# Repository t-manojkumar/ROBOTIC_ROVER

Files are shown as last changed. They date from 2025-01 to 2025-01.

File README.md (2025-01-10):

# ROBOTIC_ROVER
The project is designed to develop a Robotic Rover vehicle with  a soft holding gripper. It can be used for pick and place of an object.  It can sense whether the object picked is metallic or non-metallic. It  can also detect the rover is in gaseous surrounding or not. It can also tell the  temperature and humidity level.

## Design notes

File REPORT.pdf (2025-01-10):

1
DIPLOMA IN MECHATRONICS-NEC

## 1.0 INTRODUCTION

The project is designed to develop a Robotic Rover vehicle with

a soft holding gripper. It can be used for pick and place of an object.

It can sense whether the object picked is metallic or non-metallic. It

can also detect the rover is in gaseous surrounding or not (LPG, I-

Butane, Methane, Hydrogen, Alcohol, smoke). It can also tell the

temperature and humidity level. The robotic vehicle is controlled by

an android application for remote operation.

At the transmitting end using an Android application device,

commands are sent to the receiver to control the movement of the

robot to move forward, backward, and left or right. The android

application device transmitted acts as a remote control that has the

advantage of a certain range, while the receiver end is fed to the

micro controller to drive DC motors via motor driver IC for necessary

work. Remote operation is achieved by any smart-phone/Tablet, etc.

The main advantage of this robot is its holding arm, which is designed

to avoid extra pressure on the suspected object for safety reasons. A

Rover is the one which is used to pick up an object and place it in the

desired location. It is an articulated Robotic Rover, which contains a

fixed robot with 3 vertical axes and rotary arms.

Manipulator is the main body of the vehicle which consisting

of several joints and links

DIPLOMA IN MECHATRONICS - NEC | 2

ROBOTIC ROVER

## 2.0 PROECT BRIEF

AIM

To design and build a Robotic Rover.

OBJECTIVES

- To design a speed control system for the Robotic Rover
- Pick and place the objects using manipulator
- To implement wireless android application to control the Robotic

Rover

- To detect gases in surrounding (LPG, I-Butane, Methane, Hydro

gen, Alcohol)

- To display temperature and humidity level
- To sense whether the object is metallic or non-metallic

### 3.0 PROJECT TARGET

To create a wireless based Robotic Rover which can move an

object from one place to another place and also to an unsustainable

condition or environment.

- To Reduce the human effort
- Pick and Place the required component
- Easy to implement
- Low maintenance

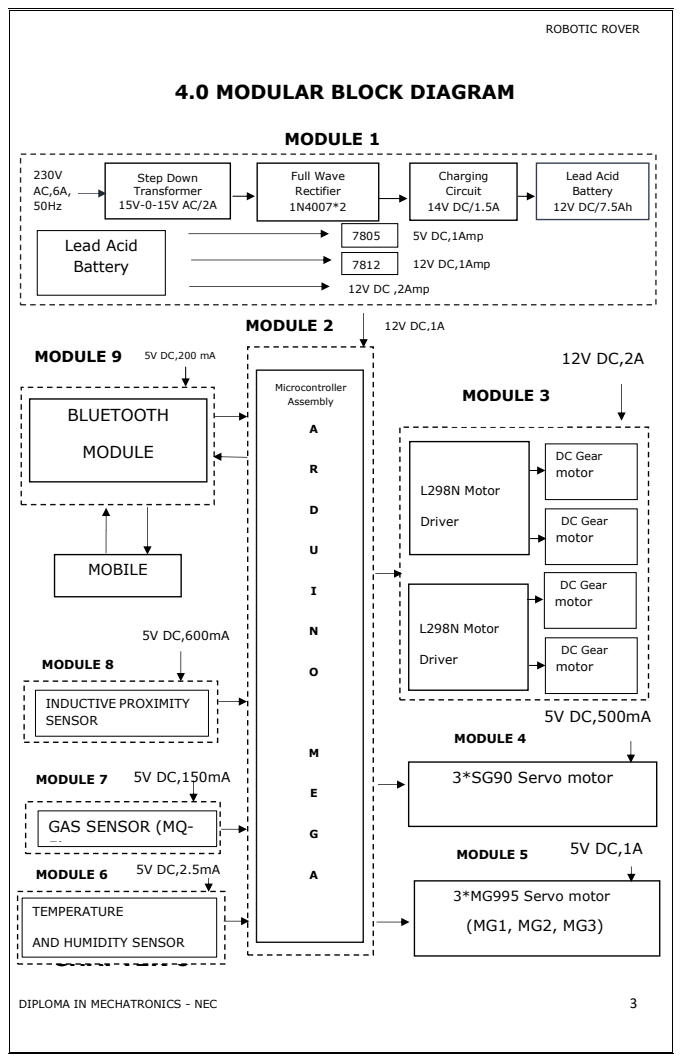
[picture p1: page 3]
DIPLOMA IN MECHATRONICS - NEC; MODULE 1; 12V DC,1Amp; Microcontroller Assembly; BLUETOOTH; MODULE; L298N Motor; Driver; 3*SG90 Servo motor; 3*MG995 Servo motor; MODULE 5; MODULE 4; MOBILE; MODULE 8; INDUCTIVE PROXIMITY SENSOR; MODULE 7; MODULE 6; TEMPERATURE; Step Down Transformer 15V-0-15V AC/2A; Full Wave Rectifier 1N4007*2; Charging Circuit 14V DC/1.5A; Lead Acid Battery 12V DC/7.5Ah; 7805 Lead Acid; Battery; 12V DC ,2Amp; 5V DC,1Amp; MODULE 9; MODULE 2; DC Gear motor; MODULE 3

4.0 MODULAR BLOCK DIAGRAM

GAS SENSOR (MQ-

AND HUMIDITY SENSOR
CHAPTER 6

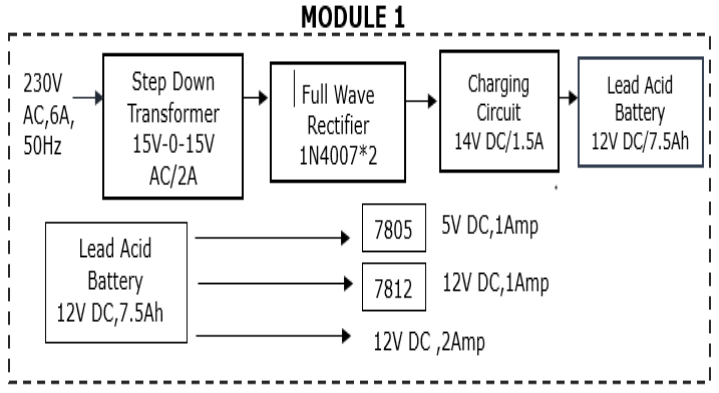
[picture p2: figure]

DIPLOMA IN MECHATRONICS - NEC | 4

## 5.0 POWER SUPPLY & CHARGING CIRCUIT

### 5.1 DESCRIPTION

Step down transformer gives 15V-0-15V/2A AC to the

center tap full wave rectifier formed by diodes D1, D2. Rectifier

will convert 30V AC to 19V DC. Capacitor C1 is introduced to filter

the ripples of converted DC, so it used as filter as well as backup

capacitor. To remove the ripple voltage. The Rectifier is connected

to the capacitors 1000uf,50V and they are connected to regulator

LM317 for regulating the voltage to 13.5v for charging the battery

and a freewheeling is used to stop the back current from the

battery to protect the circuit. In this circuit we are used auto

cutoff system to overcome the problem of overcharging.

### 5.2 BLOCK DIAGRAM

DIPLOMA IN MECHATRONICS - NEC | 5

## BLOCK DIGRAM DESCRIPTION

INPUT

The input 230V/50Hz is given to the transformer.

STEPDOWN TRNSFORMER

A Step-Down Transformer is a device which converts high

primary voltage to a low secondary voltage. In a Step-Down

Transformer, the primary winding of a coil has more turns than the

secondary winding.

CENTER-TAP FULL WAVE RECTIFIER

A Full Wave Rectifier is a circuit, which converts an ac

voltage into a pulsating dc voltage using both half cycles of the

applied ac voltage. It uses two diodes of which one conducts during

one half cycle while the other conducts during the other half cycle of

the applied ac voltage.

FILTER

The pulsating output of the rectifiers has an average DC

value and an AC portion that is called ripple voltage. Filter capacitors

reduce the amount of ripple voltage to a level that is acceptable.

REGULATOR

We are using regulator ICs to maintain a constant output

voltage in a power supply circuit. We are using regulator IC LM317

for getting 13V respectively through variable resistor to this we are

connected to the battery.

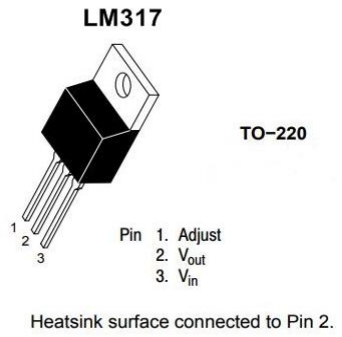
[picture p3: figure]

DIPLOMA IN MECHATRONICS - NEC | 6

For 12V,1Amp supply we are using 7812 for getting 12V

respectively, and for 5V,1Amp supply we are using 7805 for getting

5V respectively.

LM317

The LM317 is an adjustable 3−terminal positive voltage

regulator capable of supplying in excess of 1.5 A over an output

voltage range of 1.2 V to 37 V. This voltage regulator is exceptionally

easy to use and requires only two external resistors to set the output

voltage.

Features

- Output Voltage Range Adjustable From 1.25 V to 37 V
- Output Current Greater Than 1.5 A
- Internal Short-Circuit Current Limiting
- Thermal Overload Protection
- Output Safe-Area Compensation

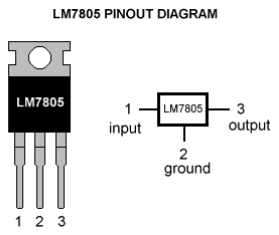
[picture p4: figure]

DIPLOMA IN MECHATRONICS - NEC | 7

LM7805

7805 is a 5V fixed three terminal positive voltage regulator IC.

The IC has features such as safe operating area protection, thermal

shut down, internal current limiting which makes the IC very rugged.

Output currents up to 1A can be drawn from the IC provided that

there is a proper heat sink.

Features

- 5V Positive Voltage Regulator
- Minimum Input Voltage is 7V
- Maximum Input Voltage is 25V
- Operating current (IQ) is 5mA
- Internal Thermal Overload and Short circuit current limiting

protection is available.

- Junction Temperature maximum 125 degree Celsius
- Available in TO-220 and KTE package

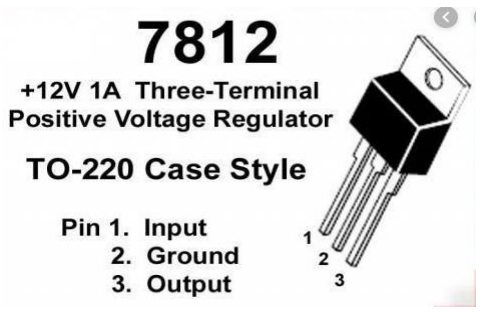
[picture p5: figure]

DIPLOMA IN MECHATRONICS - NEC | 8

LM7812

7812 is a 12V fixed three terminal positive voltage

regulator IC. The IC has features such as safe operating area

protection, thermal shut down, internal current limiting which makes

the IC very rugged. Output currents up to 1A can be drawn from the

IC provided that there is a proper heat sink.

Features

- Fixed voltage linear regulator
- 14-35V input voltage range
- 12V fixed output voltage
- 1A continuous current
- TO-220 package

Output:

The output of power supply is 12VDC/1A.

The output of power supply is 5 VDC/1A.

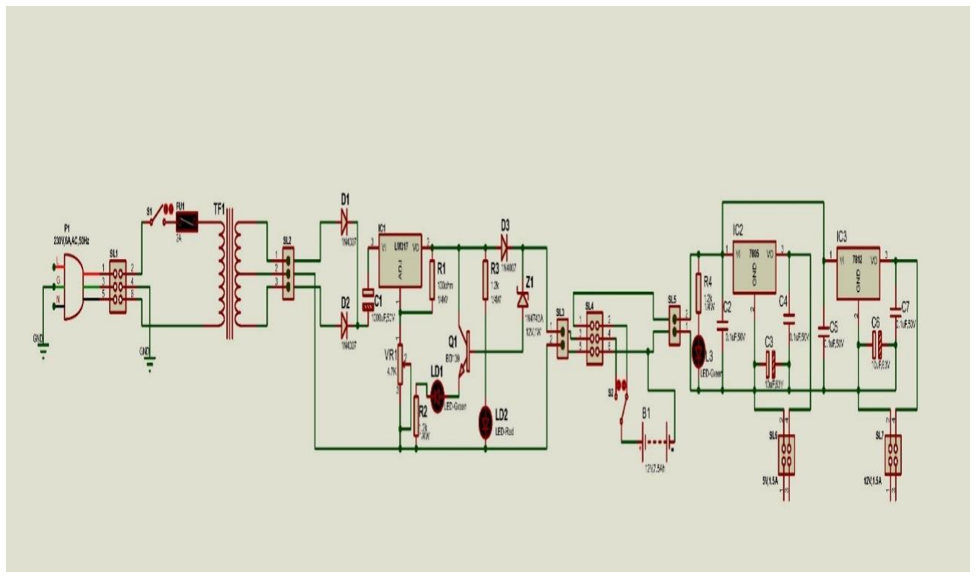
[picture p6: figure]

DIPLOMA IN MECHATRONICS - NEC | 9

## 5.3 SCHEMATIC DIAGRAM

## 5.4 DESIGN

CHARGING CIRCUIT REQUIREMENTS:

Voltage = 15V DC

Current = 1A

TRANSFORMER SPECFICATION:

Voltage =15V-0-15V AC

Current =2A

DIPLOMA IN MECHATRONICS - NEC | 10

For Center Tap Full Wave Rectifier:

VDC = Pulsating DC Voltage (Volts)

Vmax = V peak Voltage (Volts)

VDC = 2xVmax/ϖ

VDC =0.636xVmax

VDC =0.636x30

VDC=19.108V

As per the data sheet the Diode is 1N4007

Iout = Output Current (Amp)

Iout = 1A

In center tap full wave rectifier the frequency gets double

F=2 x F

Value of the capacitor:

C = Iout/F x Vripple

Vripple =20% of VDC

C = 1Amp/100HzX0.95

C = 950 µf

C =~ 1000 µf

DIPLOMA IN MECHATRONICS - NEC | 11

Working Voltage of Capacitor:

V1 = Operating /Working Voltage

V1 =DC Voltage +25% (extra 25% for reduce the ripple voltage)

= 19+4.75

= 23.75

= 24V

Capacitor standard Voltage we are consider 50V

V1=50V

VOLTAGE REGULATOR LM317:

Consider:

Vin = 19V

Vout = Output Voltage(Volts)

R1=100 Ω

R2=70 Ω

Vout = 1.25 (R1/R1+R2) Vin

= 1.25(100Ω/100 Ω +70 Ω) Vin

= 1.25(100Ω/100 Ω +70 Ω) X19V

= 1.25 X 11,1764

= 13.97V

Vout=~14V

DIPLOMA IN MECHATRONICS - NEC | 12

For R2, R3, R4 (Ohm’s Law)

R = V/I

R = 14/20mA

R = 0.7 X 1000

R = 700 Ω

Power Rating for Resistor:

I = 20mA

V = 14V

P = V x I

= 14(20mA)

= 280 x 10^-3

= 0.28 W

P =~0.25W

For Heatsink:

PD = (Vin-Vout) X I out

PD = power dissipation (Watt)

Vin = Input voltage (Volts)

Vout = output voltage (Volts)

Iout = output current (Amp)

DIPLOMA IN MECHATRONICS - NEC | 13

PD = (19-14V) X 1Amp

= 5W

θJA = Total junction to ambient thermal resistance (˚C/W)

TJ =Junction temperature (˚C)

TA = Ambient temperature (˚C)

θJA (total) = TJ-TA/PD

= 125˚C -23 ˚C/5W

= 102/5W

θJA=20.4 ˚C/W

DIPLOMA IN MECHATRONICS - NEC | 14

## 5.5 BILL OF MATERIALS

MODULES

Sl.no | Item description | Symbol | Qty | Price(₹)
| (i) 3 core patch chord 230V AC,6A,50Hz | P1 | 1 | 50
| (ii) Connector 6 pin Poly carbonate,10A | SL1, SL4 | 2 | 12
| (iii) Connector 3 pin Poly carbonate,10A | SL2 | 1 | 3
| (iv) Connector 2 pin Poly carbonate,5A | SL3, SL5, SL6, SL7 | 4 | 8
| (v) Switch (Rocker SPST) 230V AC,6A | S1 | 1 | 20
| (vi)Fuse & Fuse holder (Glass Catridge Fuse 2A, Fuse holder round screw,6A, AC) | FU1 | 1 | 50

Module 1

(Power

Supply &

Charging

Circuit)

DIPLOMA IN MECHATRONICS - NEC | 15
(vii) Transformer Center Tap (15-0-15)V AC,2A | TF1 | 1 | 250
(viii) Diode: 1N4007 Axial Type | D1, D2, D3 | 3 | 9
(ix)Electrolytic Capacitor (50V,1000uf) Radial Type | C1 | 1 | 8
(x) Carbon film Resistor (10k,1/4W CFR, ±5%) | R1, R2, R3, R4 | 4 | 4
(xi) Trimpot (10k,1/2W) | VR1 | 1 | 10
(xii)LM317 | IC1 | 1 | 15
(xiii) Heat sink: E3A-T220-25E | - | 3 | 45
(xiv) NPN Transistor: BD139 | Q1 | 1 | 10
(xv) Zener Diode: 1N4742 Axial Type | Z1 | 1 | 2
(xvi) LED 5mm radial type (3V,20mA) | LD1, LD2, LD3 | 3 | 10

DIPLOMA IN MECHATRONICS - NEC | 16
(xvii) Lead Acid Battery (12V,7.5Ah) | B1 | 1 | 700
(xviii)Ceramic Capacitor (104) Radial Type (50V,0.1uf) | C2, C4, C5, C7 | 4 | 4
(xix) Electrolytic Capacitor (63V,10uf) Radial Type | C3, C6 | 2 | 12
(xx) DC +ve Regulator 7805,1A | IC2 | 1 | 10
(xxi) DC +ve Regulator 7812,1A | IC3 | 1 | 10
(xxii) Toggle switch: SPDT, SDT-106D-0-1(6A,125VAC) | S2 | 1 | 30
TOTAL | | | 1282

DIPLOMA IN MECHATRONICS - NEC | 17

## 6.0 MICROCONTROLLER ASSEMBLY MODULE

## 6.0 ARDUINO MEGA 2560

### 6.1 DESCRIPTION

The Arduino MEGA 2560 is designed for projects that require

more I/O lines, more sketch memory and more RAM. With 54 digital

I/O pins, 16 analog inputs and a larger space for your sketch it is the

recommended board for 3D printers and robotics projects. The

Arduino Mega 2560 is programmed using the software (IDE) our

Integrated Development Environment common to all our boards and

running both online and offline.

### 6.2 FEATURES OF ARDUINO MEGA 2560

- The ATmega2560 is a Microcontroller
- The operating voltage of this microcontroller is 5volts
- The recommended Input Voltage will range from 7volts to 12volts
- The input voltage will range from 6volts to 20volts
- The digital input/output pins are 54 where 15 of these pins will

supply PWM o/p.

- Analog Input Pins are 16
- DC Current for each input/output pin is 40 mA
- DC Current used for 3.3V Pin is 50 mA
- Flash Memory like 256 KB where 8 KB of flash memory is used with

the help of bootloader

- The static random access memory (SRAM) is 8 KB
- | The | electrically | erasable | programmable | read-only | memory

(EEPROM) is 4 KB

- The clock (CLK) speed is 16 MHz
- The USB host chip used in this is MAX3421E

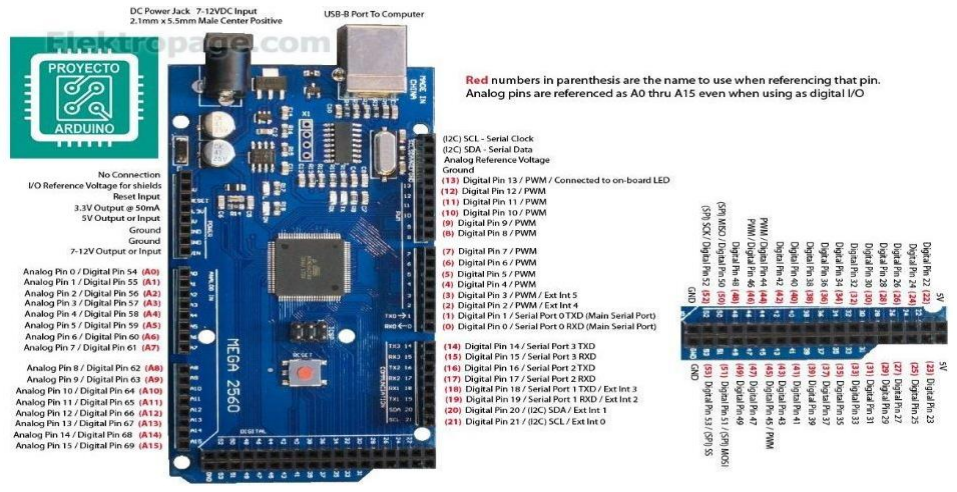
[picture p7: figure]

DIPLOMA IN MECHATRONICS - NEC | 18

### 6.3 PIN CONFIGURATION:

PIN DIAGRAM EXPANATION:

POWER PINS:

VIN: The input voltage to the Arduino board when it's using an

external power source can supply voltage through this pin, or, if

supplying voltage via the power jack, access it through this pin.

5V: The regulated power supply used to power the microcontroller

and other components on the board. This can come either from VIN

via an on-board regulator, or be supplied by USB or another

regulated 5V supply.

3V3: A 3.3 volt supply generated by the on-board regulator.

Maximum current draw is 50 mA.

GND: Ground pins.

MEMORY:

The ATmega2560 has 256 KB of flash memory for storing code of

which 8 KB is used for the bootloader, 8 KB of SRAM and 4 KB of

EEPROM

DIPLOMA IN MECHATRONICS - NEC | 19

INPUT AND OUTPUT

Each of the 54 digital pins on the Mega can be used as an input or

output, using pinMode(), digitalWrite(), and digitalRead() functions.

They operate at 5 volts. Each pin can provide or

receive a maximum of 40 mA and has an internal pull-up resistor

of 20-50 kOhms. In addition, some pins have specialized functions

- Serial: 0 (RX) and 1 (TX); Serial 1: 19 (RX) and 18 (TX);

Serial 2: 17 (RX) and 16 (TX); Serial 3: 15 (RX) and 14 (TX).

Used to receive (RX) and transmit (TX) TTL serial data. Pins 0 and 1

are also connected to the corresponding pins of the ATmega8U2 USB-

to-TTL Serial chip.

- External Interrupts: 2 (interrupt 0), 3 (interrupt 1), 18

(interrupt 5),19 (interrupt 4), 20 (interrupt 3), and 21

(interrupt 2). These pins can be configured to trigger an interrupt

on a low value, a rising or falling edge, or a change in value. See the

attachInterrupt() function for details.

- PWM: 0 to 13. Provide 8-bit PWM output with the analogWrite()

function.

- SPI: 50 (MISO), 51 (MOSI), 52 (SCK), 53 (SS).

These pins support SPI communication using the SPI library. The SPI

pins are also broken out on the ICSP header, which is physically

compatible with the Uno, Duemilanove and Diecimila.

- LED: 13. There is a built-in LED connected to digital pin 13. When

the pin is HIGH value, the LED is on, when the pin is LOW, it's off.

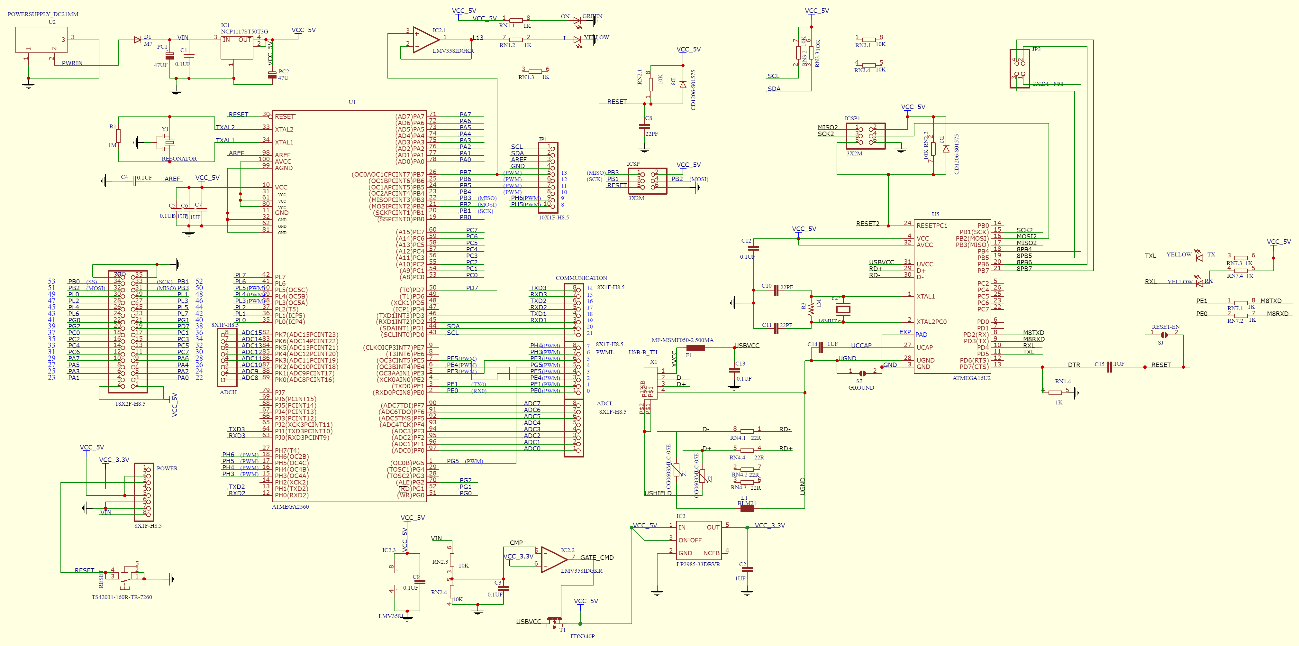
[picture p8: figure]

DIPLOMA IN MECHATRONICS - NEC | 20
- I2C: 20 (SDA) and 21 (SCL). Support I2C (TWI) communication

using the Wirelibrary.

The Mega2560 has 16 analog inputs, each of which provide 10 bits of

resolution. By default they measure from ground to 5 volts, though is

it possible to change the upper end of their range using the AREF pin

and analogReference() function.

There are a couple of other pins on the board:

- AREF. Reference voltage for the analog inputs. Used with

analogReference().

- Reset. Bring this line LOW to reset the microcontroller. Typically

used to add a reset

button to shields which block the one on the board.

### 6.4 SCHEMATIC DIAGRAM:

DIPLOMA IN MECHATRONICS - NEC | 21

### 6.5 BILL OF MATERIAL

SL NO | Item description | symbol | Qty | Price(₹)
1 | ATMEGA2560 | U1 | 1 | 27
2 | POWERSUPPLY_DC21MM | U2 | 1 | 19
| 47UF | PC1 | 1 | 3
4 | 0.1UF | C1, C4, C5, C6, C7, C3, C9, C12, C13, C15 | 10 | 7
5 | RESONATOR | Y1 | 1 | 5
6 | NCP1117ST50T3G | IC1 | 1 | 6
7 | 1M | R1, R3 | 2 | 3
8 | M7 | D1 | 1 | 6
9 | 18X2F-H8.5 | XIO | 1 | 6
10 | 8X1F-H8.5 | POWER, ADCH, COMMUNICATION, PWML, ADCL | 5 | 20
11 | TS42031-160R-TR-7260 | RESET | 1 | 5
12 | 10X1F-H8.5 | JP1 | 1 | 6

DIPLOMA IN MECHATRONICS - NEC | 22
13 | CD1206-S01575 | D3, D2 | 2 | 8
14 | 22PF | C8, C10, C11 | 3 | 3
15 | 3X2M | ICSP, ICSP1 | 2 | 8
16 | 1UF | C2, C14 | 2 | 2
17 | LP2985-33DBVR | IC3 | 1 | 9
18 | FDN340P | T1 | 1 | 50
19 | 2X2M – NM | JP2 | 1 | 33
20 | 16MHZ | Y2 | 1 | 19
21 | USB-B_TH | X1 | 1 | 80
22 | MF-MSMF050-2 500MA | F1 | 1
23 | CG0603MLC-05E | Z1, Z2 | 2 | 49
24 | BLM21 | L1 | 1 | 12
25 | SJ | GROUND, RESET-EN | 2 | 30
26 | ATMEGA16U2 | U5 | 1 | 16
27 | 47U | PC2 | 1 | 17

DIPLOMA IN MECHATRONICS - NEC | 23
28 | GREEN | ON | 1 | 2
29 | YELLOW | L, TX, RX | 3 | 2
30 | 1u (https://easyeda.com/component/994f4acf33ff4e66aaa5dbbeb5e3fa4f) | C16, C18 | 2 | 1
31 | 1u (https://easyeda.com/component/73cf4db60ff344f8a415b734dfaec7a1) | C17, C19 | 2 | 2
32 | 1N4448 (https://easyeda.com/component/1f840c1ab0fc8dd5c06f5170f6febdd2) | D4, D5 | 2 | 8
33 | 1k (https://easyeda.com/component/5ba509f895244278a1309c0031b47188) | R2, R4 | 2 | 2
34 | Оптопара (https://easyeda.com/component/901765d22a3f4b5bbb75a09bf7adf945) | U3, U4 | 2 | 26
35 | BC847AWT1G (https://easyeda.com/component/1e5139edd73d4da4b58b2ce887ac698c) | Q1, Q2 | 2 | 50
36 | LMV358IDGKR | IC2 | 1 | 69
37 | 1K | RN1, RN7 | 2 | 12
38 | 10K | RN2, RN3 | 2 | 12
39 | 22R | RN4 | 1 | 12
TOTAL | | | 700

DIPLOMA IN MECHATRONICS - NEC | 24

## 7.0 JOHNSON MOTOR WITH L298N MOTOR

## DRIVER

### 7.1 DESCRIPTION

L298N MOTOR DRIVER

This dual bidirectional motor driver, is based on the very

popular L298 Dual H-Bridge Motor Driver Integrated Circuit. The circuit

will allow you to easily and independently control two motors of up to

2A each in both directions. It is ideal for robotic applications and well

suited for connection to a microcontroller requiring just a couple of

control lines per motor. It can also be interfaced with simple manual

switches, TTL logic gates, relays, etc. This board equipped with power

LED indicators, on-board +5V regulator and protection diodes.

FEATURES

- Input Voltage: 3.2V~40Vdc. Brief Data:
- Driver: L298N Dual H Bridge DC Motor Driver
- Power Supply: DC 5 V - 35 V
- Peak current: 2 Amp
- Operating current range: 0 ~ 36mA
- Low: -0.3V ≤ Vin ≤ 1.5V.
- High: 2.3V ≤ Vin ≤ Vss.
- Maximum power consumption: 20W (when the temperature

T = 75 ℃).

DIPLOMA IN MECHATRONICS - NEC | 25

JOHNSON MOTOR:

It is a simple DC motor (https://robu.in/product-category/motor/) featuring metal gearbox for driving the

shaft of the motor, so it is a mechanically commutated electric motor

which is powered from DC supply. The Johnson Geared Motors (https://robu.in/product-tag/johnson-motor/) are

known for their compact size and massive torque-speed characteristic.

The Johnson Motor (https://robu.in/product-tag/johnson-motor/) comes with side shaft also known as an off-

centered shaft and six M3 mounting holes. The shaft of the motor

equips metal bushes which makes these DC gear motors Shaft wear

resistant. The shaft of the motor has a hole for better coupling.

FEATURES:

- 10RPM 12V DC motors with Metal Gearbox and Metal Gears
- 18000 RPM base motor
- 6mm Dia shaft with M3 thread hole
- Gearbox diameter 37 mm.
- Motor Diameter 28.5 mm
- Length 63 mm without shaft
- Shaft length 30mm
- 180gm weight
- 120kgcm Holding Torque
- No-load current = 800 mA, Load current = upto 7.5 A(Max)
- Recommended to be used with DC Motor Driver 20A (https://robokits.co.in/shop/index.php?main_page=product_info&cPath=73&products_id=334) or Dual DC

Motor Driver 20A (https://robokits.co.in/shop/index.php?main_page=product_info&cPath=73&products_id=342)

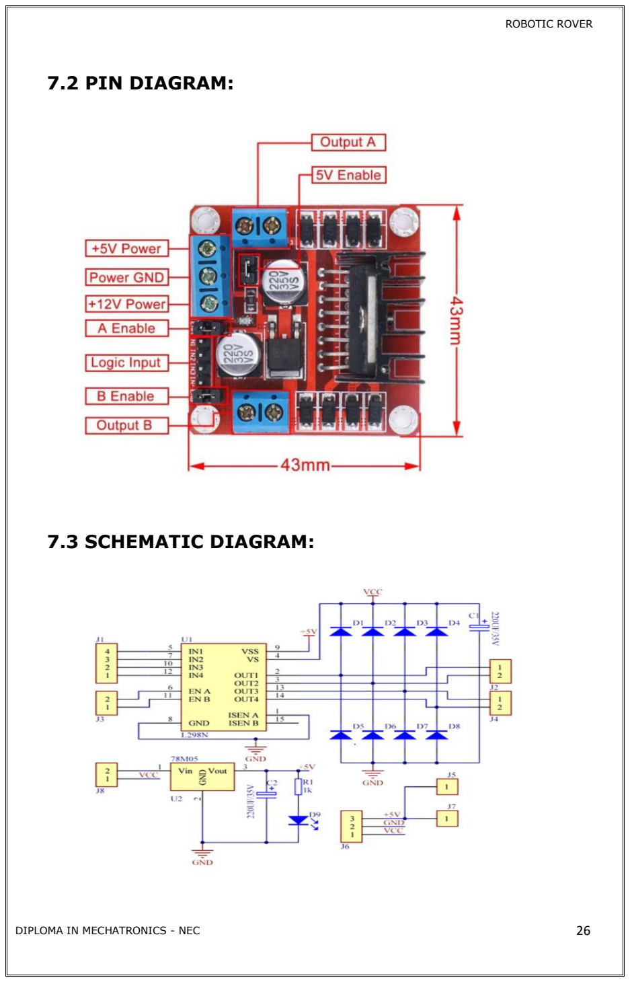
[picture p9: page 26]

DIPLOMA IN MECHATRONICS - NEC | 26

### 7.2 PIN DIAGRAM:

### 7.3 SCHEMATIC DIAGRAM:

DIPLOMA IN MECHATRONICS - NEC | 27

### 7.4 BILL OF MATERIALS:

SL.NO | Item Description | Symbol | Qty | Price (₹)
1 | L298 | U2 | 1 | 20
2 | L297DIL20-1 | U1 | 1 | 5
3 | KF301-5.0 2P | J3, J4, J5, J6, J7, J8 | 5 | 20
4 | LM7805EE | U3 | 1 | 50
5 | 470uf | C1 | 1 | 2
6 | 220uf | C2 | 1 | 2
7 | PIN 3 | J1, J2 | 2 | 10
8 | 10k | R1, R2 | 2 | 2
9 | CAP 0805 | C4, C3 | 2 | 8
10 | 22uf | C5 | 1 | 2
11 | 1N4007 | D1, D2, D3, D4, D5, D6, D7, D8 | 8 | 15
12 | 1 Ohm | R4, R10 | 2 | 3
13 | 22k | R5, R7 | 2 | 3
14 | 332 uf | C7 | 1 | 3
15 | 5kOhm | R6 | 1 | 2
TOTAL | | | | 147

DIPLOMA IN MECHATRONICS - NEC | 28

TOTAL BILL OF MATERIALS:

SL.NO | Item Description | Symbol | Qty | Price (₹)
1 | Motor Driver (L298N) | L1 | 1 | 147
2 | Johnson Motor | M1 | 1 | 150
TOTAL | | | | 297

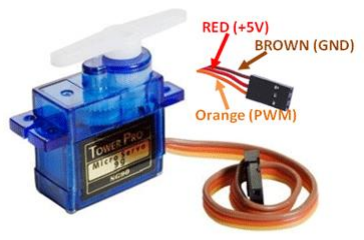
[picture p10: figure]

DIPLOMA IN MECHATRONICS - NEC | 29

## 8.0 SG-90 SERVO MOTOR

### 8.1 DESCRIPTION

The TowerPro SG90 9g Mini Servo is 180° rotation servo. It is a

Digital Servo Motor which receives and processes PWM signal faster

and better. It equips sophisticated internal circuitry that provides good

torque, holding power, and faster updates in response to external

forces.

### 8.2 PIN DIAGRAM:

### 8.3 FEATURES

- Operating Voltage is +5V typically
- Torque: 2.5kg/cm
- Operating speed is 0.1s/60°
- Gear Type: Plastic
- Rotation: 0°-180°
- Weight of motor: 9gm

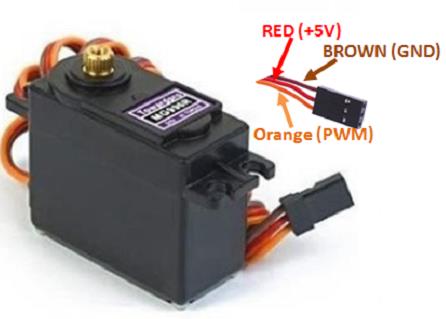
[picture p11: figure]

DIPLOMA IN MECHATRONICS - NEC | 30

### 8.4 BILL OF MATERIALS

SL.NO | Item Description | Symbol | Qty | Price (₹)
1 | Servo Motor (SG-90) | SM1, SM2 | 2 | 150X2
TOTAL | | | | 300

*

## 9.0 MG995 SERVO MOTOR

### 9.1 DESCRIPTION

The high-speed standard servo can rotate approximately 120

degrees (60 in each direction). We can use any servo code, hardware

or library to control these servos, so gear box, especially since it will fit

in small places. It equips sophisticated internal circuitry that provides

good torque, holding power, and faster updates in response to external

forces.

### 9.2 PIN DIAGRAM

DIPLOMA IN MECHATRONICS - NEC | 31

PIN CONFIGURATION:

MG995 has three terminals as mentioned in pin diagram and the function of each pin is given below.

Pin | Name | Function
1 | Signal pin (Orange pin) | The PWM signal which states the axis position is given through this pin.
2 | VCC (Red pin) | Positive power supply for servo motor is given to this pin.
3 | Ground (Brown pin) | This pin is connected to ground of circuit or power supply.

### 9.3 FEATURES:

- Weight: 55g
- Dimension: 40.7 × 19.7 × 42.9 mm
- Operating Speed (4.8V no load): 20sec / 60 deg
- Operating Speed (6.0V no load): 16sec / 60 deg (no load)
- Stall Torque (4.8V): 10kg/cm
- Stall Torque (6.0V): 12kg/cm
- Operation Voltage: 4.8 - 7.2Volts
- Gear Type: All Metal Gears
- Stable and shock proof double ball bearing design
- Dead band width: 5 µs
- Temperature range: 0 ºC – 55 ºC.

DIPLOMA IN MECHATRONICS - NEC | 32

### 9.4 BILL OF MATERIALS

SL.NO | Item Description | Symbol | Qty | Price (₹)
1 | Servo Motor (MG-995) | SM3, SM4, SM5 | 3 | 200X3
TOTAL | | | | 600

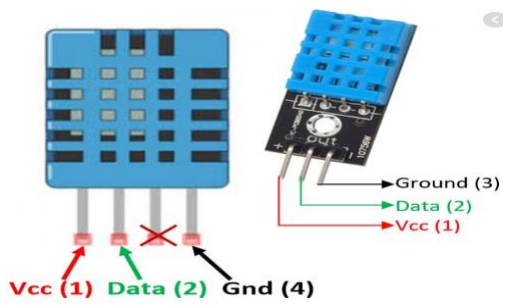
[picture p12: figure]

DIPLOMA IN MECHATRONICS - NEC | 33

## 10.0 DHT11 (TEMPERATURE AND HUMIDITY

## SENSOR)

### 10.1 DESCRIPTION:

It uses a capacitive humidity sensor and a thermistor to

measure the surrounding air, and spits out a digital signal on the data

pin. The only real downside of this sensor is you can only get new

data from it once every 2 Sec. This sensor includes a resistive-type

humidity measurement component and an NTC temperature

measurement component, and connects to a high-performance 8-bit

microcontroller, offering excellent quality, fast response, anti-

interference ability and cost-effectiveness. Each DHT11 element is

strictly calibrated in the laboratory that is extremely accurate on

humidity calibration. The calibration coefficients are stored as

programs in the OTP memory, which are used by the sensor’s internal

signal detecting process. The single-wire serial interface makes

system integration quick and easy. Its small size, low power

consumption and upto 20-meter signal transmission making it the

best choice for various applications, including those most demanding

ones.

### 10.2 PIN DIAGRAM:

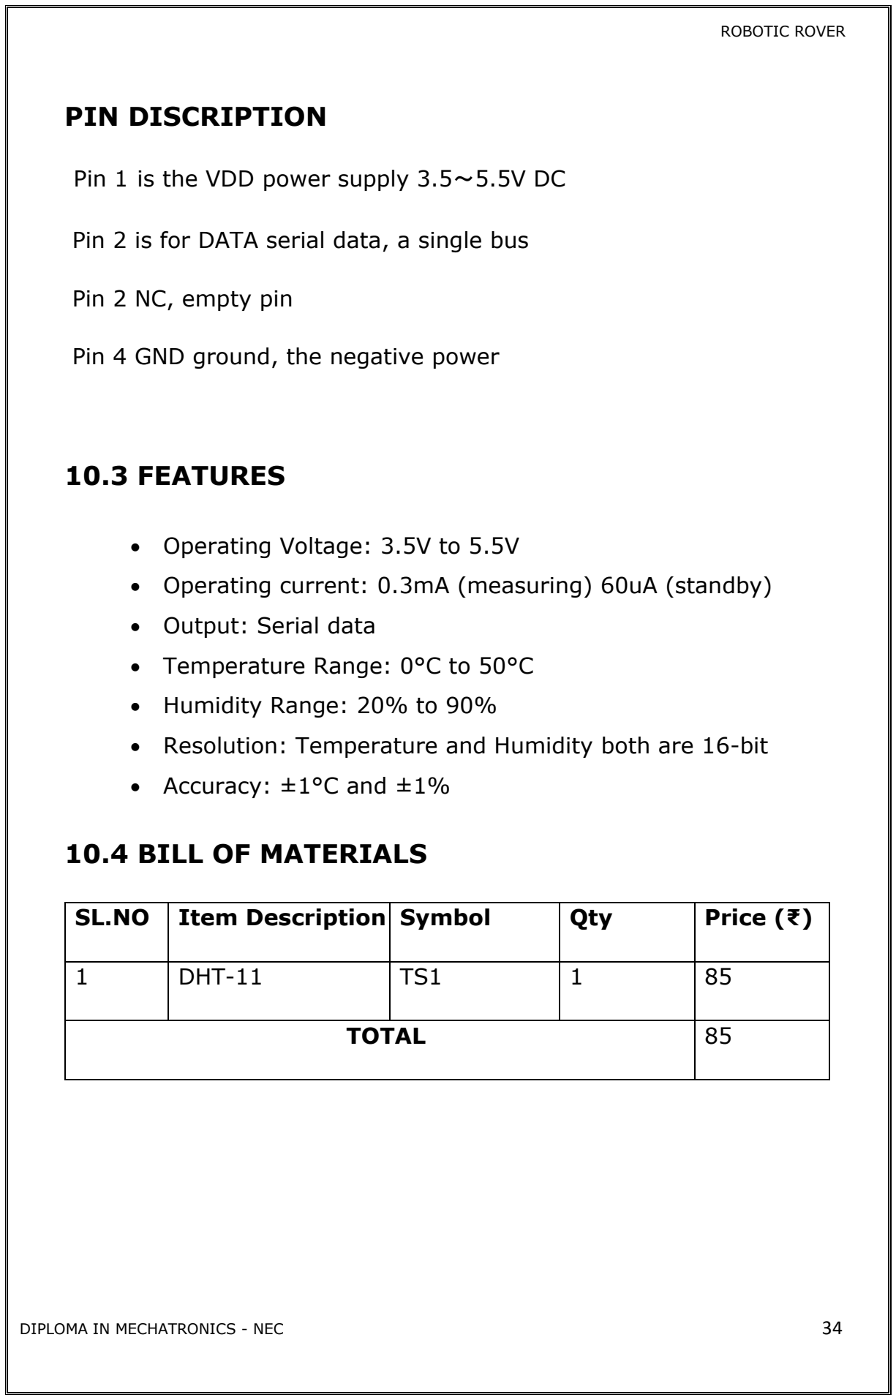
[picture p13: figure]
DIPLOMA IN MECHATRONICS - NEC; PIN DISCRIPTION; Pin 2 NC, empty pin; Pin 4 GND ground, the negative power; 10.3 FEATURES; • Operating Voltage: 3.5V to 5.5V; • Output: Serial data; • Temperature Range: 0°C to 50°C; • Humidity Range: 20% to 90%; • Accuracy: ±1°C and ±1%; 10.4 BILL OF MATERIALS; Item Description; Symbol; Qty; Price (₹); DHT-11; TOTAL

Pin 1 is the VDD power supply 3.5～5.5V DC

Pin 2 is for DATA serial data, a single bus

- Operating current: 0.3mA (measuring) 60uA (standby)
- Resolution: Temperature and Humidity both are 16-bit

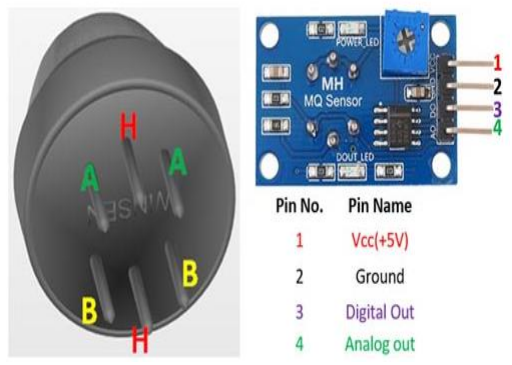
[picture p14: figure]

DIPLOMA IN MECHATRONICS - NEC | 35

## 11.0 MQ-5 (GAS SENSOR)

### 11.1 DESCRIPTION

The MQ5 Gas Sensor module is useful for gas leakage

detecting. It can detect LPG, i-butane, methane, alcohol, Hydrogen,

CO2. The sensitivity can be adjusted using the on-board

potentiometer, and you'd use this sensor by reading the analog pin to

which it is connected.

### 11.2 PIN DIAGRAM

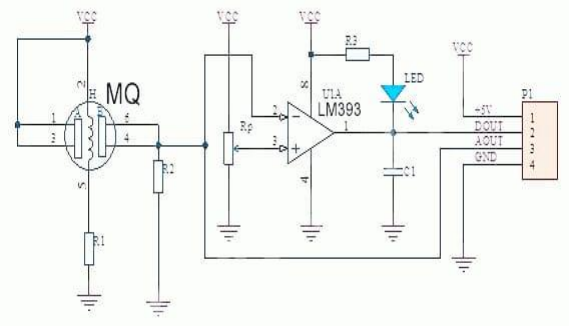
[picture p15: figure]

DIPLOMA IN MECHATRONICS - NEC | 36

### 11.3 SCHEMATIC DIAGRAM:

### 11.4 BILL OF MATERIALS

SL.NO | Item Description | Symbol | Qty | Price (₹)
1 | LM393, Boost Converter | U1 | 1 | 10
2 | 2.7M ohm | R1 | 1 | 2
3 | 910K ohm | R2 | 1 | 2
4 | 10uH | L1 | 1 | 13
5 | 100uf | C1 | 1 | 2
6 | 100uf | C2 | 1 | 2

DIPLOMA IN MECHATRONICS - NEC | 37
7 | 100nf | C3 | 1 | 2
8 | 1N5819, LED | D1 | 1 | 5
9 | HDR2X3 | P1 | 1 | 5
10 | LM393 | U2 | 1 | 40
11 | LED | D2, D3 | 2 | 3
12 | 1uf | C4 | 1 | 3
13 | 1k ohm | R3, R4 | 2 | 3
14 | SIP4 | P2 | 1 | 2
15 | 4.7k ohm | R5 | 1 | 2
16 | 5R1 ohm | R6 | 1 | 2
17 | 100k ohm | R7 | 1 | 2
TOTAL | | | | 100

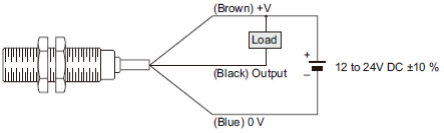
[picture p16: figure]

DIPLOMA IN MECHATRONICS - NEC | 38

## 12.0 INDUCTIVE PROXIMITY SENSOR

### 12.1 DESCRIPTION

An inductive sensor is a device that uses the principle

of electromagnetic induction (https://en.wikipedia.org/wiki/Electromagnetic_induction) to detect or measure objects. An

inductor develops a magnetic field when a current flow through it;

alternatively, a current will flow through a circuit containing an

inductor when the magnetic field through it changes. This effect can

be used to detect metallic objects that interact with a magnetic field.

Non-metallic substances such as liquids or some kinds of dirt do not

interact with the magnetic field.

### 12.2 PIN DIAGRAM

### 12.3 FEATURES

- Red LED checks the state of the proximity sensor
- High repeated positioning accuracy
- High switching frequency
- Wide voltage range
- Outer (Thread) Diameter: M12
- Antivibration, dust, water and oil prevention

DIPLOMA IN MECHATRONICS - NEC | 39

### 12.4 BILL OF MATERIALS

SL.NO | Item Description | Symbol | Qty | Price (₹)
1 | Inductive Proximity Sensor | IP1 | 1 | 200
TOTAL | | | | 200

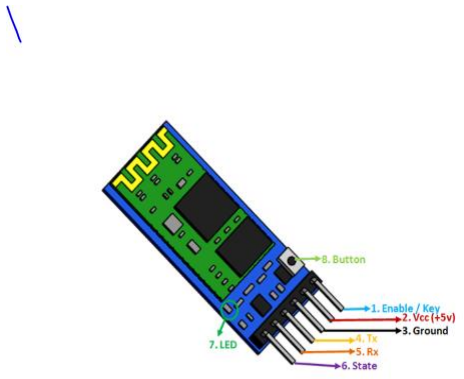
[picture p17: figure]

DIPLOMA IN MECHATRONICS - NEC | 40

## 13.0 BLUETOOTH MODULE(HC-05)

### 13.1 DESCRIPTION

The HC-05 has two operating modes, one is the Data mode

in which it can send and receive data from other Bluetooth devices and

the other is the AT Command mode where the default device settings

can be changed. We can operate the device in either of these two

modes by using the key pin as explained in the pin description.

It is very easy to pair the HC-05 module with microcontrollers

because it operates using the Serial Port Protocol (SPP). Simply

power the module with +5V and connect the Rx pin of the module to

the Tx of MCU and Tx pin of module to Rx of MCU as shown in the

figure below

### 13.2 PIN DIAGRAM

DIPLOMA IN MECHATRONICS - NEC | 41

### 13.3 FEATURES

- Serial Bluetooth module for Arduino (https://components101.com/microcontrollers/arduino-uno) and other microcontrollers
- Operating Voltage: 4V to 6V (Typically +5V)
- Operating Current: 30mA
- Range: <100m
- Works with Serial communication (USART) and TTL compatible
- Follows IEEE 802.15.1 standardized protocol
- Uses Frequency-Hopping Spread spectrum (FHSS)

### 14.4 BILL OF MATERIALS

SL.NO | Item Description | Symbol | Qty | Price (₹)
1 | BLUETOOTH MODULE | BL1 | 1 | 250
TOTAL | | | | 250

## 14.0 MECHANICAL DESIGN

## 14.1 OVERALL ISOMETRIC VIEW

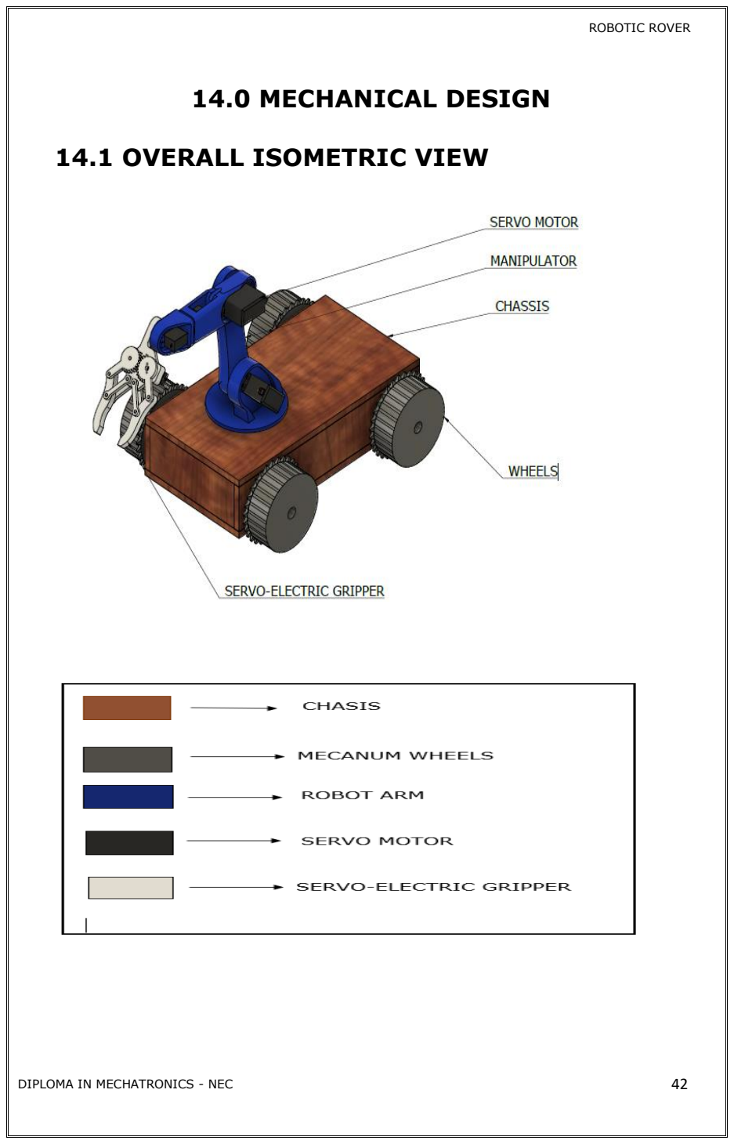
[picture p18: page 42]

DIPLOMA IN MECHATRONICS - NEC | 42

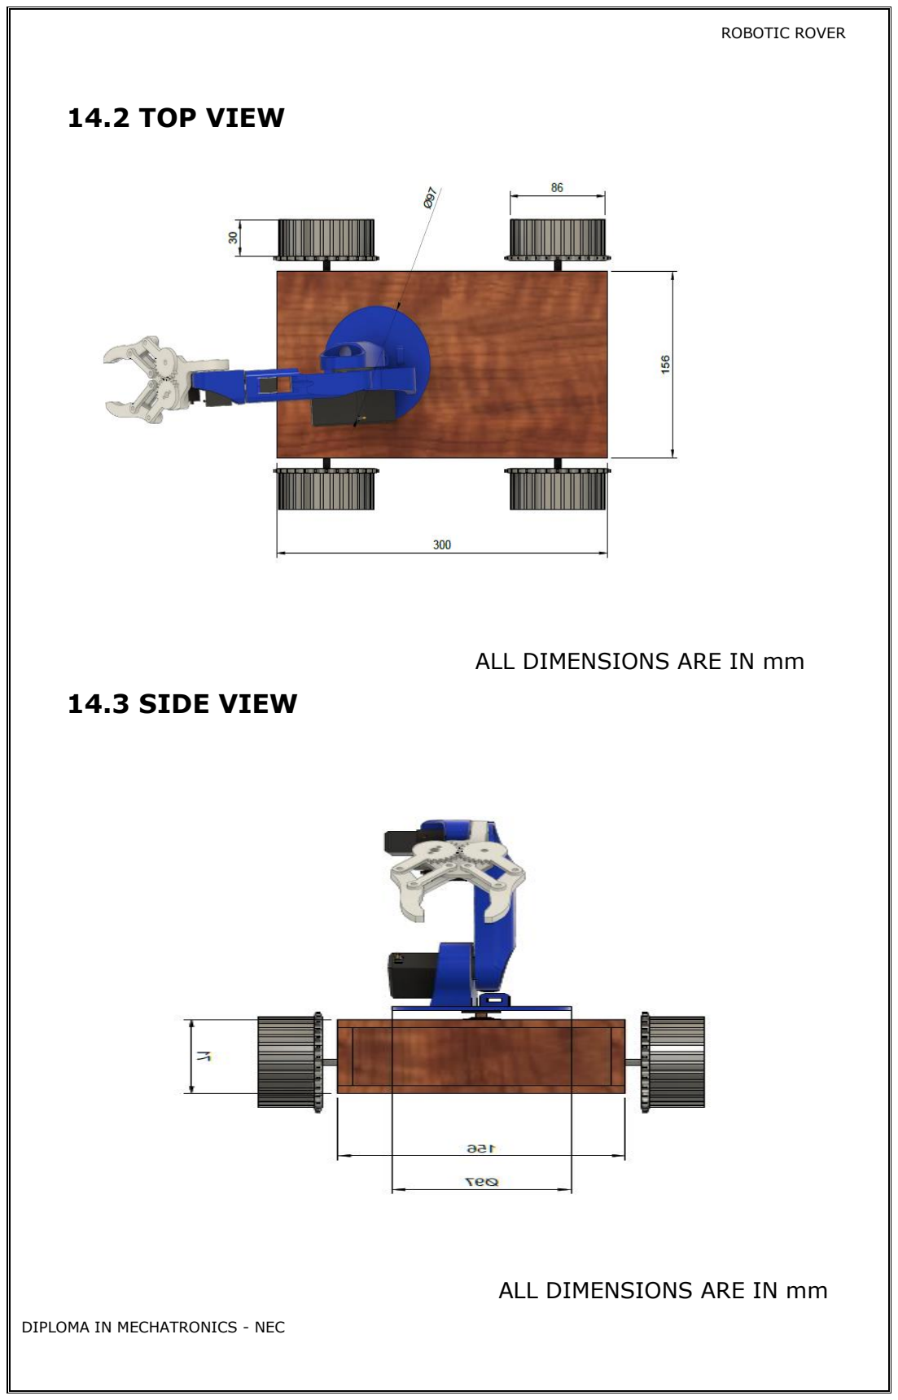
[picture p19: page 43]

DIPLOMA IN MECHATRONICS - NEC | 43

ALL DIMENSIONS ARE IN mm

### 14.2 TOP VIEW

### 14.3 SIDE VIEW

ALL DIMENSIONS ARE IN mm

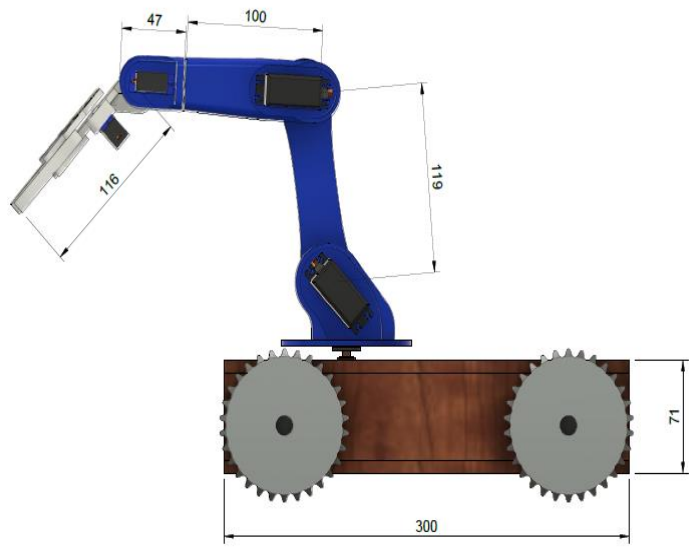
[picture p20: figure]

DIPLOMA IN MECHATRONICS - NEC | 44

### 14.4 FRONT VIEW

ALL DIMENSIONS ARE IN mm

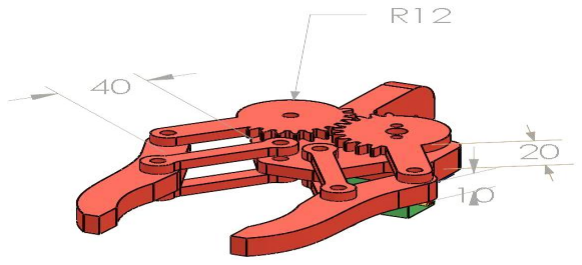
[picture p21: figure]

DIPLOMA IN MECHATRONICS - NEC | 45

### 14.5 SERVO ELECTRIC-GRIPPER

ALL DIMENSIONS ARE IN mm

DIPLOMA IN MECHATRONICS - NEC | 46

## 15.0 BILL OF MATERIAL

### 15.1 MODULES

Sl.no | Modules | Individual Price (₹) | Qty | Total Price (₹)
1 | Module1: Charging Circuit | 1280 | 1 | 1280
2 | Module2: Arduino Mega 2560 | 700 | 1 | 700
3 | Module3: L298N with DC Gear motor | 400 | 4 | 1300
4 | Module4:SG-90 | 100 | 3 | 300
5 | Module6:MG-995 | 250 | 3 | 750
6 | Module7:DHT11 | 85 | 1 | 85
7 | Module8:MQ-5 | 100 | 1 | 100
8 | Module9: Inductive Proximity Sensor | 200 | 1 | 200
9 | Module10: Bluetooth module (HC-05) | 250 | 1 | 250
TOTAL | | | | 4,965

DIPLOMA IN MECHATRONICS - NEC | 47

### 15.2 MECHANICAL COMPONENTS

Sl.no | Mechanical components | Specification | Qty | Price (₹)
1 | Screw Nut Spacers | M3*15mm M3.5*0.6mm M3*10mm, M3*35mm | 200g 150g 500g | 200
2 | L-clamps | 20 mm x 20 mm | 20 pieces | 50
3 | plywood | IS 303 Grade (5mm x 500mm X 400mm) | 1 sheet | 200
4 | wheels | 100 mm (R50) | 4 | 500
Total | | | | 950

DIPLOMA IN MECHATRONICS - NEC | 48

### 15.3 ELECTRICAL COMPONENTS

### 15.4 MISCELLANEOUS

Sl.no | Item description | Specifications | Quantity | Price (₹)
1 | Anabond | 202 (Cyanoacrylate Adhesive) | 20ml | 100
2 | Nylon Bush | 25mm | 8 | 40
Sl.no | Item Description | Specification | Quantity | Price (₹)
1 | Insulation tape | 10.5mm*10m | 1 | 30
2 | Sleeves | Ø1mm Ø3mm Ø6mm | 2m 2m 2m | 30 40 40
3 | Connecting Wires | Multi Stranded (24 AWG, 10 AWG) | 10m | 150
Total | | | | 290

DIPLOMA IN MECHATRONICS - NEC | 49
3 | Plastic loop Lock Pin Tag | 3” | 75g | 30
Total | | | | 170

### 15.5 OVERALL BILL OF MATERIAL

Items | price (₹)
Mechanical Components | 950
Electrical Components | 290
Modules | 4,965
Miscellaneous | 170
3D Parts for Robotic Arm | 3,200
Total | 9,575

DIPLOMA IN MECHATRONICS - NEC | 50

## 16.0 SUB ASSEMBLY AND TESTING

### 16.1 POWER SUPPLY UNIT

In this project we requires one battery charger power

supply (12V)

TESTING STEPS

- Checked all components.
- Connected on the PCB board according to the design.
- Gave input (230V AC).
- Verified the output by observing the reading on the multi-meter.
- Soldered the components on a general purpose circuit board.
- Checked for shorts on the circuits by using a multimeter.
- Gave supply and checked whether corrected voltage is coming

on the correct pins.

### 16.2 CONTROL MODULE

we are using ATMEGA 2560 microcontroller as intelligent brain of our system.

DIPLOMA IN MECHATRONICS - NEC | 51

The unit consist of

- Oscillator circuit
- Reset circuit
- 5V Power supply
- WDT
- POWER ON RESET
- RESET SWITCH
- PWM
- I/O PORTS

TESTING STEPS

- Checked all the components.
- Connected on the PCB according to the design.
- Gave input (0/1) to pins according to the condition for reset

circuit.

- Connected the oscillator circuit as per design.
- Verified the output by pressing the reset switch in the reset

circuit.

- Soldered the components on a general purpose circuit board.
- Checked for shorts on the circuits by using a multimeter.
- Gave supply and checked whether corrected voltage is coming

on the correct pins.

### 16.3 MOTOR DRIVER MODULE

- Motor driving unit consist of ic L298N.
- It receives input from microcontroller.
- It drives the gear motor according to the receiving command and

programs.

DIPLOMA IN MECHATRONICS - NEC | 52

TESTING STEPS

- Checked all the components.
- Connected on the PCB according to the design.
- Gave input (0/1) to the pins according to the condition.
- Verified the output by abserving the rotation direction of motor.
- Check for shorts on the circuit by using the multimeter.
- Gave supply and checked whether corrected voltage is coming

on the correct pin.

- Verify the connection is correct or not.
- Checked the mechanical structure for assembly.
- Gave input and verified the output

### 16.4 INPUT MODULE

- It consists of Bluetooth client.
- Remote controlled system using Bluetooth master with Arduino application (.apk).

TESTING STEPS

- Give input (0/1) according to the conditions.
- Gave supply and checked whether correct voltage is coming on

the correct pins.

DIPLOMA IN MECHATRONICS - NEC | 53

### 16.5 OUTPUT MODULE

- It consists of DC motors.
- DC motors are used for the motion of the robotic rover.
- It consists of servo motor used to move the robot arm.

TESTING STEPS

- Give input (0/1) according to the conditions.
- Verified the output by observing the motion of motors.
- Gave supply and checked whether correct voltage is coming on

the correct pins.

DIPLOMA IN MECHATRONICS - NEC | 54

## 17.0 OVERALL ASSEMBLY, TESTING AND

## OBSERVATION

### 17.1 MECHANICAL

- According to our design made all mechanical parts for our

project. The required parts for our project are

- Moving part of vehicle
- Body of vehicle
- Robotic arm
- Assembled all mechanical parts

### 17.2 ELECTRICAL AND ELECTRONICS

According to our design of each sub circuits made all modules for

our project. The required modules for our project are.

- Charging circuit
- Microcontroller Unit
- Motor Driver Circuit
- From the output of the +5V power supply, made each

connection to Microcontroller unit.

- From the output of the +12V power supply, made each

connection to Driver circuit.

DIPLOMA IN MECHATRONICS - NEC | 55
- The output of the switch circuit and RF Module is connected to

the input of the Microcontroller unit.

- From the output of the Microcontroller unit a connection is

made to the input of Driver circuit.

- The shaft of the motor then coupled with rack and pinion.
- Checked the continuity of all connections.
- Corresponding switches is pressed and checked the output status.
- Measured the voltage at each input and output terminal

DIPLOMA IN MECHATRONICS - NEC | 56

## 18.0 INTER CONNECTION DIAGRAM

## 19.0 OVERALL CIRCUIT DIAGRAM

## 20.0 MODULAR DIAGRAM

## 21.0 ADVANTAGES & DISADVANTAGES

ADVANTAGES

- Reducing Man Power
- Fast Production
- Time Management

DISADVANTAGES

- Less Payload Capacity
- Full Manual Controlled
- Limited Operating Range

APPLICATIONS

- Pick & Place
- Industrial Usage
- Component Handling

DIPLOMA IN MECHATRONICS - NEC | 57

## 22.0 PROGRAM

### 22.1 PROGRAM

#include <SoftwareSerial.h>

#include <AccelStepper.h>

#include <Servo.h>

Servo servo01;

Servo servo02;

Servo servo03;

Servo servo04;

Servo servo05;

Servo servo06;

SoftwareSerial Bluetooth(A8,36); // Arduino(RX, TX) - HC-05 Bluetooth (TX, RX)

// Define the stepper motors and the pins the will use

AccelStepper LeftBackWheel(1, 42, 43); // (Type:driver, STEP, DIR) - Stepper1

AccelStepper LeftFrontWheel(1, 40, 41); // Stepper2

AccelStepper RightBackWheel(1, 44, 45); // Stepper3

AccelStepper RightFrontWheel(1, 46, 47); // Stepper4

DIPLOMA IN MECHATRONICS - NEC | 58

#define led 14

int wheelSpeed = 1500;

int lbw[50], lfw[50], rbw[50], rfw[50]; // arrays for storing positions/steps

int servo1Pos, servo2Pos, servo3Pos, servo4Pos, servo5Pos, servo6Pos; // current position

int servo1PPos, servo2PPos, servo3PPos, servo4PPos, servo5PPos, servo6PPos; // previous position

int servo01SP[50], servo02SP[50], servo03SP[50], servo04SP[50], servo05SP[50], servo06SP[50]; // for storing positions/steps

int speedDelay = 20;

int index = 0;

int dataIn;

int m = 0;

void setup() {

// Set initial seed values for the steppers

LeftFrontWheel.setMaxSpeed(3000);

LeftBackWheel.setMaxSpeed(3000);

DIPLOMA IN MECHATRONICS - NEC | 59

RightFrontWheel.setMaxSpeed(3000);

RightBackWheel.setMaxSpeed(3000);

pinMode(led, OUTPUT);

servo01.attach(5);

servo02.attach(6);

servo03.attach(7);

servo04.attach(8);

servo05.attach(9);

servo06.attach(10);

Bluetooth.begin(4800); // Default baud rate of the Bluetooth module

Bluetooth.setTimeout(5);

delay(20);

Serial.begin(9600);

// Move robot arm to initial position

servo1PPos = 90;

servo01.write(servo1PPos);

servo2PPos = 100;

servo02.write(servo2PPos);

servo3PPos = 120;

servo03.write(servo3PPos);

servo4PPos = 95;

DIPLOMA IN MECHATRONICS - NEC | 60

servo04.write(servo4PPos);

servo5PPos = 60;

servo05.write(servo5PPos);

servo6PPos = 110;

servo06.write(servo6PPos);

}

void loop() {

// Check for incoming data

if (Bluetooth.available() > 0) {

dataIn = Bluetooth.read(); // Read the data

Serial.println(m ="");

if (dataIn == 0) {

m = 0;

}

if (dataIn == 1) {

m = 1;

}

if (dataIn == 2) {

m = 2;

}

if (dataIn == 3) {

DIPLOMA IN MECHATRONICS - NEC | 61

m = 3;

}

if (dataIn == 4) {

m = 4;

}

if (dataIn == 5) {

m = 5;

}

if (dataIn == 6) {

m = 6;

}

if (dataIn == 7) {

m = 7;

}

if (dataIn == 8) {

m = 8;

}

if (dataIn == 9) {

m = 9;

}

if (dataIn == 10) {

m = 10;

DIPLOMA IN MECHATRONICS - NEC | 62

}

if (dataIn == 11) {

m = 11;

}

if (dataIn == 12) {

m = 12;

}

if (dataIn == 14) {

m = 14;

}

if (dataIn == 16) {

m = 16;

}

if (dataIn == 17) {

m = 17;

}

if (dataIn == 18) {

m = 18;

}

if (dataIn == 19) {

m = 19;

}

DIPLOMA IN MECHATRONICS - NEC | 63

if (dataIn == 20) {

m = 20;

}

if (dataIn == 21) {

m = 21;

}

if (dataIn == 22) {

m = 22;

}

if (dataIn == 23) {

m = 23;

}

if (dataIn == 24) {

m = 24;

}

if (dataIn == 25) {

m = 25;

}

if (dataIn == 26) {

m = 26;

}

if (dataIn == 27) {

DIPLOMA IN MECHATRONICS - NEC | 64

m = 27;

}

// Move the Mecanum wheels platform

if (m == 4) {

moveSidewaysLeft();

}

if (m == 5) {

moveSidewaysRight();

}

if (m == 2) {

moveForward();

}

if (m == 7) {

moveBackward();

}

if (m == 3) {

moveRightForward();

}

if (m == 1) {

moveLeftForward();

}

DIPLOMA IN MECHATRONICS - NEC | 65

if (m == 8) {

moveRightBackward();

}

if (m == 6) {

moveLeftBackward();

}

if (m == 9) {

rotateLeft();

}

if (m == 10) {

rotateRight();

}

if (m == 0) {

stopMoving();

}

// Mecanum wheels speed

if (dataIn > 30 & dataIn < 100) {

wheelSpeed = dataIn * 20;

}

DIPLOMA IN MECHATRONICS - NEC | 66

// Move robot arm

// Move servo 1 in positive direction

while (m == 16) {

if (Bluetooth.available() > 0) {

m = Bluetooth.read();

}

servo01.write(servo1PPos);

servo1PPos++;

delay(speedDelay);

}

// Move servo 1 in negative direction

while (m == 17) {

if (Bluetooth.available() > 0) {

m = Bluetooth.read();

}

servo01.write(servo1PPos);

servo1PPos--;

delay(speedDelay);

}

// Move servo 2

while (m == 19) {

if (Bluetooth.available() > 0) {

DIPLOMA IN MECHATRONICS - NEC | 67

m = Bluetooth.read();

}

servo02.write(servo2PPos);

servo2PPos++;

delay(speedDelay);

}

while (m == 18) {

if (Bluetooth.available() > 0) {

m = Bluetooth.read();

}

servo02.write(servo2PPos);

servo2PPos--;

delay(speedDelay);

}

// Move servo 3

while (m == 20) {

if (Bluetooth.available() > 0) {

m = Bluetooth.read();

}

servo03.write(servo3PPos);

servo3PPos++;

delay(speedDelay);

DIPLOMA IN MECHATRONICS - NEC | 68

}

while (m == 21) {

if (Bluetooth.available() > 0) {

m = Bluetooth.read();

}

servo03.write(servo3PPos);

servo3PPos--;

delay(speedDelay);

}

// Move servo 4

while (m == 23) {

if (Bluetooth.available() > 0) {

m = Bluetooth.read();

}

servo04.write(servo4PPos);

servo4PPos++;

delay(speedDelay);

}

while (m == 22) {

if (Bluetooth.available() > 0) {

m = Bluetooth.read();

}

DIPLOMA IN MECHATRONICS - NEC | 69

servo04.write(servo4PPos);

servo4PPos--;

delay(speedDelay);

}

// Move servo 5

while (m == 25) {

if (Bluetooth.available() > 0) {

m = Bluetooth.read();

}

servo05.write(servo5PPos);

servo5PPos++;

delay(speedDelay);

}

while (m == 24) {

if (Bluetooth.available() > 0) {

m = Bluetooth.read();

}

servo05.write(servo5PPos);

servo5PPos--;

delay(speedDelay);

}

// Move servo 6

DIPLOMA IN MECHATRONICS - NEC | 70

while (m == 26) {

if (Bluetooth.available() > 0) {

m = Bluetooth.read();

}

servo06.write(servo6PPos);

servo6PPos++;

delay(speedDelay);

}

while (m == 27) {

if (Bluetooth.available() > 0) {

m = Bluetooth.read();

}

servo06.write(servo6PPos);

servo6PPos--;

delay(speedDelay);

}

// If arm speed slider is changed

if (dataIn > 101 & dataIn < 250) {

speedDelay = dataIn / 10; // Change servo speed (delay time)

}

DIPLOMA IN MECHATRONICS - NEC | 71

// If button "SAVE" is pressed

if (m == 12) {

//if it's initial save, set the steppers position to 0

if (index == 0) {

LeftBackWheel.setCurrentPosition(0);

LeftFrontWheel.setCurrentPosition(0);

RightBackWheel.setCurrentPosition(0);

RightFrontWheel.setCurrentPosition(0);

}

lbw[index] = LeftBackWheel.currentPosition(); // save position into the array

lfw[index] = LeftFrontWheel.currentPosition();

rbw[index] = RightBackWheel.currentPosition();

rfw[index] = RightFrontWheel.currentPosition();

servo01SP[index] = servo1PPos; // save position into the array

servo02SP[index] = servo2PPos;

servo03SP[index] = servo3PPos;

servo04SP[index] = servo4PPos;

servo05SP[index] = servo5PPos;

servo06SP[index] = servo6PPos;

DIPLOMA IN MECHATRONICS - NEC | 72
index++; | // Increase the array index

m = 0;

}

// If button "RUN" is pressed

if (m == 14) {

runSteps();

// If button "RESET" is pressed

if (dataIn != 14) {

stopMoving();

memset(lbw, 0, sizeof(lbw)); // Clear the array data to 0

memset(lfw, 0, sizeof(lfw));

memset(rbw, 0, sizeof(rbw));

memset(rfw, 0, sizeof(rfw));

memset(servo01SP, 0, sizeof(servo01SP)); // Clear the array data to 0

memset(servo02SP, 0, sizeof(servo02SP));

memset(servo03SP, 0, sizeof(servo03SP));

memset(servo04SP, 0, sizeof(servo04SP));

memset(servo05SP, 0, sizeof(servo05SP));

memset(servo06SP, 0, sizeof(servo06SP));

DIPLOMA IN MECHATRONICS - NEC | 73

index = 0; // Index to 0

}

}

}

LeftFrontWheel.runSpeed();

LeftBackWheel.runSpeed();

RightFrontWheel.runSpeed();

RightBackWheel.runSpeed();

// Monitor the battery voltage

int sensorValue = analogRead(A0);

float voltage = sensorValue * (5.0 / 1023.00) * 3; // Convert the reading values from 5v to suitable 12V i

//Serial.println(voltage);

// If voltage is below 11V turn on the LED

if (voltage < 11) {

digitalWrite(led, HIGH);

}

else {

digitalWrite(led, LOW);

}

}

DIPLOMA IN MECHATRONICS - NEC | 74

void moveForward() {

LeftFrontWheel.setSpeed(wheelSpeed);

LeftBackWheel.setSpeed(wheelSpeed);

RightFrontWheel.setSpeed(wheelSpeed);

RightBackWheel.setSpeed(wheelSpeed);

}

void moveBackward() {

LeftFrontWheel.setSpeed(-wheelSpeed);

LeftBackWheel.setSpeed(-wheelSpeed);

RightFrontWheel.setSpeed(-wheelSpeed);

RightBackWheel.setSpeed(-wheelSpeed);

}

void moveSidewaysRight() {

LeftFrontWheel.setSpeed(wheelSpeed);

LeftBackWheel.setSpeed(-wheelSpeed);

RightFrontWheel.setSpeed(-wheelSpeed);

RightBackWheel.setSpeed(wheelSpeed);

}

void moveSidewaysLeft() {

LeftFrontWheel.setSpeed(-wheelSpeed);

LeftBackWheel.setSpeed(wheelSpeed);

RightFrontWheel.setSpeed(wheelSpeed);

DIPLOMA IN MECHATRONICS - NEC | 75

RightBackWheel.setSpeed(-wheelSpeed);

}

void rotateLeft() {

LeftFrontWheel.setSpeed(-wheelSpeed);

LeftBackWheel.setSpeed(-wheelSpeed);

RightFrontWheel.setSpeed(wheelSpeed);

RightBackWheel.setSpeed(wheelSpeed);

}

void rotateRight() {

LeftFrontWheel.setSpeed(wheelSpeed);

LeftBackWheel.setSpeed(wheelSpeed);

RightFrontWheel.setSpeed(-wheelSpeed);

RightBackWheel.setSpeed(-wheelSpeed);

}

void moveRightForward() {

LeftFrontWheel.setSpeed(wheelSpeed);

LeftBackWheel.setSpeed(0);

RightFrontWheel.setSpeed(0);

RightBackWheel.setSpeed(wheelSpeed);

}

void moveRightBackward() {

LeftFrontWheel.setSpeed(0);

DIPLOMA IN MECHATRONICS - NEC | 76

LeftBackWheel.setSpeed(-wheelSpeed);

RightFrontWheel.setSpeed(-wheelSpeed);

RightBackWheel.setSpeed(0);

}

void moveLeftForward() {

LeftFrontWheel.setSpeed(0);

LeftBackWheel.setSpeed(wheelSpeed);

RightFrontWheel.setSpeed(wheelSpeed);

RightBackWheel.setSpeed(0);

}

void moveLeftBackward() {

LeftFrontWheel.setSpeed(-wheelSpeed);

LeftBackWheel.setSpeed(0);

RightFrontWheel.setSpeed(0);

RightBackWheel.setSpeed(-wheelSpeed);

}

void stopMoving() {

LeftFrontWheel.setSpeed(0);

LeftBackWheel.setSpeed(0);

RightFrontWheel.setSpeed(0);

RightBackWheel.setSpeed(0);

}

DIPLOMA IN MECHATRONICS - NEC | 77

// Automatic mode custom function - run the saved steps

void runSteps() {

while (dataIn != 13) { // Run the steps over and over again until "RESET" button is pressed

for (int i = 0; i <= index - 2; i++) { // Run through all steps(index)

if (Bluetooth.available() > 0) { // Check for incomding data

dataIn = Bluetooth.read();

if ( dataIn == 15) { | // If button "PAUSE" is
pressed
while (dataIn != 14) { | // Wait until "RUN" is
pressed again

if (Bluetooth.available() > 0) {

dataIn = Bluetooth.read();

if ( dataIn == 13) {

break;

}

}

}

}

// If speed slider is changed

if (dataIn > 100 & dataIn < 150) {

DIPLOMA IN MECHATRONICS - NEC | 78

speedDelay = dataIn / 10; // Change servo speed (delay time)

}

// Mecanum wheels speed

if (dataIn > 30 & dataIn < 100) {

wheelSpeed = dataIn * 10;

dataIn = 14;

}

}

LeftFrontWheel.moveTo(lfw[i]);

LeftFrontWheel.setSpeed(wheelSpeed);

LeftBackWheel.moveTo(lbw[i]);

LeftBackWheel.setSpeed(wheelSpeed);

RightFrontWheel.moveTo(rfw[i]);

RightFrontWheel.setSpeed(wheelSpeed);

RightBackWheel.moveTo(rbw[i]);

RightBackWheel.setSpeed(wheelSpeed);

while (LeftBackWheel.currentPosition() != lbw[i] & LeftFrontWheel.currentPosition() != lfw[i] & RightFrontWheel.currentPosition() != rfw[i] & RightBackWheel.currentPosition() != rbw[i]) {

LeftFrontWheel.runSpeedToPosition();

DIPLOMA IN MECHATRONICS - NEC | 79

LeftBackWheel.runSpeedToPosition();

RightFrontWheel.runSpeedToPosition();

RightBackWheel.runSpeedToPosition();

}

// Servo 1

if (servo01SP[i] == servo01SP[i + 1]) {

}

if (servo01SP[i] > servo01SP[i + 1]) {

for ( int j = servo01SP[i]; j >= servo01SP[i + 1]; j--) {

servo01.write(j);

delay(speedDelay);

}

}

if (servo01SP[i] < servo01SP[i + 1]) {

for ( int j = servo01SP[i]; j <= servo01SP[i + 1]; j++) {

servo01.write(j);

delay(speedDelay);

}

}

// Servo 2

DIPLOMA IN MECHATRONICS - NEC | 80

if (servo02SP[i] == servo02SP[i + 1]) {

}

if (servo02SP[i] > servo02SP[i + 1]) {

for ( int j = servo02SP[i]; j >= servo02SP[i + 1]; j--) {

servo02.write(j);

delay(speedDelay);

}

}

if (servo02SP[i] < servo02SP[i + 1]) {

for ( int j = servo02SP[i]; j <= servo02SP[i + 1]; j++) {

servo02.write(j);

delay(speedDelay);

}

}

// Servo 3

if (servo03SP[i] == servo03SP[i + 1]) {

}

if (servo03SP[i] > servo03SP[i + 1]) {

for ( int j = servo03SP[i]; j >= servo03SP[i + 1]; j--) {

DIPLOMA IN MECHATRONICS - NEC | 81

servo03.write(j);

delay(speedDelay);

}

}

if (servo03SP[i] < servo03SP[i + 1]) {

for ( int j = servo03SP[i]; j <= servo03SP[i + 1]; j++) {

servo03.write(j);

delay(speedDelay);

}

}

// Servo 4

if (servo04SP[i] == servo04SP[i + 1]) {

}

if (servo04SP[i] > servo04SP[i + 1]) {

for ( int j = servo04SP[i]; j >= servo04SP[i + 1]; j--) {

servo04.write(j);

delay(speedDelay);

}

}

if (servo04SP[i] < servo04SP[i + 1]) {

DIPLOMA IN MECHATRONICS - NEC | 82

for ( int j = servo04SP[i]; j <= servo04SP[i + 1]; j++) {

servo04.write(j);

delay(speedDelay);

}

}

// Servo 5

if (servo05SP[i] == servo05SP[i + 1]) {

}

if (servo05SP[i] > servo05SP[i + 1]) {

for ( int j = servo05SP[i]; j >= servo05SP[i + 1]; j--) {

servo05.write(j);

delay(speedDelay);

}

}

if (servo05SP[i] < servo05SP[i + 1]) {

for ( int j = servo05SP[i]; j <= servo05SP[i + 1]; j++) {

servo05.write(j);

DIPLOMA IN MECHATRONICS - NEC | 83

delay(speedDelay);

}

}

// Servo 6

if (servo06SP[i] == servo06SP[i + 1]) {

}

if (servo06SP[i] > servo06SP[i + 1]) {

for ( int j = servo06SP[i]; j >= servo06SP[i + 1]; j--) {

servo06.write(j);

delay(speedDelay);

}

}

if (servo06SP[i] < servo06SP[i + 1]) {

for ( int j = servo06SP[i]; j <= servo06SP[i + 1]; j++) {

servo06.write(j);

delay(speedDelay);

}

}

}

}

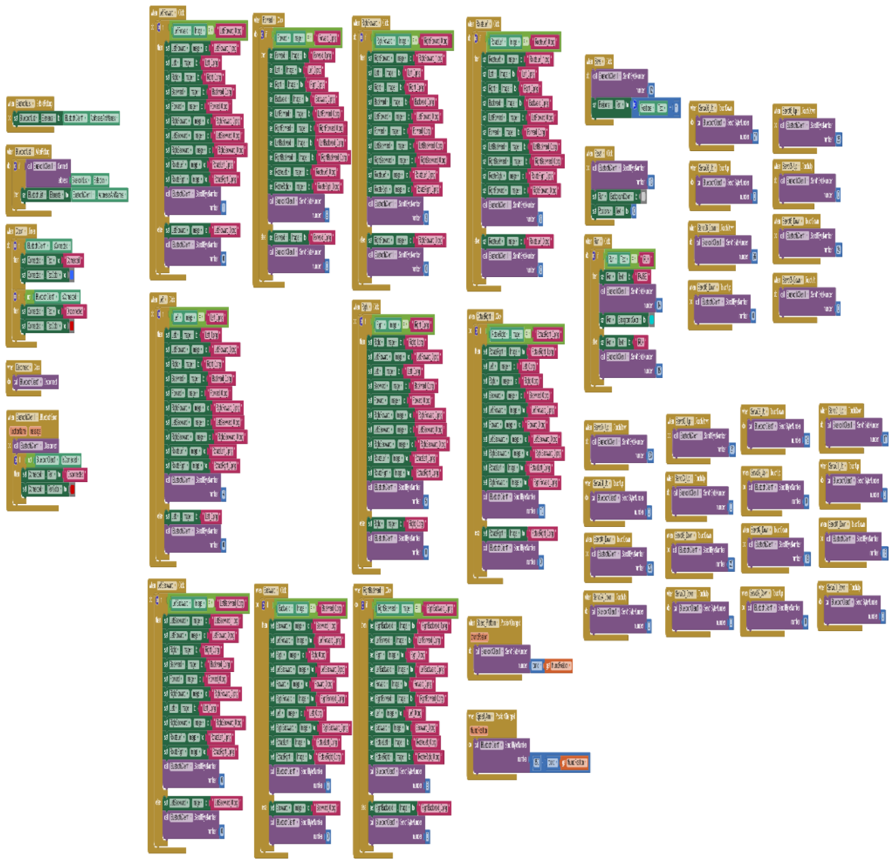
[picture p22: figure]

DIPLOMA IN MECHATRONICS - NEC | 84

}

## 22.2 MIT APP INVENTOR

## BLOCK DESIGN:

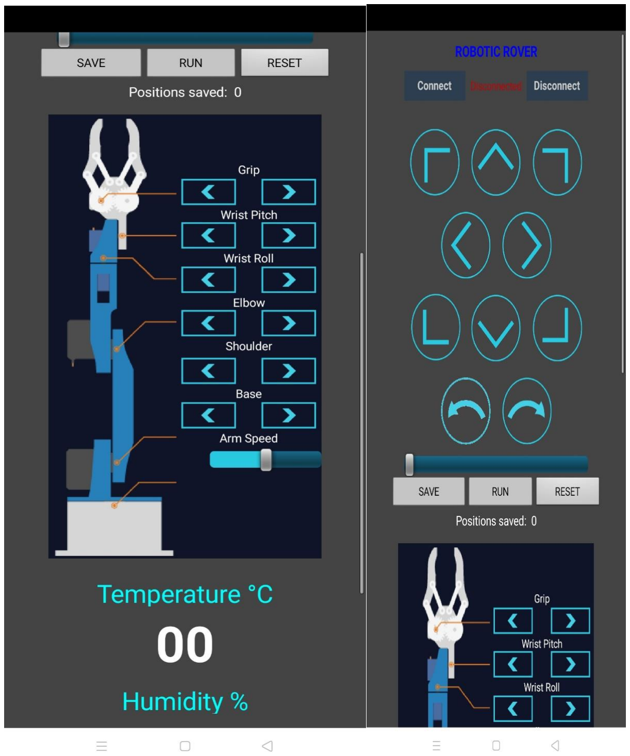
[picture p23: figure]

DIPLOMA IN MECHATRONICS - NEC | 85

## USER INTERFACE:

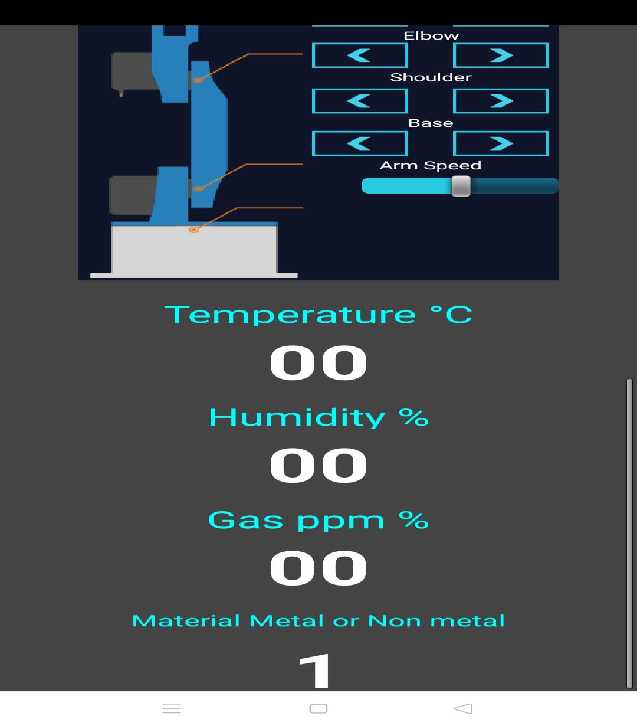
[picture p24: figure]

DIPLOMA IN MECHATRONICS - NEC | 86

DIPLOMA IN MECHATRONICS - NEC | 87

## 23.0 CONCLUSION

This gives us extreme pleasure to conclude this project report

prepared on the basis of our 6th semester academic project undergone

in NEC-NTTF training center. We are well fed with all necessary

information and knowledge about the technology of present days.

Thus, the robotic rover can help for gripping up harmful objects

and place them safely and these robots are used in manufacturing

industries to move objects.

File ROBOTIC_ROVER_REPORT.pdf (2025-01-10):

DIPLOMA IN MECHATRONICS - NEC | 1

ROBOTIC ROVER

## CHAPTER 1

## INTRODUCTION

The project is designed to develop a Robotic Rover vehicle with a soft holding

gripper. It can be used for pick and place of an object. It can sense whether the object

picked is metallic or non-metallic. It can also detect the rover is in gaseous surrounding

or not (LPG, I-Butane, Methane, Hydrogen, Alcohol, smoke). It can also tell the

temperature and humidity level. The robotic vehicle is controlled by an android

application for remote operation.

At the transmitting end using an Android application device, commands are sent

to the receiver to control the movement of the robot to move forward, backward, and

left or right. The android application device transmitted acts as a remote control that

has the advantage of a certain range, while the receiver end is fed to the micro controller

to drive DC motors via motor driver IC for necessary work. Remote operation is achieved

by any smart-phone/Tablet, etc. The main advantage of this robot is its holding arm,

which is designed to avoid extra pressure on the suspected object for safety reasons. A

Rover is the one which is used to pick up an object and place it in the desired location.

It is an articulated Robotic Rover, which contains a fixed robot with 3 vertical axes and

rotary arms.

Manipulator is the main body of the vehicle which consisting of several joints

and links.

DIPLOMA IN MECHATRONICS - NEC | 2

## CHAPTER 2

## PROECT BRIEF

AIM

To design and build a Robotic Rover.

OBJECTIVES

- To design a speed control system for the Robotic Rover
- Pick and place the objects using manipulator
- To implement wireless android application to control the Robotic

Rover

- To detect gases in surrounding (LPG, I-Butane, Methane, Hydro

gen, Alcohol)

- To display temperature and humidity level
- To sense whether the object is metallic or non-metallic

PROJECT TARGET

To create a wireless based Robotic Rover which can move an

object from one place to another place and also to an unsustainable

condition or environment.

## CHAPTER 3

DIPLOMA IN MECHATRONICS - NEC; MODULE 1; 12V DC,1Amp; Microcontroller; Assembly; NODE MCU; ESP8266-12E; Rectangular Gearbox Motor30RPM; Rectangular Gearbox Motor30RP; BTS7960 MotorDriver; L298N MOTOR DRIVER; 2*SG90 Servo motor; 3*MG995 Servo motor; MODULE 6; MODULE 5; 12VDC,2A WEB; MODULE 9; INDUCTIVE PROXIMITY SENSOR; MODULE 8; MODULE 7; 5VDC,150mA; StepDown Transformer 15V-0-15V AC/2A; Full Wave Rectifier 1N4007*2; Charging Circuit 14V DC/1.5A; Lead Acid Battery 12V DC/7.5Ah; Lead Acid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

EXISTING BLOCK DIAGRAM

GAS SENSOR(MQ-5)

TEMPERATURE AND HUMIDITY
SENSOR

DIPLOMA IN MECHATRONICS - NEC; MODULE 1; Microcontroller; BLUETOOTH; Assembly; MODULE; L298N Motor; Driver; 3*SG90 Servo motor; 3*MG995 Servo motor; MODULE 5; 5VDC,1A; MODULE 4; MOBILE; MODULE 8; INDUCTIVE PROXIMITY SENSOR; MODULE 7; MODULE 6; Step Down Transformer15V -0-15V AC/2A; Full Wave Rectifier N4007*2; Charging Circuit 14V DC/1.5A; Lead Acid Battery 12V DC/7.5Ah; 7805 Lead Acid; Battery12V DC,7.5Ah; 12V DC ,2Amp; 12VDC,1Amp; 5V DC,1Amp; MODULE 9; MODULE 2; DC Gear motor (100 RPM)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

IMPROVISED BLOCK DIAGRAM

GAS SENSOR (MQ-

TEMPERATURE
AND HUMIDITY SENSOR

DIPLOMA IN MECHATRONICS - NEC | 5

## CHAPTER 4

COMPARISION OF EXISTING AND IMPROVISED

BLOCK DIAGRAM

EXISTING | IMPROVISED
1)In this we are using Node-MCU to communicate with the Arduino uno. The main disadvantage is, it required internet to connect to client. | 1)In this we are using Bluetooth Module to communicate with the Arduino MEGA. The main advantage is, it required a mobile application to connect without internet
2)In this we are using BTS7960 motor Driver to drive the motor. The main Disadvantage is, it required more ports to drive a motor. | 2) In this we are using L298N motor driver to drive the DC Gear motor. The main advantage is, it required less ports to drive a DC Gear motor.
3)In this we are using chain drive mechanism to move the rover. The main Disadvantage is, it will take more radius and angle while taking directions. | 3)In this we are using Wheels. The main Advantage is, it has no limitation like chain drive mechanism.

DIPLOMA IN MECHATRONICS - NEC | 6

## CHAPTER 5

## BLOCK DIAGRAM DESCRIPTION

MODULE 1: POWER SUPPLY & CHARGING CIRCUIT

12V DC/1A ,12V DC/4A & 5V DC/1A:

- In Robotic Rover 12V & 5V DC power supply is used to supply

power to equipment’s where 12V power is required for motor

drivers and motors and 5V power is required for sensors,

microcontroller and Servo motor.

- It supplies power to motor driver, Arduino microcontroller

module, Sensors, Node MCU.

MODULE 2: ARDUINO MEGA 2560:

- The Arduino MEGA 2560 is designed for projects that require m

ore I/O lines, more sketch memory and more RAM.

- With 54 digital I/O pins, 16 analog inputs and a larger space for

your sketch it is the recommended board for 3D printers and

robotics projects.

- The Arduino Mega 2560 is programmed using the software (IDE)

our Integrated Development Environment common to all our

boards and running both online and offline.

MODULE 3: JOHNSON MOTOR WITH L298N MOTOR

DRIVER

- It is a simple DC motor featuring metal gearbox for driving the

shaft of the motor.

DIPLOMA IN MECHATRONICS - NEC | 7
- It is a mechanically commutated electric motor which is

powered from DC supply. The Johnson Geared Motors are

known for their compact size and massive torque-speed

characteristic.

- The motor will run smoothly between the voltage range 6V to

18V DC and give you 10 RPM at 12V supply. It provides the

massive torque of 12.5 kg-cm at 10 RPM.

L298N MOTOR DRIVER:

- This dual bidirectional motor driver, is based on the very popular

L298 Dual H-Bridge Motor Driver Integrated Circuit.

- The circuit will allow you to easily and independently control two

motors of up to 2A each in both directions.

MODULE 4: SG-90 SERVO MOTOR:

- The TowerPro SG90 9g Mini Servo is 180° rotation servo.
- It is a Digital Servo Motor which receives and processes PWM

signal faster and better.

- It equips sophisticated internal circuitry that provides good

torque, holding power, and faster updates in response to external

forces.

MODULE 5: MG995 SERVO MOTOR:

- The MG995 is a high torque, digital metal geared servo.
- It comes in a standard size and its metal gears mean when the

motor is in a jam, the gears aren’t likely to strip.

- This servo will rotate up to 90 degrees.

DIPLOMA IN MECHATRONICS - NEC | 8

MODULE 6: DHT11 (TEMPERATURE AND HUMIDITY

SENSOR):

- DHT11 Temperature and Humidity Sensor.
- This DHT11 Temperature and Humidity Sensor features a

calibrated digital signal output with the temperature and

humidity sensor capability.

- It is integrated with a high-performance 8-bit microcontroller. Its

technology ensures the high reliability and excellent long-term

stability.

MODULE 7: MQ-5 (GAS SENSOR):

- The MQ5 Gas Sensor module is useful for gas leakage detecting.
- It can detect LPG, i-butane, methane, alcohol, Hydrogen, CO2.
- The | sensitivity | can | be | adjusted | using | the | on-board

potentiometer, and you'd use this sensor by reading the analog

pin to which it is connected.

MODULE 8: INDUCTIVE PROXIMITY SENSOR:

- An inductive sensor is a device that uses the principle

of electromagnetic induction (https://en.wikipedia.org/wiki/Electromagnetic_induction) to detect or measure objects.

- An inductor develops a magnetic field when a current flow

through it; alternatively, a current will flow through a circuit

containing an inductor when the magnetic field through it

changes.

- This effect can be used to detect metallic objects that interact

with a magnetic field.

- Non-metallic substances such as liquids or some kinds of dirt do

not interact with the magnetic field.

DIPLOMA IN MECHATRONICS - NEC | 9

MODULE 9: BLUETOOTH MODULE (HC-05):

- The HC-05 has two operating modes, one is the Data mode in which it can send and receive data from other Bluetooth devices and the other is the AT Command mode where the default device settings can be changed.
- We can operate the device in either of these two modes by using the key pin as explained in the pin description.
- It is very easy to pair the HC-05 module with microcontrollers because it operates using the Serial Port Protocol (SPP).
- Simply power the module with +5V and connect the Rx pin of the module to the Tx of MCU and Tx pin of module to Rx of MCU

MODULE 01

DIPLOMA IN MECHATRONICS - NEC | 10

## POWER SUPPLY & CHARGING CIRCUIT

## (DC 12V/2A & DC 5V/1A)

## CONTENTS

- DESCRIPTION
- BLOCK DIAGRAM
- SCHEMATIC DIAGRAM
- DESIGN


DIPLOMA IN MECHATRONICS - NEC | 11

## CHAPTER 6

## 6.0 POWER SUPPLY & CHARGING CIRCUIT

### 6.1 DESCRIPTION

Step down transformer gives 15V-0-15V/2A AC to the center

tap full wave rectifier formed by diodes D1, D2. Rectifier will convert

30V AC to 19V DC. Capacitor C1 is introduced to filter the ripples of

converted DC, so it used as filter as well as backup capacitor. To

remove the ripple voltage. The Rectifier is connected to the

capacitors 1000uf,50V and they are connected to regulator LM317

for regulating the voltage to 13.5v for charging the battery and a

freewheeling is used to stop the back current from the battery to

protect the circuit. In this circuit we are used auto cutoff system to

overcome the problem of overcharging.

### 6.2 BLOCK DIAGRAM

DIPLOMA IN MECHATRONICS - NEC | 12

## BLOCK DIGRAM DESCRIPTION

INPUT

The input 230V/50Hz is given to the transformer.

STEPDOWN TRNSFORMER

A Step-Down Transformer is a device which converts high

primary voltage to a low secondary voltage. In a Step-Down

Transformer, the primary winding of a coil has more turns than the

secondary winding.

CENTER-TAP FULL WAVE RECTIFIER

A Full Wave Rectifier is a circuit, which converts an ac

voltage into a pulsating dc voltage using both half cycles of the applied

ac voltage. It uses two diodes of which one conducts during one half

cycle while the other conducts during the other half cycle of the applied

ac voltage.

FILTER

The pulsating output of the rectifiers has an average DC

value and an AC portion that is called ripple voltage. Filter capacitors

reduce the amount of ripple voltage to a level that is acceptable.

REGULATOR

We are using regulator ICs to maintain a constant output

voltage in a power supply circuit. We are using regulator IC LM317 for

getting 13V respectively through variable resistor to this we are

connected to the battery.


DIPLOMA IN MECHATRONICS - NEC | 13

For 12V,1Amp supply we are using 7812 for getting 12V

respectively, and for 5V,1Amp supply we are using 7805 for getting 5V

respectively.

LM317:

The LM317 is an adjustable 3−terminal positive voltage

regulator capable of supplying in excess of 1.5 A over an output voltage

range of 1.2 V to 37 V. This voltage regulator is exceptionally easy to

use and requires only two external resistors to set the output voltage.

Features

- Output Voltage Range Adjustable From 1.25 V to 37 V
- Output Current Greater Than 1.5 A
- Internal Short-Circuit Current Limiting
- Thermal Overload Protection

DIPLOMA IN MECHATRONICS - NEC | 14
- Output Safe-Area Compensation
LM7805:

7805 is a 5V fixed three terminal positive voltage regulator IC.

The IC has features such as safe operating area protection, thermal

shut down, internal current limiting which makes the IC very rugged.

Output currents up to 1A can be drawn from the IC provided that there

is a proper heat sink.

Features

- 5V Positive Voltage Regulator
- Minimum Input Voltage is 7V
- Maximum Input Voltage is 25V
- Operating current (IQ) is 5mA
- Internal Thermal Overload and Short circuit current limiting

protection is available.

- Junction Temperature maximum 125 degree Celsius
- Available in TO-220 and KTE package


DIPLOMA IN MECHATRONICS - NEC | 15

LM7812:

7812 is a 12V fixed three terminal positive voltage regulator IC.

The IC has features such as safe operating area protection, thermal

shut down, internal current limiting which makes the IC very rugged.

Output currents up to 1A can be drawn from the IC provided that there

is a proper heat sink.

Features

- Fixed voltage linear regulator
- 14-35V input voltage range
- 12V fixed output voltage
- 1A continuous current
- TO-220 package

Output:

The output of power supply is 12VDC/1A.

The output of power supply is 5 VDC/1A.

DIPLOMA IN MECHATRONICS - NEC | 16

## 6.3 SCHEMATIC DIAGRAM

## 6.4 DESIGN

CHARGING CIRCUIT REQUIREMENTS:

Voltage = 15V DC

Current = 1A

TRANSFORMER SPECFICATION:

Voltage =15V-0-15V AC

Current =2A

For Center Tap Full Wave Rectifier:

VDC = Pulsating DC Voltage (Volts)

Vmax = V peak Voltage (Volts)

VDC = 2xVmax/ϖ

DIPLOMA IN MECHATRONICS - NEC | 17

VDC =0.636xVmax

VDC =0.636x30

VDC=19.108V

As per the data sheet the Diode is 1N4007

Iout = Output Current (Amp)

Iout = 1A

In center tap full wave rectifier the frequency gets double

F=2 x F

Value of the capacitor:

C = Iout/F x Vripple

Vripple =20% of VDC

C = 1Amp/100HzX0.95

C = 950 µf

C =~ 1000 µf

Working Voltage of Capacitor:

V1 = Operating /Working Voltage

V1 =DC Voltage +25% (extra 25% for reduce the ripple voltage)

= 19+4.75

= 23.75

= 24V

DIPLOMA IN MECHATRONICS - NEC | 18

Capacitor standard Voltage we are consider 50V

V1=50V

VOLTAGE REGULATOR LM317:

Consider:

Vin = 19V

Vout = Output Voltage(Volts)

R1=100 Ω

R2=70 Ω

Vout = 1.25 (R1/R1+R2) Vin

= 1.25(100Ω/100 Ω +70 Ω) Vin

= 1.25(100Ω/100 Ω +70 Ω) X19V

= 1.25 X 11,1764

= 13.97V

Vout=~14V

For R2, R3, R4 (Ohm’s Law)

R = V/I

R = 14/20mA

R = 0.7 X 1000

R = 700 Ω

DIPLOMA IN MECHATRONICS - NEC | 19

Power Rating for Resistor:

I = 20mA

V = 14V

P = V x I

= 14(20mA)

= 280 x 10^-3

= 0.28 W

P =~0.25W

For Heatsink:

PD = (Vin-Vout) X I out

PD = power dissipation (Watt)

Vin = Input voltage (Volts)

Vout = output voltage (Volts)

Iout = output current (Amp)

PD = (19-14V) X 1Amp

= 5W

θJA = Total junction to ambient thermal resistance (˚C/W)

TJ =Junction temperature (˚C)

TA = Ambient temperature (˚C)

θJA (total) = TJ-TA/PD

DIPLOMA IN MECHATRONICS - NEC | 20

= 125˚C -23 ˚C/5W

= 102/5W

θJA=20.4 ˚C/W

## 6.5 BILL OF MATERIALS

MODULES

Sl.no | Item description | Symbol | Qty | Price(₹)
| (i) 3 core patch chord 230V AC,6A,50Hz | P1 | 1 | 50
| (ii) Connector 6 pin Poly carbonate,10A | SL1, SL4 | 2 | 12
| (iii) Connector 3 pin Poly carbonate,10A | SL2 | 1 | 3
| (iv) Connector 2 pin Poly carbonate,5A | SL3, SL5, SL6, SL7 | 4 | 8
| (v) Switch (Rocker SPST) 230V AC,6A | S1 | 1 | 20
| (vi)Fuse & Fuse holder (Glass Catridge Fuse 2A, Fuse holder round screw,6A, AC) | FU1 | 1 | 50

Module 1

(Power

Supply &

Charging

Circuit)

DIPLOMA IN MECHATRONICS - NEC | 21
(vii) Transformer Center Tap (15-0-15)V AC,2A | TF1 | 1 | 250
(viii) Diode: 1N4007 Axial Type | D1, D2, D3 | 3 | 9
(ix)Electrolytic Capacitor (50V,1000uf) Radial Type | C1 | 1 | 8
(x) Carbon film Resistor (10k,1/4W CFR, ±5%) | R1, R2, R3, R4 | 4 | 4
(xi) Trimpot (10k,1/2W) | VR1 | 1 | 10
(xii)LM317 | IC1 | 1 | 15
(xiii) Heat sink: E3A-T220-25E | - | 3 | 45
(xiv) NPN Transistor: BD139 | Q1 | 1 | 10
(xv) Zener Diode: 1N4742 Axial Type | Z1 | 1 | 2
(xvi) LED 5mm radial type (3V,20mA) | LD1, LD2, LD3 | 3 | 10

DIPLOMA IN MECHATRONICS - NEC | 22
(xvii) Lead Acid Battery (12V,7.5Ah) | B1 | 1 | 700
(xviii)Ceramic Capacitor (104) Radial Type (50V,0.1uf) | C2, C4, C5, C7 | 4 | 4
(xix) Electrolytic Capacitor (63V,10uf) Radial Type | C3, C6 | 2 | 12
(xx) DC +ve Regulator 7805,1A | IC2 | 1 | 10
(xxi) DC +ve Regulator 7812,1A | IC3 | 1 | 10
(xxii) Toggle switch: SPDT, SDT-106D-0-1(6A,125VAC) | S2 | 1 | 30
TOTAL | | | 1282

MODULE 02

DIPLOMA IN MECHATRONICS - NEC | 23

## ARDUINO MEGA 2560

CONTENTS

- DESCRIPTION
- FEATURES OF ARDUINO UNO
- SCHEMATIC DIAGRAM
- BILL OF MATERIAL

DIPLOMA IN MECHATRONICS - NEC | 24

## CHAPTER 7

## MICROCONTROLLER ASSEMBLY MODULE

## 7.0 ARDUINO MEGA 2560

### 7.1 DESCRIPTION

The Arduino MEGA 2560 is designed for projects that require

more I/O lines, more sketch memory and more RAM. With 54 digital

I/O pins, 16 analog inputs and a larger space for your sketch it is the

recommended board for 3D printers and robotics projects. The Arduino

Mega 2560 is programmed using the software (IDE) our Integrated

Development Environment common to all our boards and running

both online and offline.

### 7.2 FEATURES OF ARDUINO MEGA 2560

- The ATmega2560 is a Microcontroller
- The operating voltage of this microcontroller is 5volts
- The recommended Input Voltage will range from 7volts to 12volts
- The input voltage will range from 6volts to 20volts
- The digital input/output pins are 54 where 15 of these pins will

supply PWM o/p.

- Analog Input Pins are 16
- DC Current for each input/output pin is 40 mA
- DC Current used for 3.3V Pin is 50 mA
- Flash Memory like 256 KB where 8 KB of flash memory is used with

the help of bootloader

- The static random access memory (SRAM) is 8 KB


DIPLOMA IN MECHATRONICS - NEC | 25
- | The | electrically | erasable | programmable | read-only | memory

(EEPROM) is 4 KB

- The clock (CLK) speed is 16 MHz
- The USB host chip used in this is MAX3421E PIN CONFIGURATION:

DIPLOMA IN MECHATRONICS - NEC | 26

PIN DESCRIPTION:

PIN DIAGRAM EXPANATION:

VIN:

The input voltage to the Arduino board when it's using an

external power source (as opposed to 5 volts from the USB connection

or other regulated power source). You can supply voltage through this

pin, or, if supplying voltage via the power jack, access it through this

pin.

DIPLOMA IN MECHATRONICS - NEC | 27

5V:

The regulated power supply used to power the microcontroller

and other components on the board. This can come either from VIN via

an on-board regulator, or be supplied by USB or another regulated 5V

supply.

3V3:

A 3.3-volt supply generated by the on-board regulator.

Maximum current draw is 50 mA.

GND:

Ground pins.

The ATmega2560 has 256 KB of flash memory for storing code

(of which 8 KB is used for the bootloader), 8 KB of SRAM and 4 KB of

EEPROM (which can be read and written with the EEPROM library).

Each of the 54 digital pins on the Mega can be used as an input

or output, using pin Mode (), digital Write (), and digital Read ()

functions. They operate at 5 volts. Each pin can provide or receive a

maximum of 40 mA and has an internal pull-up resistor (disconnected

by default) of 20-50k Ohms. In addition, some pins have specialized

functions:

DIPLOMA IN MECHATRONICS - NEC | 28

Serial: 0 (RX) and 1 (TX); Serial 1: 19 (RX) and 18

(TX); Serial 2: 17 (RX) and 16 (TX); Serial 3: 15 (RX)

and 14 (TX):

Used to receive (RX) and transmit (TX) TTL serial data. Pins 0

and 1 are also connected to the corresponding pins of the ATmega8U2

USB-to-TTL Serial chip.

External Interrupts:

2 (interrupt 0), 3 (interrupt 1), 18 (interrupt 5), 19 (interrupt 4),

20 (interrupt 3), and 21 (interrupt 2). These pins can be configured to

trigger an interrupt on a low value, a rising or falling edge, or a change

in value. See the attach Interrupt () function for details.

PWM:

0 to 13. Provide 8-bit PWM output with the analog Write ()

function.

SPI:

50 (MISO), 51 (MOSI), 52 (SCK), 53 (SS). These pins support

SPI communication, which, although provided by the underlying

hardware, is not currently included in the Arduino language. The SPI

pins are also broken out on the ICSP header, which is physically

compatible with the Demilanove and Diecimila.

DIPLOMA IN MECHATRONICS - NEC | 29

LED:

13. There is a built-in LED connected to digital pin 13. When the

pin is HIGH value, the LED is on, when the pin is LOW, it's off.

I2C:

20 (SDA) and 21 (SCL). Support I2C (TWI) communication using

the Wire library (documentation on the Wiring website). Note that

these pins are not in the same location as the I2C pins on the

Duemilanove.

AREF:

Reference voltage for the analog inputs. Used with analog

Reference ().

Reset:

Bring this line LOW to reset the microcontroller. Typically used

to add a reset button to shields which block the one on the board.

PIN MAPPIMG TABLE:

Pin Number | Pin Name | Mapped Pin Name
1 | PG5 (OC0B) | Digital pin 4 (PWM)
2 | PE0 (RXD0/PCINT8) | Digital pin 0 (RX0)
3 | PE1 (TXD0) | Digital pin 1 (TX0)
4 | PE2 (XCK0/AIN0)
5 | PE3 (OC3A/AIN1) | Digital pin 5 (PWM)

DIPLOMA IN MECHATRONICS - NEC | 30
6 | PE4 (OC3B/INT4) | Digital pin 2 (PWM)
7 | PE5 (OC3C/INT5) | Digital pin 3 (PWM)
8 | PE6 (T3/INT6)
9 | PE7 (CLKO/ICP3/INT7)
10 | VCC | VCC
11 | GND | GND
12 | PH0 (RXD2) | Digital pin 17 (RX2)
13 | PH1 (TXD2) | Digital pin 16 (TX2)
14 | PH2 (XCK2)
15 | PH3 (OC4A) | Digital pin 6 (PWM)
16 | PH4 (OC4B) | Digital pin 7 (PWM)
17 | PH5 (OC4C) | Digital pin 8 (PWM)
18 | PH6 (OC2B) | Digital pin 9 (PWM)
19 | PB0 (SS/PCINT0) | Digital pin 53 (SS)
20 | PB1 (SCK/PCINT1) | Digital pin 52 (SCK)
21 | PB2 (MOSI/PCINT2) | Digital pin 51 (MOSI)
22 | PB3 (MISO/PCINT3) | Digital pin 50 (MISO)
23 | PB4 (OC2A/PCINT4) | Digital pin 10 (PWM)
24 | PB5 (OC1A/PCINT5) | Digital pin 11 (PWM)
25 | PB6 (OC1B/PCINT6) | Digital pin 12 (PWM)

DIPLOMA IN MECHATRONICS - NEC | 31
26 | PB7 (OC0A/OC1C/PCINT7) | Digital pin 13 (PWM)
27 | PH7 (T4)
28 | PG3 (TOSC2)
29 | PG4 (TOSC1)
30 | RESET | RESET
31 | VCC | VCC
32 | GND | GND
33 | XTAL2 | XTAL2
34 | XTAL1 | XTAL1
35 | PL0 (ICP4) | Digital pin 49
36 | PL1 (ICP5) | Digital pin 48
37 | PL2 (T5) | Digital pin 47
38 | PL3 (OC5A) | Digital pin 46 (PWM)
39 | PL4 (OC5B) | Digital pin 45 (PWM)
40 | PL5 (OC5C) | Digital pin 44 (PWM)
41 | PL6 | Digital pin 43
42 | PL7 | Digital pin 42
43 | PD0 (SCL/INT0) | Digital pin 21 (SCL)
44 | PD1 (SDA/INT1) | Digital pin 20 (SDA)
45 | PD2 (RXDI/INT2) | Digital pin 19 (RX1)
46 | PD3 (TXD1/INT3) | Digital pin 18 (TX1)

DIPLOMA IN MECHATRONICS - NEC | 32
47 | PD4 (ICP1)
48 | PD5 (XCK1)
49 | PD6 (T1)
50 | PD7 (T0) | Digital pin 38
51 | PG0 (WR) | Digital pin 41
52 | PG1 (RD) | Digital pin 40
53 | PC0 (A8) | Digital pin 37
54 | PC1 (A9) | Digital pin 36
55 | PC2 (A10) | Digital pin 35
56 | PC3 (A11) | Digital pin 34
57 | PC4 (A12) | Digital pin 33
58 | PC5 (A13) | Digital pin 32
59 | PC6 (A14) | Digital pin 31
60 | PC7 (A15) | Digital pin 30
61 | VCC | VCC
62 | GND | GND
63 | PJ0 (RXD3/PCINT9) | Digital pin 15 (RX3)
64 | PJ1 (TXD3/PCINT10) | Digital pin 14 (TX3)
65 | PJ2 (XCK3/PCINT11)
66 | PJ3 PCINT12)
67 | PJ4 (PCINT13)

DIPLOMA IN MECHATRONICS - NEC | 33
68 | PJ5 (PCINT14)
69 | PJ6 (PCINT 15)
70 | PG2 ALE) | Digital pin 39
71 | PA7 (AD7) | Digital pin 29
72 | PA6 (AD6) | Digital pin 28
73 | PA5 (AD5) | Digital pin 27
74 | PA4 (AD4) | Digital pin 26
75 | PA3 (AD3) | Digital pin 25
76 | PA2 (AD2) | Digital pin 24
77 | PA1 (AD1) | Digital pin 23
78 | PA0 (AD0) | Digital pin 22
79 | PJ7
80 | VCC | VCC
81 | GND | GND
82 | PK7 (ADC15/PCINT23) | Analog pin 15
83 | PK6 (ADC14/PCINT22) | Analog pin 14
84 | PK5 (ADC13/PCINT21) | Analog pin 13
85 | PK4 (ADC12/PCINT20) | Analog pin 12
86 | PK3 (ADC11/PCINT19) | Analog pin 11
87 | PK2 (ADC10/PCINT18) | Analog pin 10
88 | PK1 (ADC9/PCINT17) | Analog pin 9

DIPLOMA IN MECHATRONICS - NEC | 34
89 | PK0 (ADC8/PCINT16) | Analog pin 8
90 | PF7 (ADC7/TDI) | Analog pin 7
91 | PF6 (ADC6/TDO) | Analog pin 6
92 | PF5 (ADC5/TMS) | Analog pin 5
93 | PF4 (ADC4/TCK) | Analog pin 4
94 | PF3 (ADC3) | Analog pin 3
95 | PF2 (ADC2) | Analog pin 2
96 | PF1 (ADC1) | Analog pin 1
97 | PF0 (ADC0) | Analog pin 0
98 | AREF | Analog Reference
99 | GND | GND
100 | AVCC | VCC


DIPLOMA IN MECHATRONICS - NEC | 35

### 7.3 SCHEMATIC DIAGRAM:

DIPLOMA IN MECHATRONICS - NEC | 36

### 7.4 BILL OF MATERIAL

SL NO | Item description | symbol | Qty | Price(₹)
1 | ATMEGA2560 | U1 | 1 | 27
2 | POWERSUPPLY_DC21MM | U2 | 1 | 19
| 47UF | PC1 | 1 | 3
4 | 0.1UF | C1, C4, C5, C6, C7, C3, C9, C12, C13, C15 | 10 | 7
5 | RESONATOR | Y1 | 1 | 5
6 | NCP1117ST50T3G | IC1 | 1 | 6
7 | 1M | R1, R3 | 2 | 3
8 | M7 | D1 | 1 | 6
9 | 18X2F-H8.5 | XIO | 1 | 6
10 | 8X1F-H8.5 | POWER, ADCH, COMMUNICATION, PWML, ADCL | 5 | 20
11 | TS42031-160R-TR-7260 | RESET | 1 | 5
12 | 10X1F-H8.5 | JP1 | 1 | 6

DIPLOMA IN MECHATRONICS - NEC | 37
13 | CD1206-S01575 | D3, D2 | 2 | 8
14 | 22PF | C8, C10, C11 | 3 | 3
15 | 3X2M | ICSP, ICSP1 | 2 | 8
16 | 1UF | C2, C14 | 2 | 2
17 | LP2985-33DBVR | IC3 | 1 | 9
18 | FDN340P | T1 | 1 | 50
19 | 2X2M – NM | JP2 | 1 | 33
20 | 16MHZ | Y2 | 1 | 19
21 | USB-B_TH | X1 | 1 | 80
22 | MF-MSMF050-2 500MA | F1 | 1
23 | CG0603MLC-05E | Z1, Z2 | 2 | 49
24 | BLM21 | L1 | 1 | 12
25 | SJ | GROUND, RESET-EN | 2 | 30
26 | ATMEGA16U2 | U5 | 1 | 16
27 | 47U | PC2 | 1 | 17

DIPLOMA IN MECHATRONICS - NEC | 38
28 | GREEN | ON | 1 | 2
29 | YELLOW | L, TX, RX | 3 | 2
30 | 1u (https://easyeda.com/component/994f4acf33ff4e66aaa5dbbeb5e3fa4f) | C16, C18 | 2 | 1
31 | 1u (https://easyeda.com/component/73cf4db60ff344f8a415b734dfaec7a1) | C17, C19 | 2 | 2
32 | 1N4448 (https://easyeda.com/component/1f840c1ab0fc8dd5c06f5170f6febdd2) | D4, D5 | 2 | 8
33 | 1k (https://easyeda.com/component/5ba509f895244278a1309c0031b47188) | R2, R4 | 2 | 2
34 | Оптопара (https://easyeda.com/component/901765d22a3f4b5bbb75a09bf7adf945) | U3, U4 | 2 | 26
35 | BC847AWT1G (https://easyeda.com/component/1e5139edd73d4da4b58b2ce887ac698c) | Q1, Q2 | 2 | 50
36 | LMV358IDGKR | IC2 | 1 | 69
37 | 1K | RN1, RN7 | 2 | 12
38 | 10K | RN2, RN3 | 2 | 12
39 | 22R | RN4 | 1 | 12
TOTAL | | | 700


DIPLOMA IN MECHATRONICS - NEC | 39

## JOHNSON MOTOR WITH L298N MOTOR

## DRIVER

CONTENTS

- DESCRIPTION
- PIN DIAGRAM
- SCHEMATIC DIAGRAM
- BILL OF MATERIALS

DIPLOMA IN MECHATRONICS - NEC | 40

## CHAPTER 8

## 8.0 JOHNSON MOTOR WITH L298N MOTOR

## DRIVER

### 8.1 DESCRIPTION

L298N MOTOR DRIVER

This dual bidirectional motor driver, is based on the very popular

L298 Dual H-Bridge Motor Driver Integrated Circuit. The circuit will allow

you to easily and independently control two motors of up to 2A each in

both directions. It is ideal for robotic applications and well suited for

connection to a microcontroller requiring just a couple of control lines

per motor. It can also be interfaced with simple manual switches, TTL

logic gates, relays, etc. This board equipped with power LED indicators,

on-board +5V regulator and protection diodes.

FEATURES

- Input Voltage: 3.2V~40Vdc. Brief Data:
- Driver: L298N Dual H Bridge DC Motor Driver
- Power Supply: DC 5 V - 35 V
- Peak current: 2 Amp
- Operating current range: 0 ~ 36mA
- Low: -0.3V ≤ Vin ≤ 1.5V.
- High: 2.3V ≤ Vin ≤ Vss.
- Maximum power consumption: 20W (when the temperature

T = 75 ℃).

DIPLOMA IN MECHATRONICS - NEC | 41

JOHNSON MOTOR:

It is a simple DC motor featuring metal gearbox for driving the

shaft of the motor, so it is a mechanically commutated electric motor

which is powered from DC supply. The Johnson Geared Motors are

known for their compact size and massive torque-speed characteristic.

The Johnson Motor comes with side shaft also known as an off-

centered shaft and six M3 mounting holes. The shaft of the motor

equips metal bushes which makes these DC gear motors Shaft wear

resistant. The shaft of the motor has a hole for better coupling.

FEATURES:

- 10RPM 12V DC motors with Metal Gearbox and Metal Gears
- 18000 RPM base motor
- 6mm Dia shaft with M3 thread hole
- Gearbox diameter 37 mm.
- Motor Diameter 28.5 mm
- Length 63 mm without shaft
- Shaft length 30mm
- 180gm weight
- 120kgcm Holding Torque
- No-load current = 800 mA, Load current = upto 7.5 A(Max)
- Recommended to be used with DC Motor Driver 20A (https://robokits.co.in/shop/index.php?main_page=product_info&cPath=73&products_id=334) or Dual DC

Motor Driver 20A (https://robokits.co.in/shop/index.php?main_page=product_info&cPath=73&products_id=342)

DIPLOMA IN MECHATRONICS - NEC | 42

### 8.2 PIN DIAGRAM:

### 8.3 SCHEMATIC DIAGRAM:

DIPLOMA IN MECHATRONICS - NEC | 43

### 8.4 BILL OF MATERIALS:

SL.NO | Item Description | Symbol | Qty | Price (₹)
1 | L298 | U2 | 1 | 20
2 | L297DIL20-1 | U1 | 1 | 5
3 | KF301-5.0 2P | J3, J4, J5, J6, J7, J8 | 5 | 20
4 | LM7805EE | U3 | 1 | 50
5 | 470uf | C1 | 1 | 2
6 | 220uf | C2 | 1 | 2
7 | PIN 3 | J1, J2 | 2 | 10
8 | 10k | R1, R2 | 2 | 2
9 | CAP 0805 | C4, C3 | 2 | 8
10 | 22uf | C5 | 1 | 2
11 | 1N4007 | D1, D2, D3, D4, D5, D6, D7, D8 | 8 | 15
12 | 1 Ohm | R4, R10 | 2 | 3
13 | 22k | R5, R7 | 2 | 3
14 | 332 uf | C7 | 1 | 3
15 | 5kOhm | R6 | 1 | 2
TOTAL | | | | 147

DIPLOMA IN MECHATRONICS - NEC | 44

TOTAL BILL OF MATERIALS:

SL.NO | Item Description | Symbol | Qty | Price (₹)
1 | Motor Driver (L298N) | L1 | 1 | 147
2 | Johnson Motor | M1 | 1 | 150
TOTAL | | | | 297

MODULE 04

DIPLOMA IN MECHATRONICS - NEC | 45

SG-90 SERVO MOTOR DRIVER

CONTENTS

- DESCRIPTION
- PIN DIAGRAM
- FEATURES
- BILL OF MATERIALS


DIPLOMA IN MECHATRONICS - NEC | 46

## CHAPTER 9

## 9.0 SG-90 SERVO MOTOR

### 9.1 DESCRIPTION

The TowerPro SG90 9g Mini Servo is 180° rotation servo. It is a

Digital Servo Motor which receives and processes PWM signal faster and

better. It equips sophisticated internal circuitry that provides good

torque, holding power, and faster updates in response to external

forces.

### 9.2 PIN DIAGRAM:

### 9.3 FEATURES

- Operating Voltage is +5V typically
- Torque: 2.5kg/cm
- Operating speed is 0.1s/60°
- Gear Type: Plastic
- Rotation: 0°-180°
- Weight of motor: 9gm

DIPLOMA IN MECHATRONICS - NEC | 47

### 9.4 BILL OF MATERIALS

SL.NO | Item Description | Symbol | Qty | Price (₹)
1 | Servo Motor (SG-90) | SM1, SM2 | 2 | 150X2
TOTAL | | | | 300


DIPLOMA IN MECHATRONICS - NEC | 48

MG995 SERVO MOTOR DRIVER

CONTENTS

- DESCRIPTION
- PIN DIAGRAM
- FEATURES
- BILL OF MATERIALS

DIPLOMA IN MECHATRONICS - NEC | 49

## CHAPTER 10

## 10.0 MG995 SERVO MOTOR

### 10.1 DESCRIPTION

The high-speed standard servo can rotate approximately 120

degrees (60 in each direction). We can use any servo code, hardware or

library to control these servos, so gear box, especially since it will fit in

small places. It equips sophisticated internal circuitry that provides good

torque, holding power, and faster updates in response to external

forces.

### 10.2 PIN DIAGRAM

PIN CONFIGURATION

MG995 has three terminals as mentioned in pin diagram and the function of each pin is given below.

Pin | Name | Function
1 | Signal pin (Orange pin) | The PWM signal which states the axis position is given through this pin.

DIPLOMA IN MECHATRONICS - NEC | 50
2 | VCC (Red pin) | Positive power supply for servo motor is given to this pin.
3 | Ground (Brown pin) | This pin is connected to ground of circuit or power supply.

### 10.3 FEATURES:

- Weight: 55g
- Dimension: 40.7 × 19.7 × 42.9 mm
- Operating Speed (4.8V no load): 20sec / 60 deg
- Operating Speed (6.0V no load): 16sec / 60 deg (no load)
- Stall Torque (4.8V): 10kg/cm
- Stall Torque (6.0V): 12kg/cm
- Operation Voltage: 4.8 - 7.2Volts
- Gear Type: All Metal Gears
- Stable and shock proof double ball bearing design
- Dead band width: 5 µs
- Temperature range: 0 ºC – 55 ºC.

### 10.4 BILL OF MATERIALS

SL.NO | Item Description | Symbol | Qty | Price (₹)
1 | Servo Motor (MG-995) | SM3, SM4, SM5 | 3 | 200X3
TOTAL | | | | 600

DIPLOMA IN MECHATRONICS - NEC | 51

DHT-11 (TEMPERATURE AND HUMIDITY SENSOR)

CONTENTS

- DESCRIPTION
- PIN DIAGRAM
- FEATURES
- BILL OF MATERIALS


DIPLOMA IN MECHATRONICS - NEC | 52

## CHAPTER 11

## 11.0 DHT11 (TEMPERATURE AND HUMIDITY

## SENSOR)

### 11.1 DESCRIPTION:

It uses a capacitive humidity sensor and a thermistor to

measure the surrounding air, and spits out a digital signal on the data

pin. The only real downside of this sensor is you can only get new data

from it once every 2 Sec. This sensor includes a resistive-type humidity

measurement component and an NTC temperature measurement

component, and connects to a high-performance 8-bit microcontroller,

offering excellent quality, fast response, anti-interference ability and

cost-effectiveness. Each DHT11 element is strictly calibrated in the

laboratory that is extremely accurate on humidity calibration. The

calibration coefficients are stored as programs in the OTP memory,

which are used by the sensor’s internal signal detecting process. The

single-wire serial interface makes system integration quick and easy.

Its small size, low power consumption and upto 20-meter signal

transmission making it the best choice for various applications,

including those most demanding ones.

### 11.2 PIN DIAGRAM:

DIPLOMA IN MECHATRONICS - NEC; PIN DISCRIPTION; Pin 2 NC, empty pin; Pin 4 GND ground, the negative power; 11.3 FEATURES; • Operating Voltage: 3.5V to 5.5V; • Output: Serial data; • Temperature Range: 0°C to 50°C; • Humidity Range: 20% to 90%; • Accuracy: ±1°C and ±1%; 11.4 BILL OF MATERIALS; Item Description; Symbol; Qty; Price (₹); DHT-11; TOTAL

Pin 1 is the VDD power supply 3.5～5.5V DC

Pin 2 is for DATA serial data, a single bus

- Operating current: 0.3mA (measuring) 60uA (standby)
- Resolution: Temperature and Humidity both are 16-bit

MODULE 07

DIPLOMA IN MECHATRONICS - NEC | 54

MQ-5 (GAS SENSOR)

CONTENTS

- DESCRIPTION
- PIN DIAGRAM
- SCHEMATIC DIAGRAM
- BILL OF MATERIALS


DIPLOMA IN MECHATRONICS - NEC | 55

## CHAPTER 12

## 12.0 MQ-5 (GAS SENSOR)

### 12.1 DESCRIPTION

The MQ5 Gas Sensor module is useful for gas leakage

detecting. It can detect LPG, i-butane, methane, alcohol, Hydrogen,

CO2. The sensitivity can be adjusted using the on-board potentiometer,

and you'd use this sensor by reading the analog pin to which it is

connected.

### 12.2 PIN DIAGRAM

DIPLOMA IN MECHATRONICS - NEC | 56

### 12.3 SCHEMATIC DIAGRAM:

DIPLOMA IN MECHATRONICS - NEC | 57

### 12.4 BILL OF MATERIALS

SL.NO | Item Description | Symbol | Qty | Price (₹)
1 | LM393, Boost Converter | U1 | 1 | 10
2 | 2.7M ohm | R1 | 1 | 2
3 | 910K ohm | R2 | 1 | 2
4 | 10uH | L1 | 1 | 13
5 | 100uf | C1 | 1 | 2
6 | 100uf | C2 | 1 | 2
7 | 100nf | C3 | 1 | 2
8 | 1N5819, LED | D1 | 1 | 5
9 | HDR2X3 | P1 | 1 | 5
10 | LM393 | U2 | 1 | 40
11 | LED | D2, D3 | 2 | 3
12 | 1uf | C4 | 1 | 3
13 | 1k ohm | R3, R4 | 2 | 3
14 | SIP4 | P2 | 1 | 2
15 | 4.7k ohm | R5 | 1 | 2
16 | 5R1 ohm | R6 | 1 | 2
17 | 100k ohm | R7 | 1 | 2
TOTAL | | | | 100

MODULE 08

DIPLOMA IN MECHATRONICS - NEC | 58

## INDUCTIVE PROXIMITY SENSOR

CONTENTS

- DESCRIPTION
- PIN DIAGRAM
- FEATURES
- BILL OF MATERIALS


DIPLOMA IN MECHATRONICS - NEC | 59

## CHAPTER 13

## 13.0 INDUCTIVE PROXIMITY SENSOR

### 13.1 DESCRIPTION

An inductive sensor is a device that uses the principle

of electromagnetic induction to detect or measure objects. An inductor

develops a magnetic field when a current flow through it; alternatively,

a current will flow through a circuit containing an inductor when the

magnetic field through it changes. This effect can be used to detect

metallic objects that interact with a magnetic field. Non-metallic

substances such as liquids or some kinds of dirt do not interact with

the magnetic field.

### 13.2 PIN DIAGRAM

### 13.3 FEATURES

- Red LED checks the state of the proximity sensor
- High repeated positioning accuracy
- High switching frequency
- Wide voltage range

DIPLOMA IN MECHATRONICS - NEC | 60
- Outer (Thread) Diameter: M12
- Antivibration, dust, water and oil prevention

### 13.4 BILL OF MATERIALS

SL.NO | Item Description | Symbol | Qty | Price (₹)
1 | Inductive Proximity Sensor | IP1 | 1 | 200
TOTAL | | | | 200


DIPLOMA IN MECHATRONICS - NEC | 61

## BLUETOOTH MODULE(HC-05)

CONTENTS

- DESCRIPTION
- PIN DIAGRAM
- FEATURES
- BILL OF MATERIALS

DIPLOMA IN MECHATRONICS - NEC | 62

## CHAPTER 14

## 14.0 BLUETOOTH MODULE(HC-05)

### 14.1 DESCRIPTION

The HC-05 has two operating modes, one is the Data mode in

which it can send and receive data from other Bluetooth devices and

the other is the AT Command mode where the default device settings

can be changed. We can operate the device in either of these two

modes by using the key pin as explained in the pin description.

It is very easy to pair the HC-05 module with microcontrollers

because it operates using the Serial Port Protocol (SPP). Simply power

the module with +5V and connect the Rx pin of the module to the Tx

of MCU and Tx pin of module to Rx of MCU as shown in the figure below

### 14.2 PIN DIAGRAM

DIPLOMA IN MECHATRONICS - NEC | 63

### 14.3 FEATURES

- Serial Bluetooth module for Arduino and other microcontrollers
- Operating Voltage: 4V to 6V (Typically +5V)
- Operating Current: 30mA
- Range: <100m
- Works with Serial communication (USART) and TTL compatible
- Follows IEEE 802.15.1 standardized protocol
- Uses Frequency-Hopping Spread spectrum (FHSS)

### 14.4 BILL OF MATERIALS

SL.NO | Item Description | Symbol | Qty | Price (₹)
1 | BLUETOOTH MODULE | BL1 | 1 | 250
TOTAL | | | | 250

DIPLOMA IN MECHATRONICS - NEC; CHAPTER 15; EXISTING MECHANICAL DESIGN; OVERALL ISOMETRIC VIEW; CHASIS; SPROCKETS; ROLLER CHAIN; MANIPULATOR; SERVO MOTOR; SERVO-ELECTRIC GRIPPER

DIPLOMA IN MECHATRONICS - NEC; IMPROVISED MECHANICAL DESIGN; OVERALL ISOMETRIC VIEW; MECANUM WHEELS; ROBOT ARM; SERVO MOTOR; SERVO-ELECTRIC GRIPPER; CHASIS

DIPLOMA IN MECHATRONICS - NEC | 66

ALL DIMENSIONS ARE IN mm

TOP VIEW

SIDE VIEW

ALL DIMENSIONS ARE IN mm

DIPLOMA IN MECHATRONICS - NEC | 67

FRONT VIEW

ALL DIMENSIONS ARE IN mm

SERVO ELECTRIC-GRIPPER

ALL DIMENSIONS ARE IN mm

DIPLOMA IN MECHATRONICS - NEC | 68

## CHAPTER 16

## 16.0 BILL OF MATERIAL

### 16.1 MODULES

Sl.no | Modules | Individual Price (₹) | Qty | Total Price (₹)
1 | Module1: Charging Circuit | 1280 | 1 | 1280
2 | Module2: Arduino Mega 2560 | 700 | 1 | 700
3 | Module3: L298N with DC Gear motor | 400 | 4 | 1300
4 | Module4:SG-90 | 100 | 3 | 300
5 | Module6:MG-995 | 250 | 3 | 750
6 | Module7:DHT11 | 85 | 1 | 85
7 | Module8:MQ-5 | 100 | 1 | 100
8 | Module9: Inductive Proximity Sensor | 200 | 1 | 200
9 | Module10: Bluetooth module (HC-05) | 250 | 1 | 250
TOTAL | | | | 4,965

DIPLOMA IN MECHATRONICS - NEC | 69

### 16.2 MECHANICAL COMPONENTS

Sl.no | Mechanical components | Specification | Qty | Price (₹)
1 | Screw Nut Spacers | M3*15mm M3.5*0.6mm M3*10mm, M3*35mm | 200g 150g 500g | 200
2 | L-clamps | 20 mm x 20 mm | 20 pieces | 50
3 | plywood | IS 303 Grade (5mm x 500mm X 400mm) | 1 sheet | 200
4 | wheels | 100 mm (R50) | 4 | 500
Total | | | | 950

### 16.3 ELECTRICAL COMPONENTS

Sl.no | Item Description | Specification | Quantity | Price (₹)
1 | Insulation tape | 10.5mm*10m | 1 | 30

DIPLOMA IN MECHATRONICS - NEC | 70

### 16.4 MISCELLANEOUS

Sl.no | Item description | Specifications | Quantity | Price (₹)
1 | Anabond | 202 (Cyanoacrylate Adhesive) | 20ml | 100
2 | Nylon Bush | 25mm | 8 | 40
3 | Plastic loop Lock Pin Tag | 3” | 75g | 30
Total | | | | 170
2 | Sleeves | Ø1mm Ø3mm Ø6mm | 2m 2m 2m | 30 40 40
3 | Connecting Wires | Multi Stranded (24 AWG, 10 AWG) | 10m | 150
Total | | | | 290

DIPLOMA IN MECHATRONICS - NEC | 71

### 16.5 OVERALL BILL OF MATERIAL

SL NO: | Items | price (₹)
1 | Mechanical Components | 950
2 | Electrical Components | 290
3 | Modules | 4,965
4 | Miscellaneous | 170
5 | 3D Parts for Robotic Arm | 3,200
| Total | 9,575

DIPLOMA IN MECHATRONICS - NEC | 72

## CHAPTER 17

## ADVANTAGES & DISADVANTAGES

ADVANTAGES

- Reducing Man Power
- Fast Production
- Time Management

DISADVANTAGES

- Less Payload Capacity
- Full Manual Controlled
- Limited Operating Range

APPLICATIONS

- Pick & Place
- Industrial Usage
- Component Handling

DIPLOMA IN MECHATRONICS - NEC | 73
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

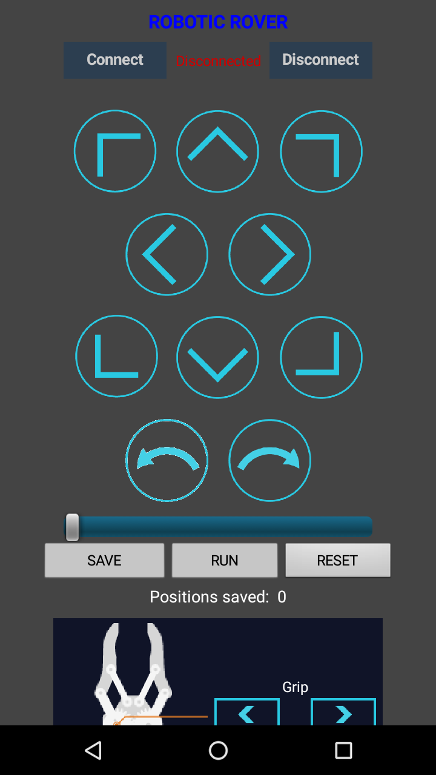
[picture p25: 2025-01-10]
APP_DESIGN_BETA/Screenshot_20200528-095940.png

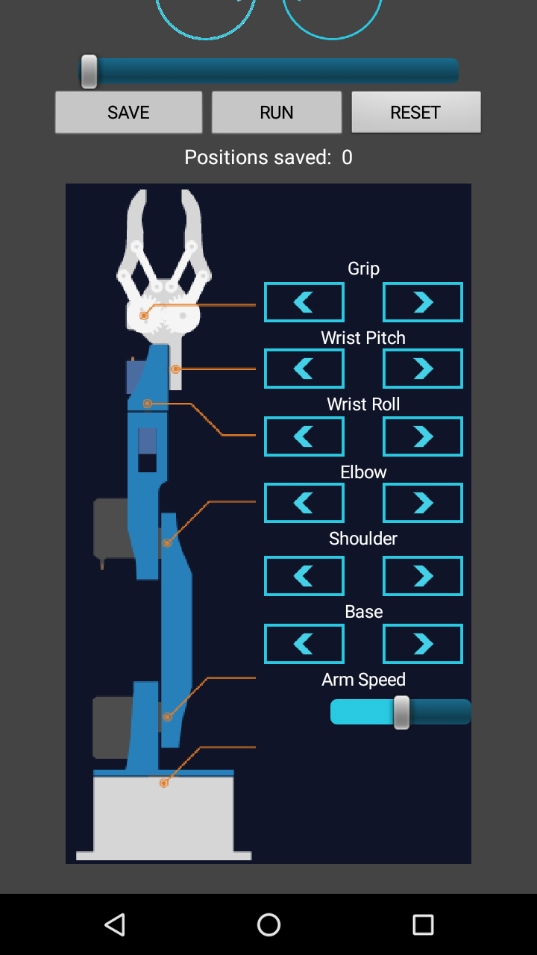
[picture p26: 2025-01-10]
APP_DESIGN_BETA/Screenshot_20200528-095953.png

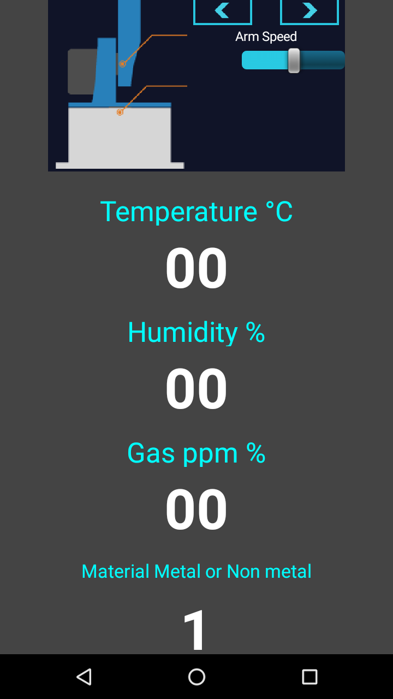
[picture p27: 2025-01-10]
APP_DESIGN_BETA/Screenshot_20200528-095956.png

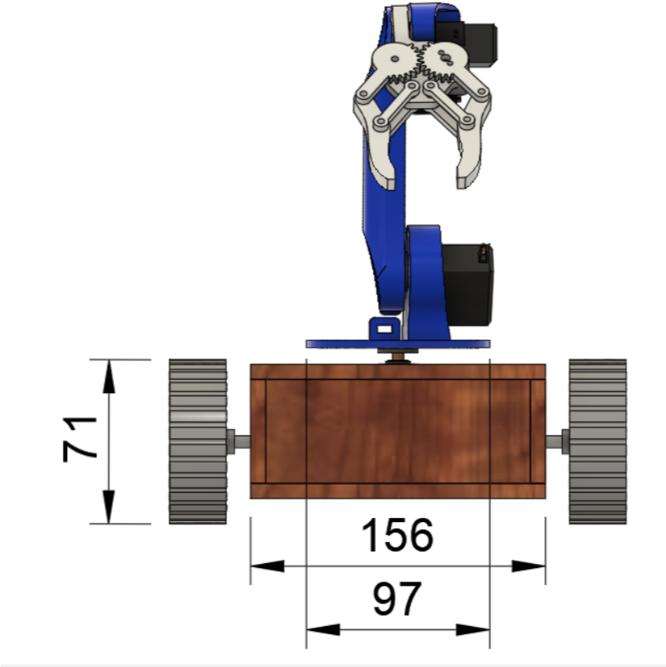
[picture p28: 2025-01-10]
3D/Annotation SIDE2.png

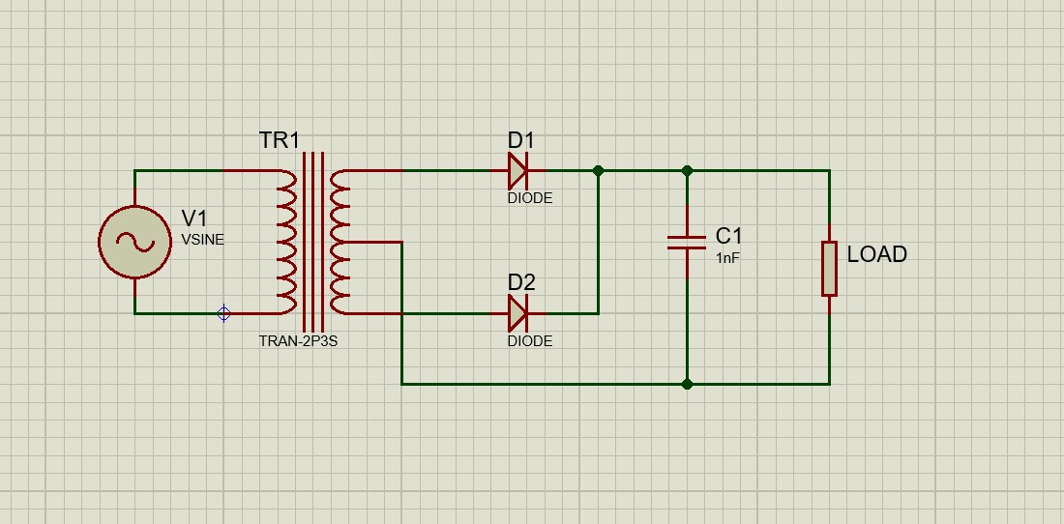
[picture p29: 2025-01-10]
POWER SUPPLY/PS V1.2.PNG.jpg

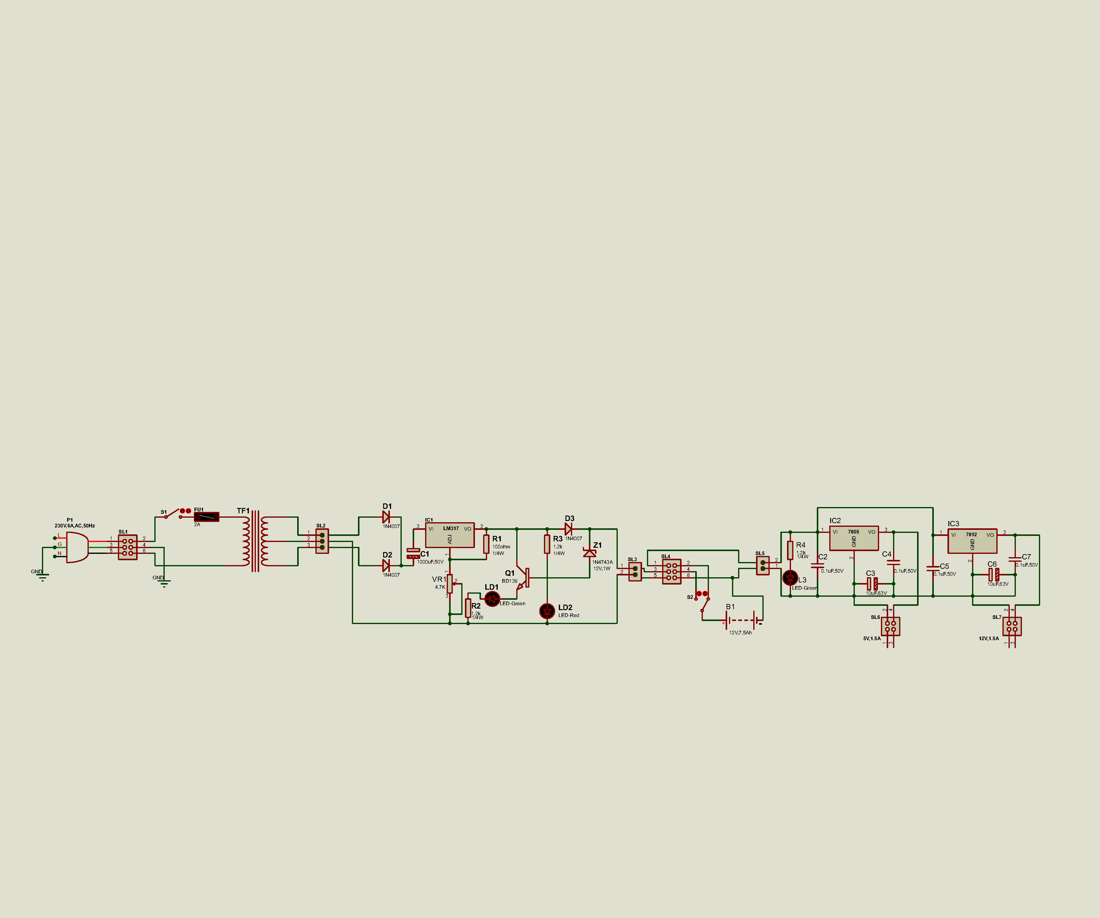
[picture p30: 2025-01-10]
POWER SUPPLY/Power supply.jpg

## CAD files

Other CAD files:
CIRCUIT DIAGRAM/24d7c107-abdc-472a-8ade-f75f3b55037c.f3d
CIRCUIT DIAGRAM/b2ff4013-e0ff-4298-968b-e2247b70c189.f3d

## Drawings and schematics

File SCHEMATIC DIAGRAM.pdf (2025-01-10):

D1

D2

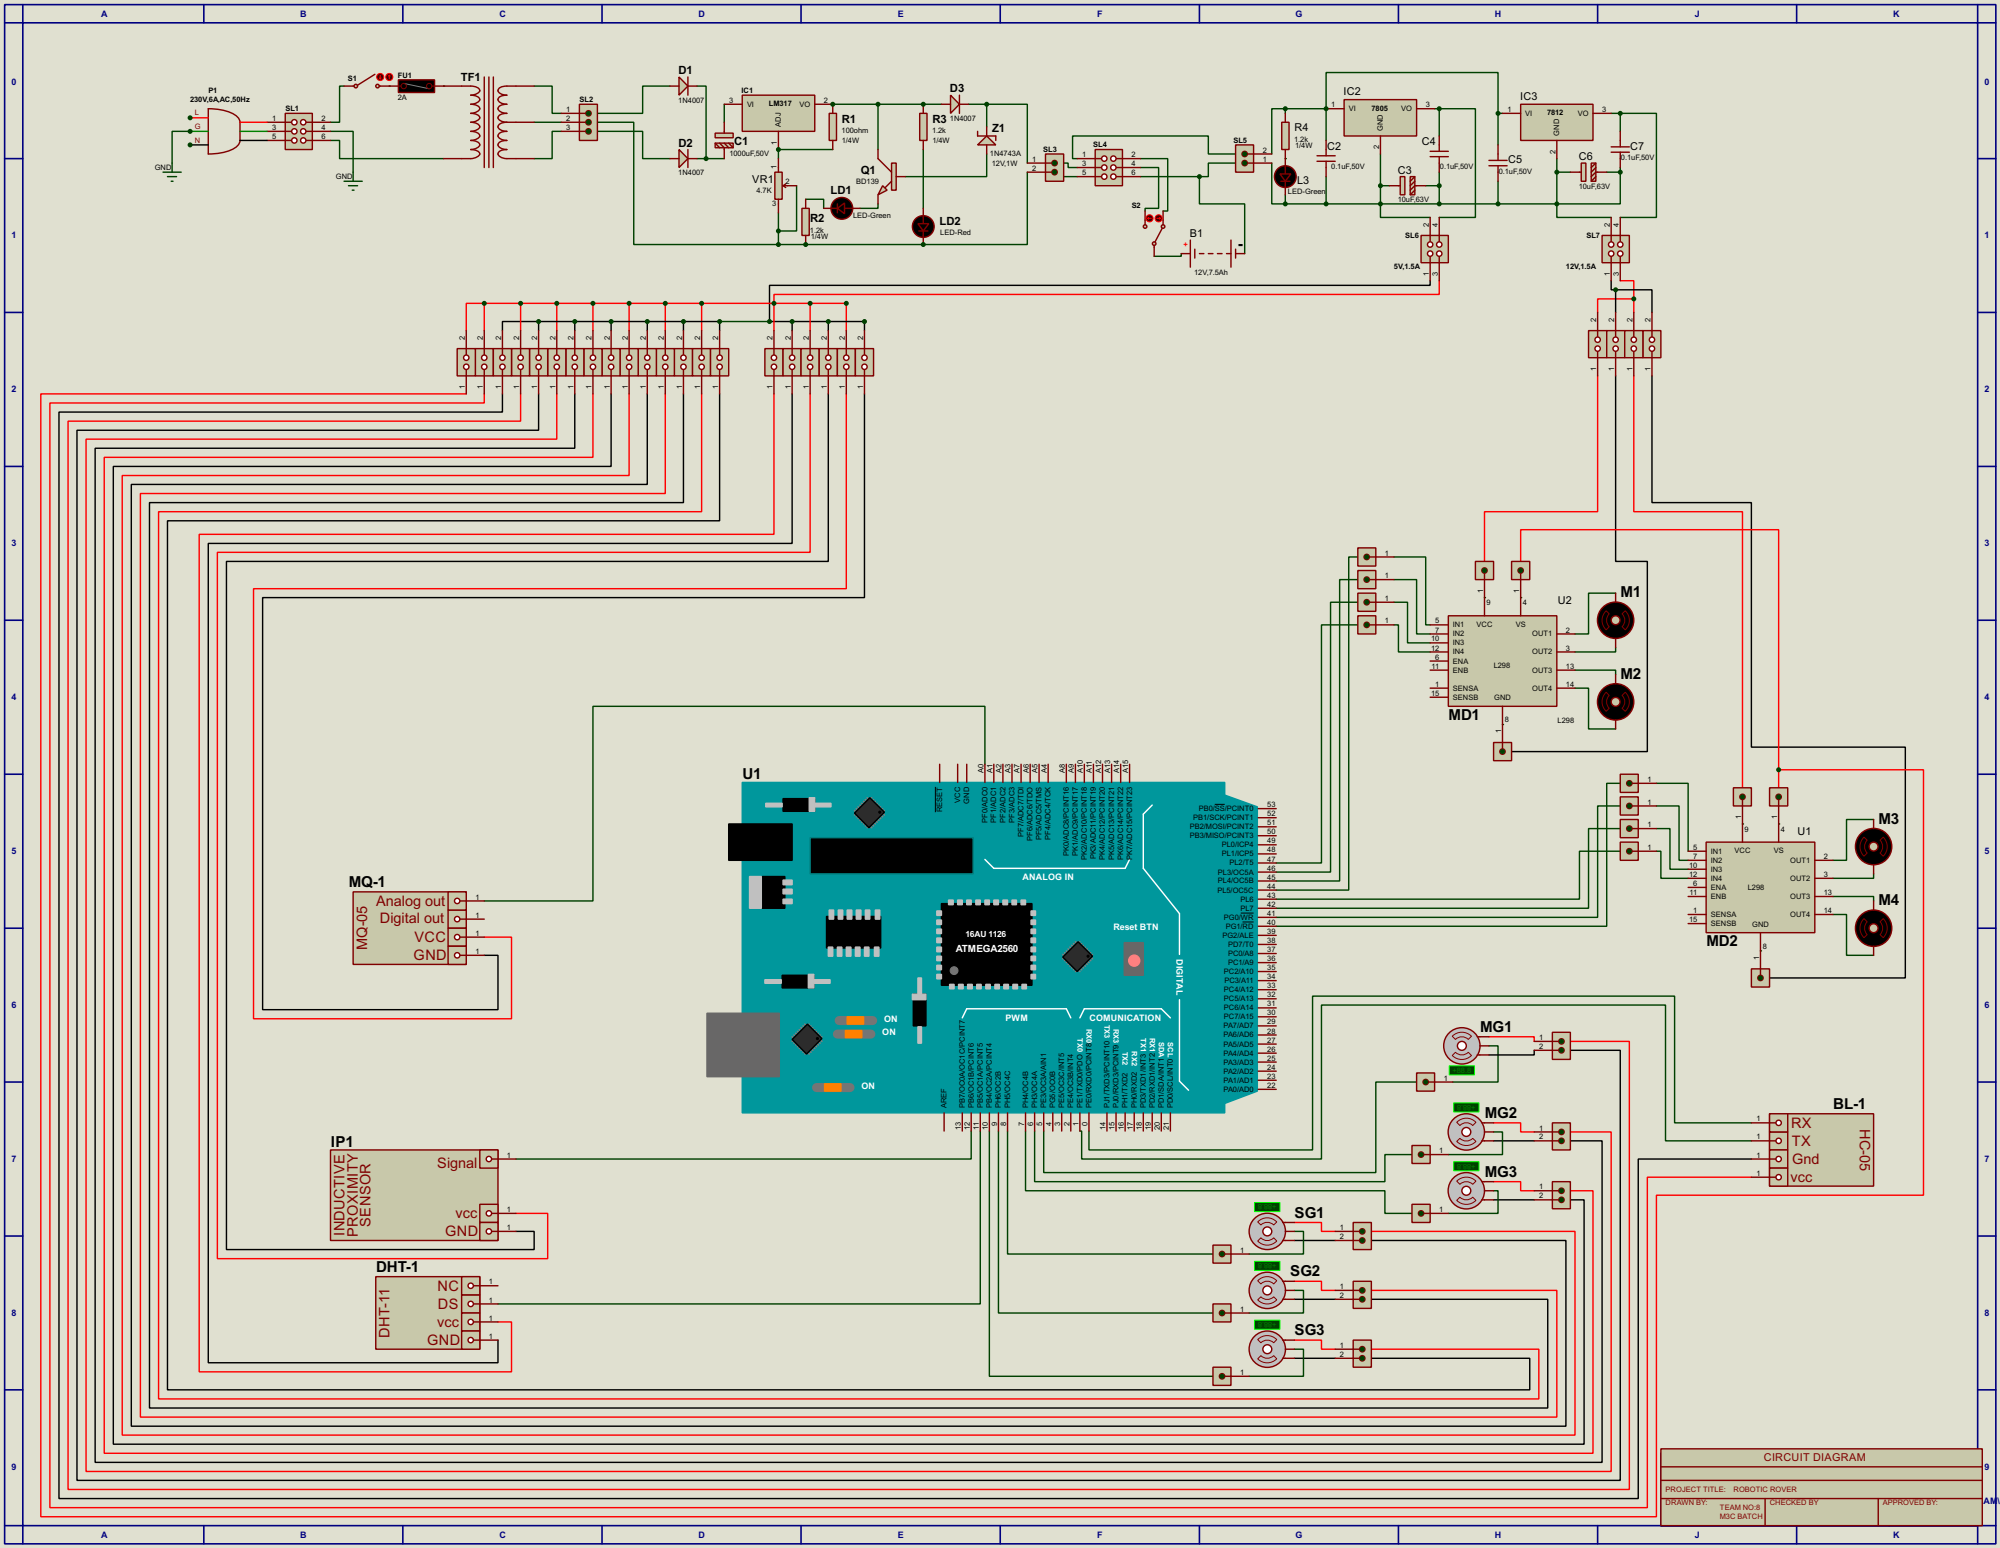
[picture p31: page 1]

FILE NAME:
DESIGN TITLE: CIRCUIT.pdsprj
PROJECT TITLE: ROBOTIC ROVER

12V,1A
5V,1A

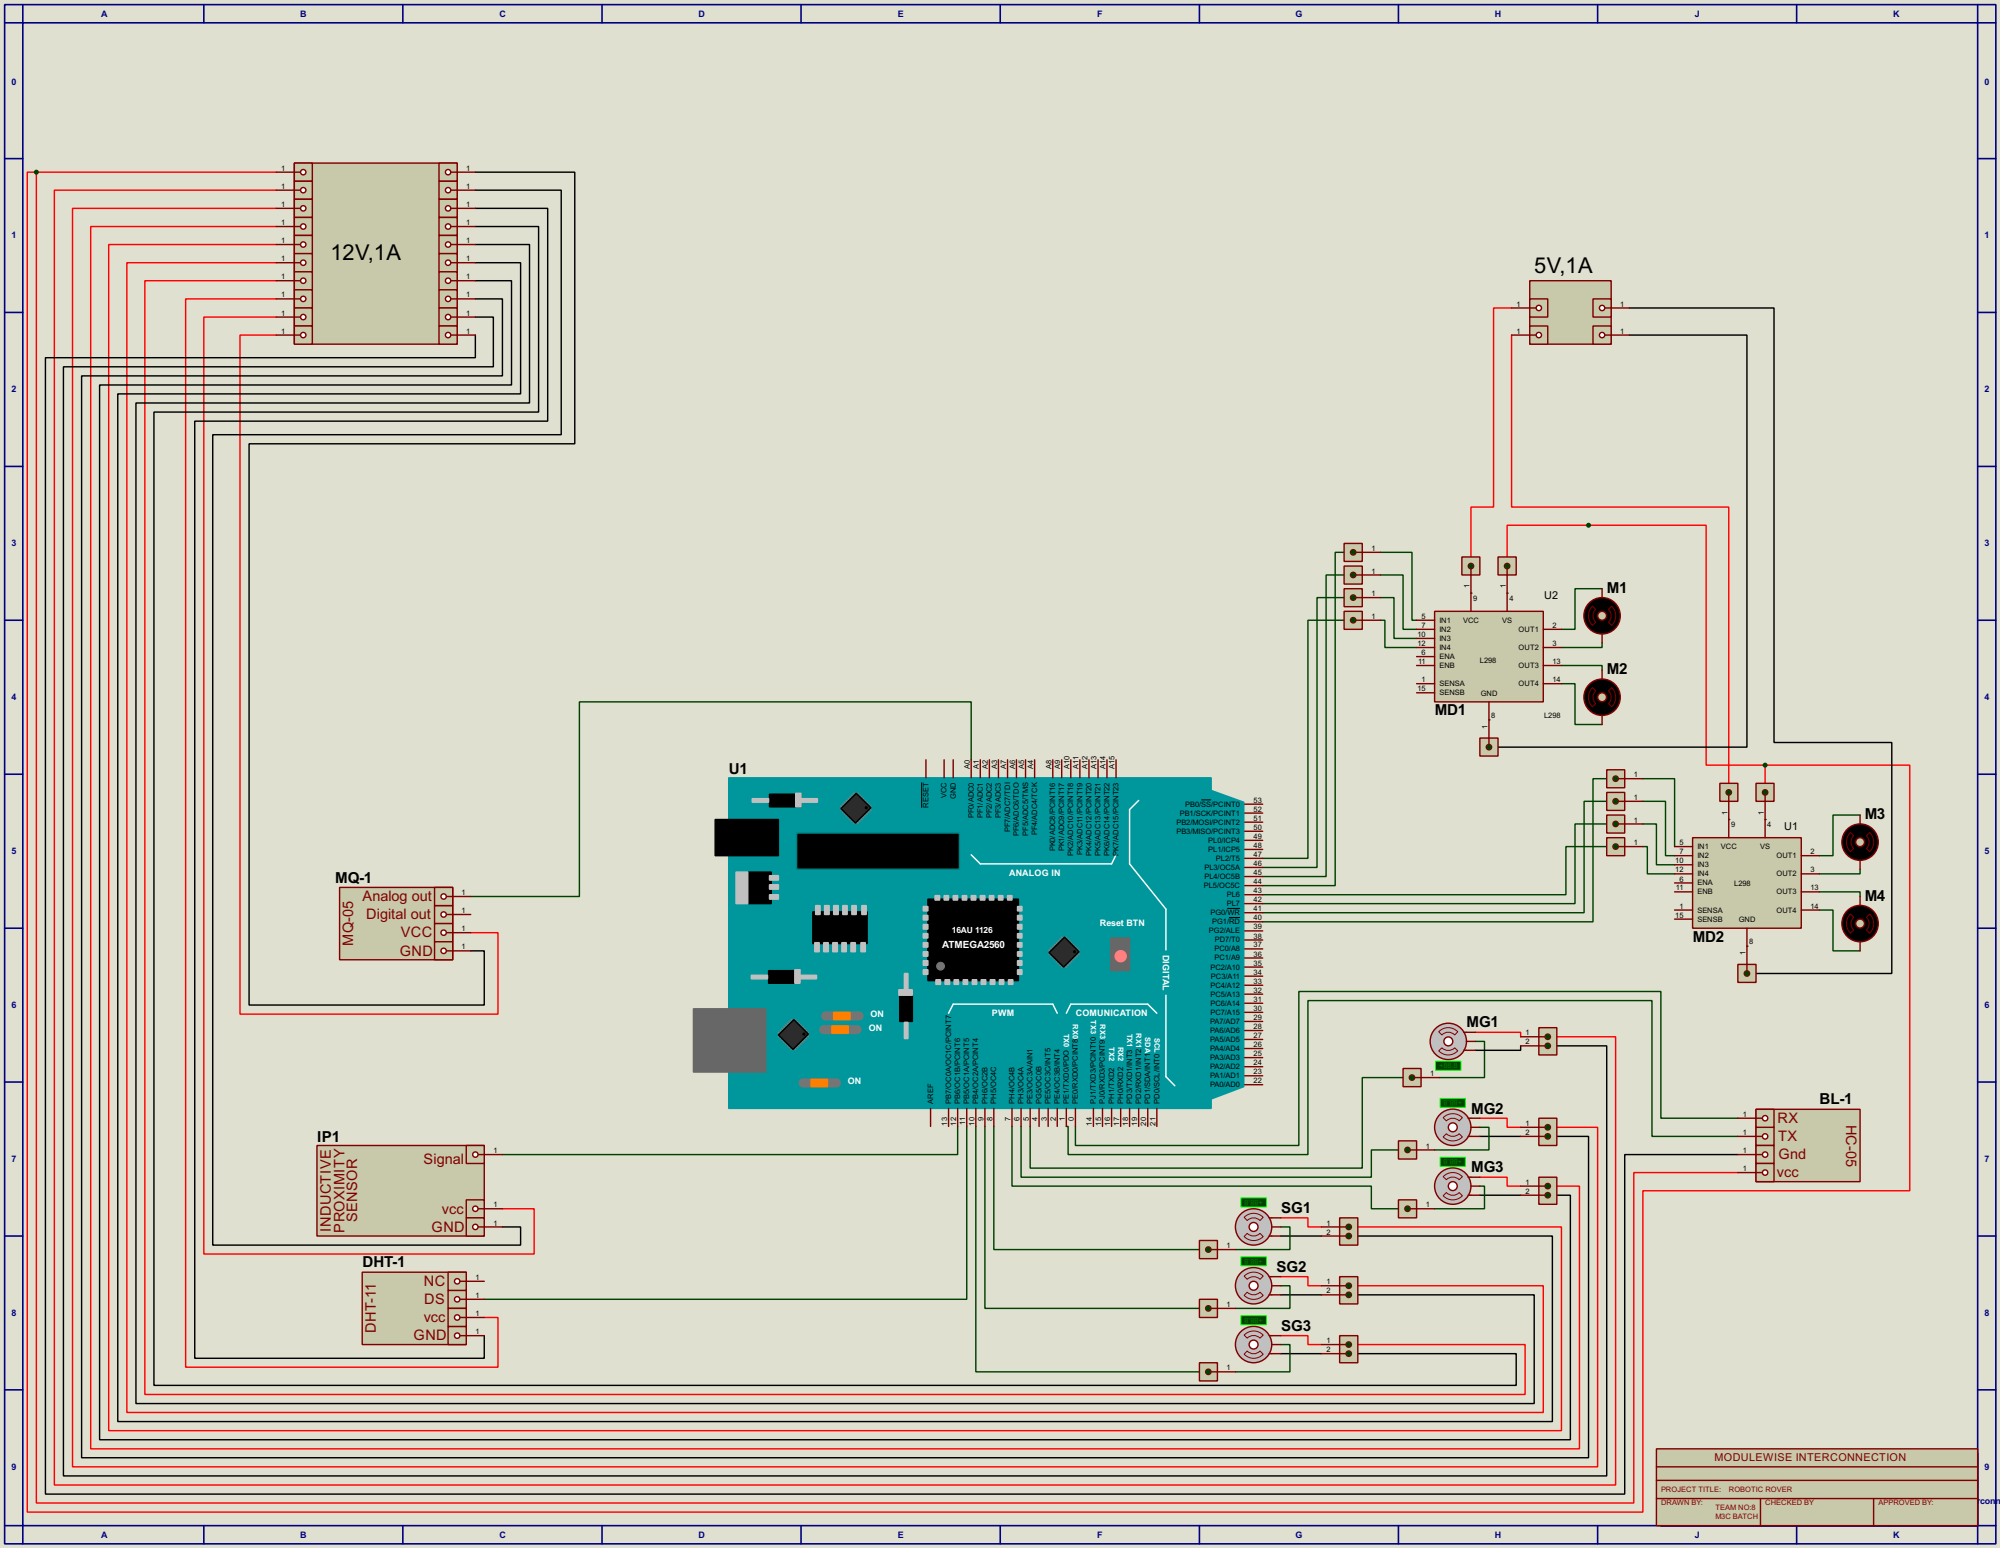
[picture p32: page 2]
PATH:; C:\Users\DELL\Desktop\Manoj\sem v3 final\Modelwise Interconnection\MODELWISE INTERCONNECTION.pdsprj 1; 1 REV:@REV; TIME: 06:44:24 AM; VCC GND; Digital out; Analog out; vcc; Gnd; 1 1 vcc; GND; T-11 DHT-1; Signal; TIV; XIMIT; ENA; OUT1; 2 OUT2; 3 ENB; OUT3; 13 OUT4; SENSA; SENSB; 4 VCC; PWM; COMUNICATION; DIGITAL; ANALOG IN; ATMEGA2560; SDA; SCL; Reset BTN; PD0/SCL/INT0; 21 PD1/SDA/INT1; 20 PD2/RXD1/INT2 19 PD3/TXD1/INT3 18 PH0/RXD2 17 PH1/TXD2; 16 PJ0/RXD3/PCINT9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

RESET VCC GND

www.TheEngineeringProjects.com
Arduino Mega 2560

MODULEWISE INTERCONNECTION
PAGE: MODELWISE INTERCONNECTION.pdsprj

DESIGN TITLE: MODELWISE INTERCONNECTION.pdsprj

D1

D2

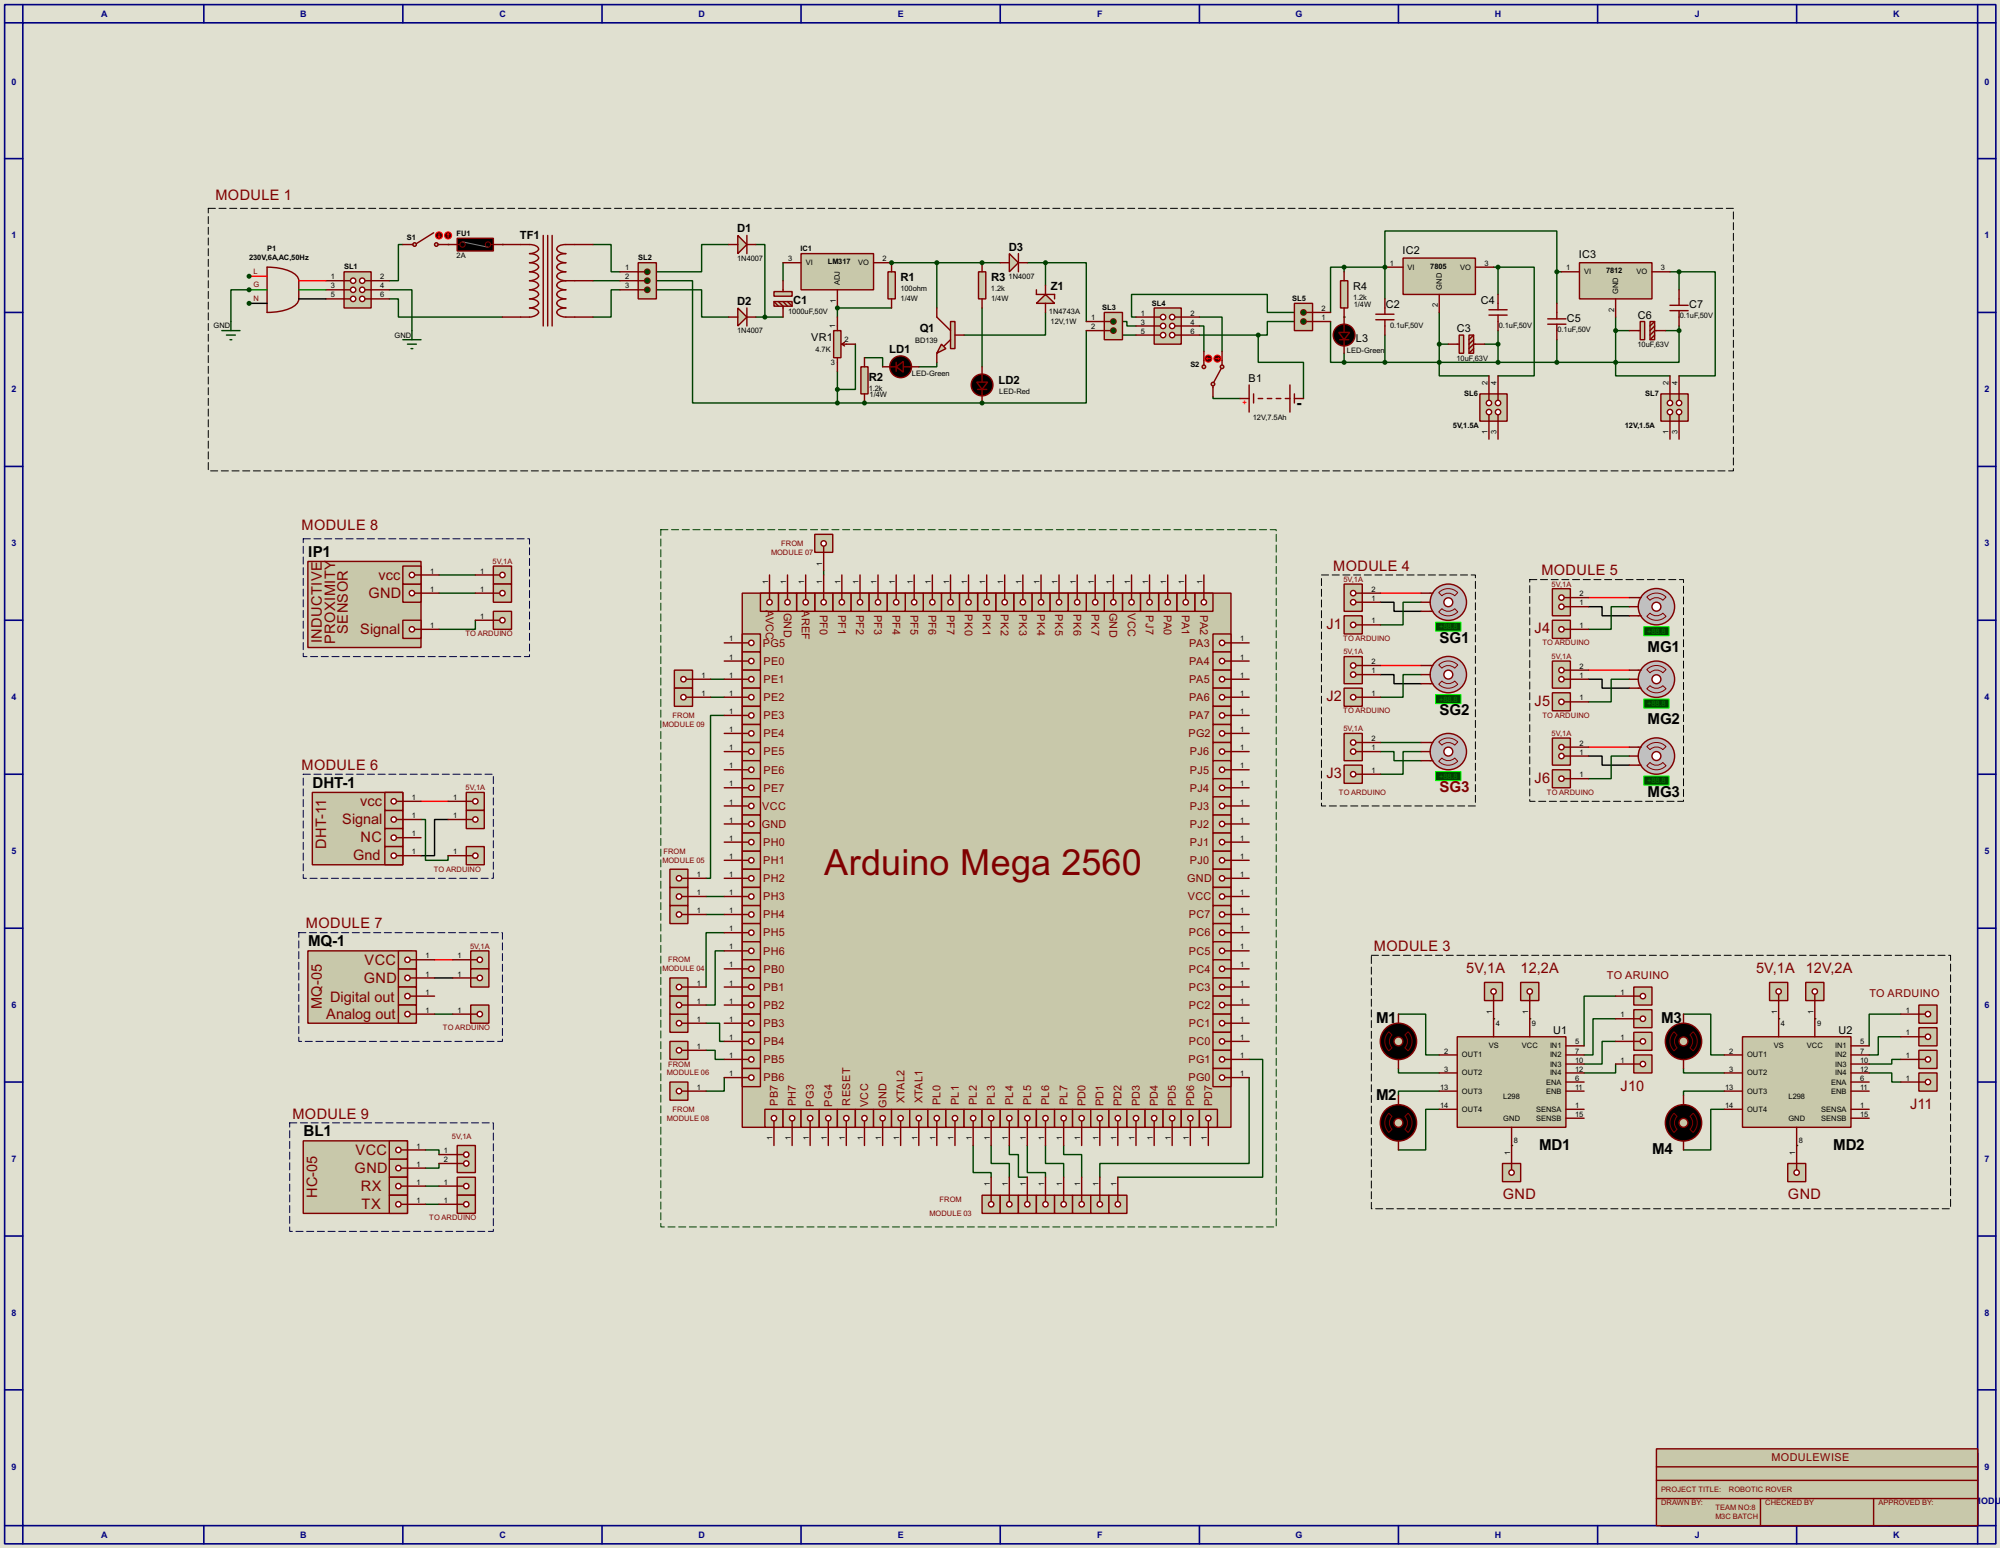
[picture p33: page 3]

DESIGN TITLE: MODULEWISE.pdsprj

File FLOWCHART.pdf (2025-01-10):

## dht DHT

## int temp

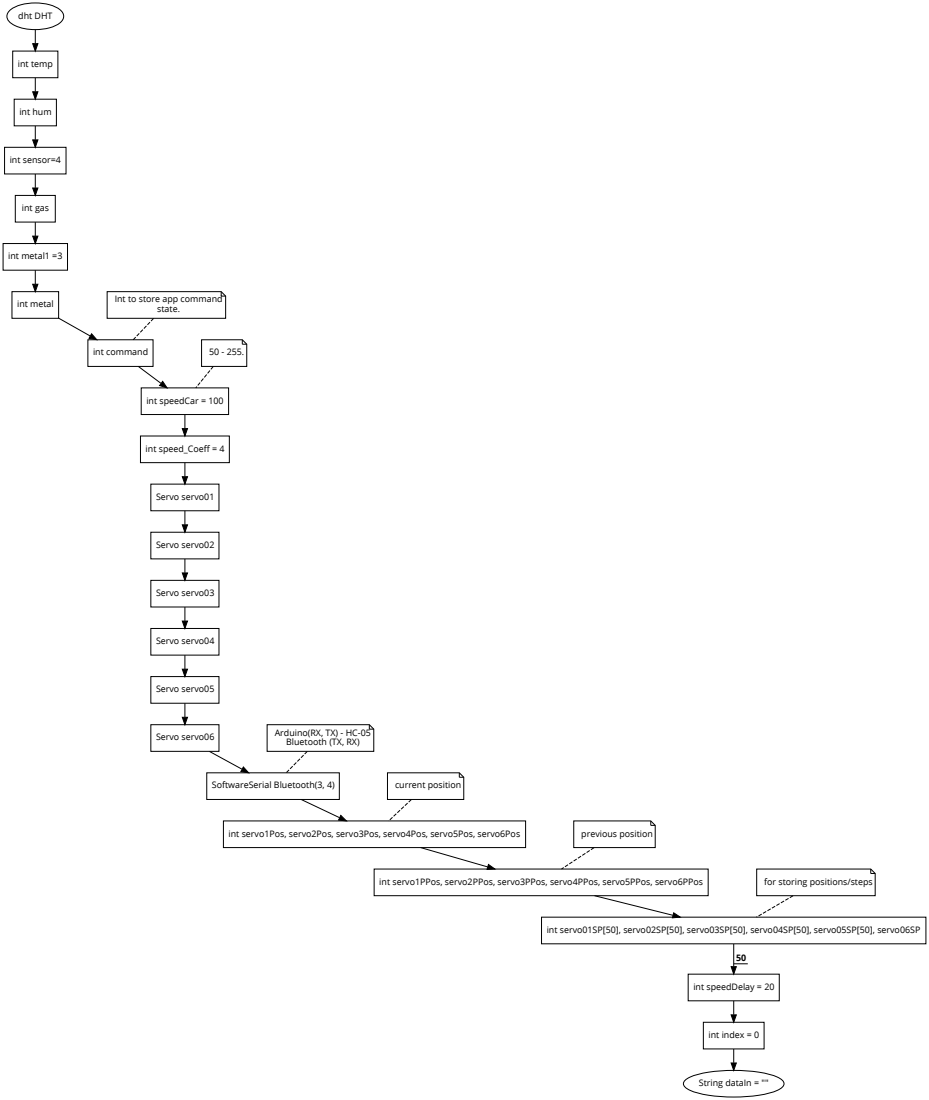
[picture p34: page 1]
int hum; int sensor=4; int gas; int metal1 =3; int metal; int command; int speedCar = 100; int speed_Coeff = 4; Servo servo01; Servo servo02; Servo servo03; Servo servo04; Servo servo05; Servo servo06; SoftwareSerial Bluetooth(3, 4); int servo1Pos, servo2Pos, servo3Pos, servo4Pos, servo5Pos, servo6Pos; int servo1PPos, servo2PPos, servo3PPos, servo4PPos, servo5PPos, servo6PPos; int servo01SP[50], servo02SP[50], servo03SP[50], servo04SP[50], servo05SP[50], servo06SP; int speedDelay = 20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

Int to store app command

Arduino(RX, TX) - HC-05
Bluetooth (TX, RX)

for storing positions/steps

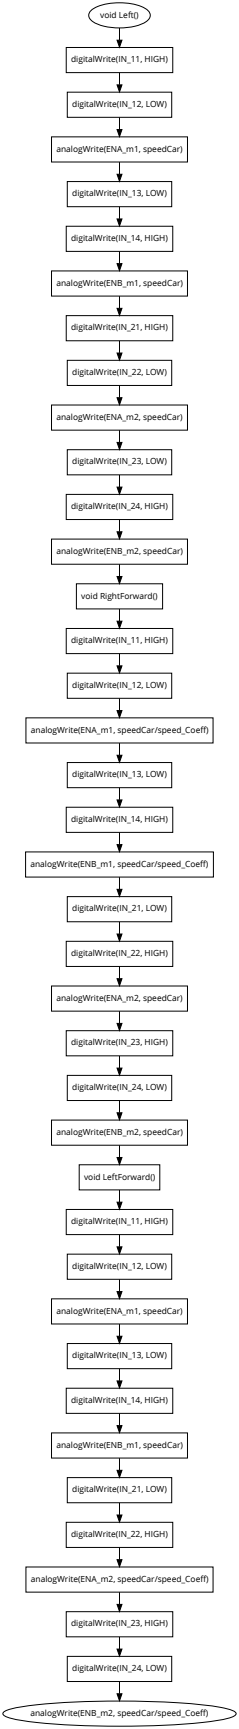
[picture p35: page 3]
void Left(); digitalWrite(IN_11, HIGH); digitalWrite(IN_12, LOW); analogWrite(ENA_m1, speedCar); digitalWrite(IN_13, LOW); digitalWrite(IN_14, HIGH); analogWrite(ENB_m1, speedCar); digitalWrite(IN_21, HIGH); digitalWrite(IN_22, LOW); analogWrite(ENA_m2, speedCar); digitalWrite(IN_23, LOW); digitalWrite(IN_24, HIGH); analogWrite(ENB_m2, speedCar); void RightForward(); analogWrite(ENA_m1, speedCar/speed_Coeff); analogWrite(ENB_m1, speedCar/speed_Coeff); digitalWrite(IN_21, LOW)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

### True

### False

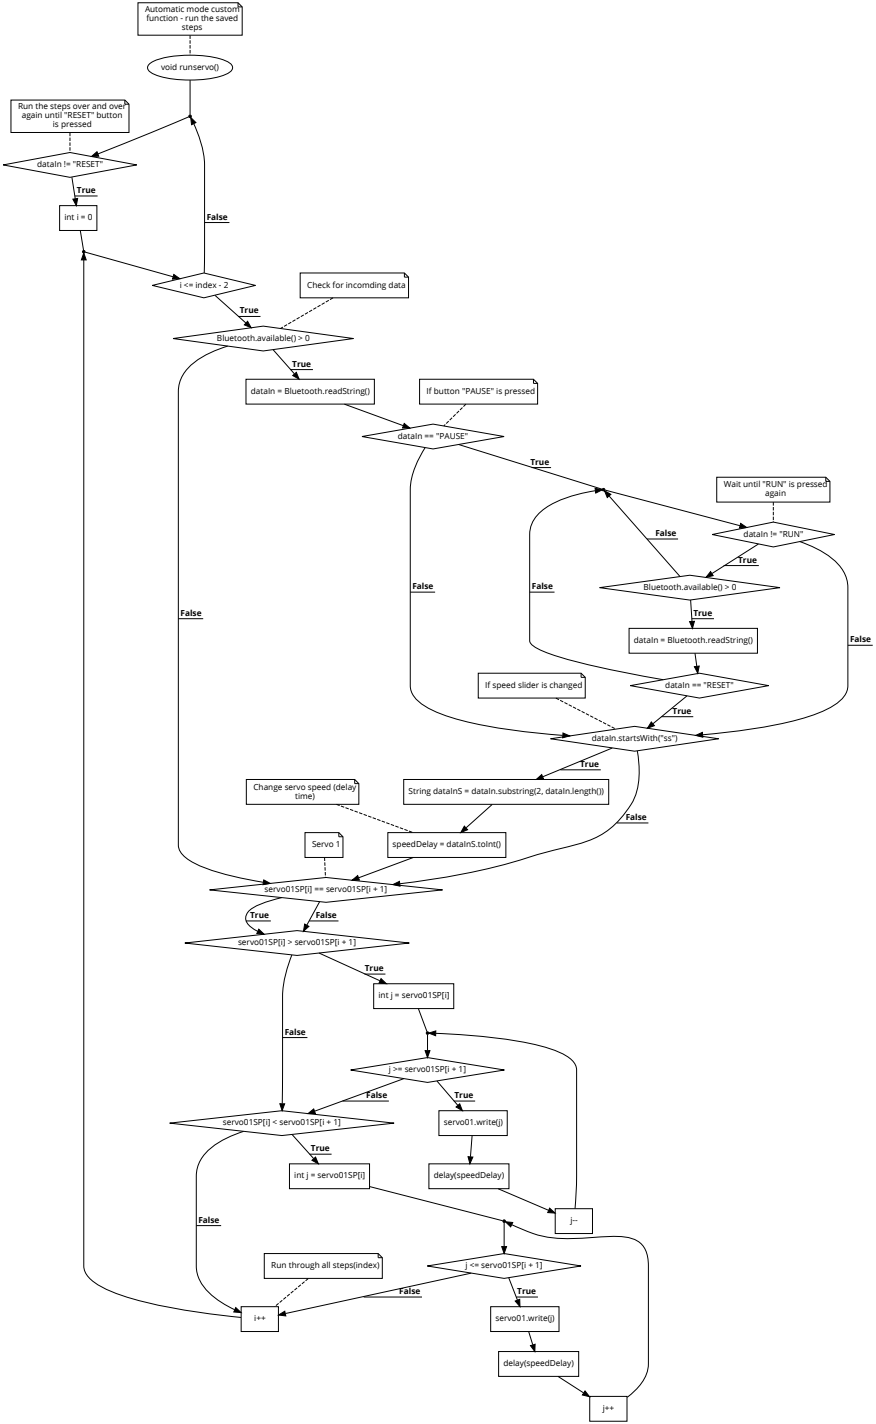
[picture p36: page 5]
void runservo(); dataIn != "RESET"; int i = 0; i <= index - 2; Bluetooth.available() > 0; True; servo01SP[i] == servo01SP[i + 1]; False; dataIn == "PAUSE"; dataIn != "RUN"; dataIn == "RESET"; servo01SP[i] > servo01SP[i + 1]; int j = servo01SP[i]; servo01SP[i] < servo01SP[i + 1]; j >= servo01SP[i + 1]; servo01.write(j); delay(speedDelay); j <= servo01SP[i + 1]; time); again; steps; Servo 1

Automatic mode custom
function - run the saved

Run the steps over and over
again until "RESET" button
is pressed

Check for incomding data

dataIn = Bluetooth.readString()

If button "PAUSE" is pressed

Wait until "RUN" is pressed

If speed slider is changed

dataIn.startsWith("ss")

Change servo speed (delay

String dataInS = dataIn.substring(2, dataIn.length())

speedDelay = dataInS.toInt()

Run through all steps(index)

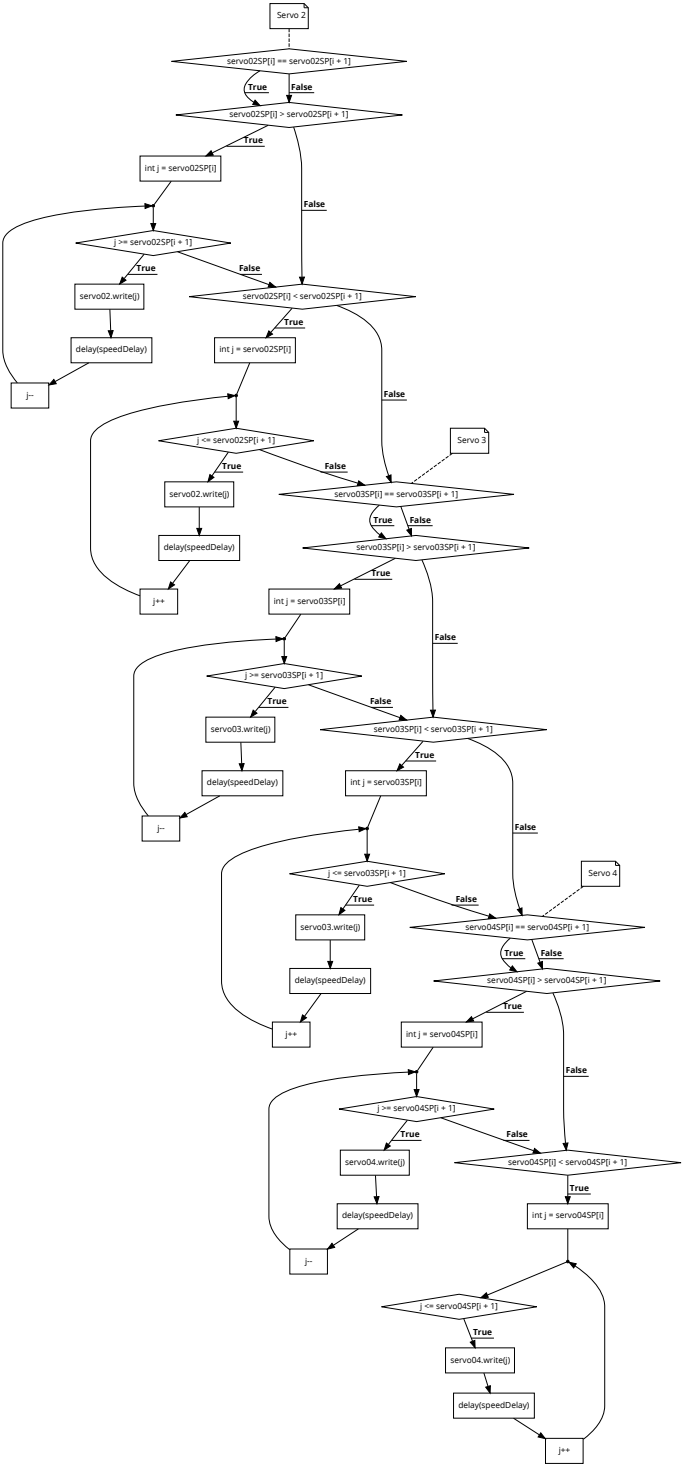
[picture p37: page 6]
servo02SP[i] == servo02SP[i + 1]; servo02SP[i] > servo02SP[i + 1]; True; False; int j = servo02SP[i]; servo02SP[i] < servo02SP[i + 1]; j >= servo02SP[i + 1]; servo02.write(j); delay(speedDelay); servo03SP[i] == servo03SP[i + 1]; j <= servo02SP[i + 1]; servo03SP[i] > servo03SP[i + 1]; int j = servo03SP[i]; servo03SP[i] < servo03SP[i + 1]; j >= servo03SP[i + 1]; servo03.write(j); servo04SP[i] == servo04SP[i + 1]; j <= servo03SP[i + 1]; servo04SP[i] > servo04SP[i + 1]; int j = servo04SP[i]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

# servo05SP[i] == servo05SP[i + 1]

# servo05SP[i] > servo05SP[i + 1]

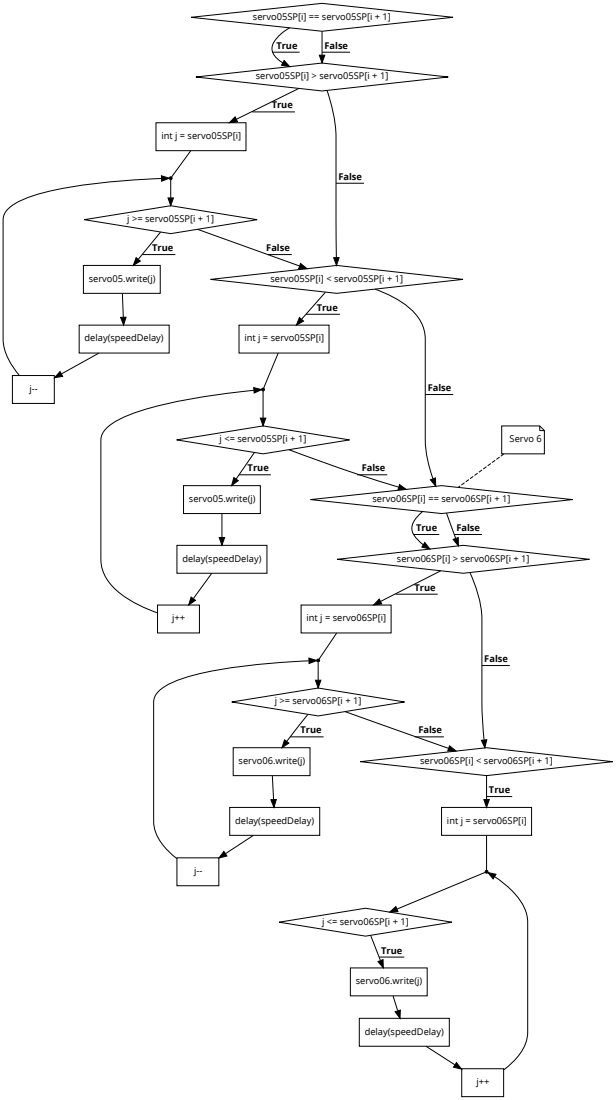
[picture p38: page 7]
True; False; int j = servo05SP[i]; servo05SP[i] < servo05SP[i + 1]; j >= servo05SP[i + 1]; servo05.write(j); delay(speedDelay); servo06SP[i] == servo06SP[i + 1]; j <= servo05SP[i + 1]; servo06SP[i] > servo06SP[i + 1]; int j = servo06SP[i]; servo06SP[i] < servo06SP[i + 1]; j >= servo06SP[i + 1]; servo06.write(j); j <= servo06SP[i + 1]; Servo 6

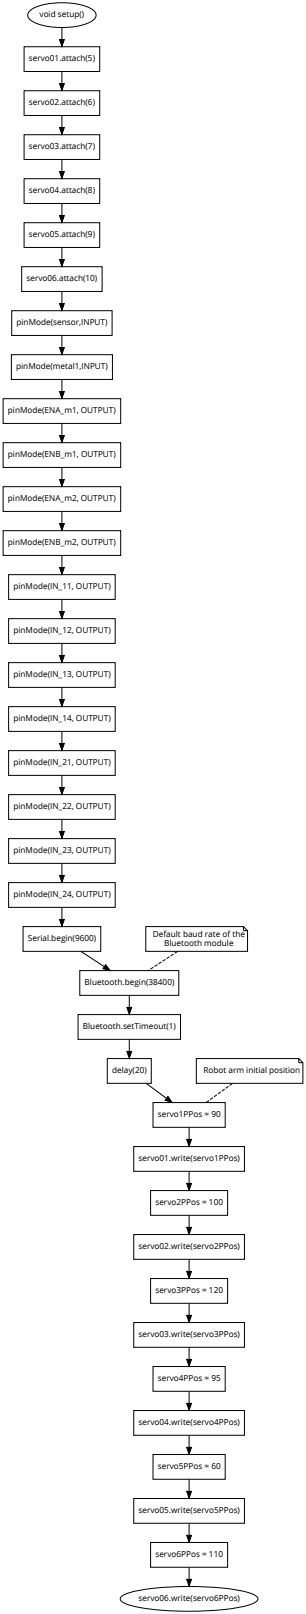
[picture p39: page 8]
void setup(); servo01.attach(5); servo02.attach(6); servo03.attach(7); servo04.attach(8); servo05.attach(9); servo06.attach(10); pinMode(metal1,INPUT); pinMode(ENA_m1, OUTPUT); pinMode(ENB_m1, OUTPUT); pinMode(ENA_m2, OUTPUT); pinMode(ENB_m2, OUTPUT); pinMode(IN_11, OUTPUT); pinMode(IN_12, OUTPUT); pinMode(IN_13, OUTPUT); pinMode(IN_14, OUTPUT); pinMode(IN_21, OUTPUT); pinMode(IN_22, OUTPUT); pinMode(IN_23, OUTPUT); pinMode(IN_24, OUTPUT); Serial.begin(9600); Bluetooth.begin(38400)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

pinMode(sensor,INPUT)

Default baud rate of the
Bluetooth module

Robot arm initial position

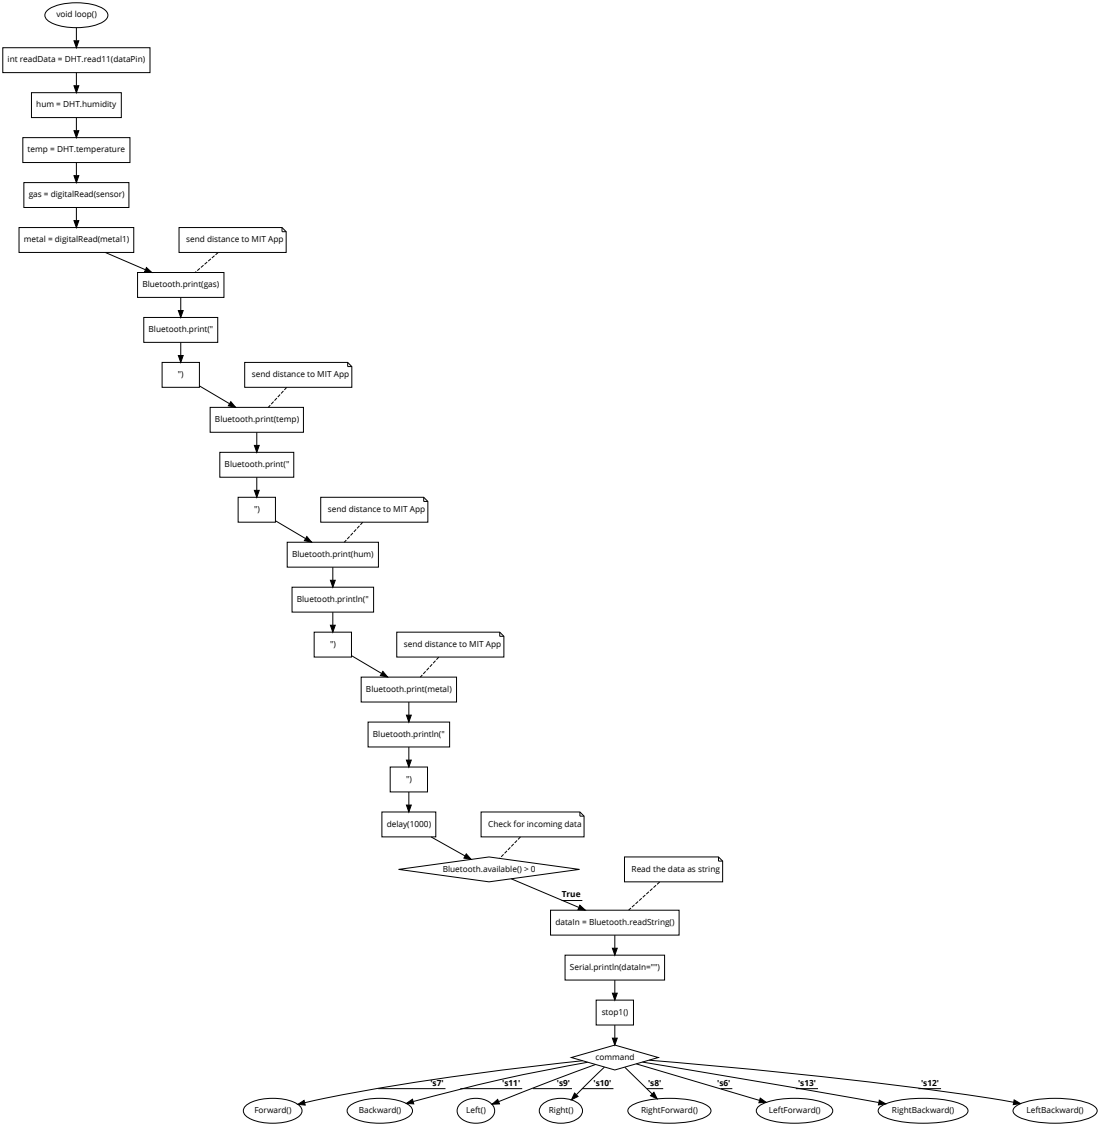
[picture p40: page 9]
void loop(); metal = digitalRead(metal1); Bluetooth.print("; Bluetooth.println("; delay(1000); Bluetooth.available() > 0; True; stop1(); command; Forward(); Backward(); Left(); Right(); RightForward(); LeftForward(); RightBackward(); LeftBackward()

int readData = DHT.read11(dataPin)

hum = DHT.humidity

temp = DHT.temperature

gas = digitalRead(sensor)

send distance to MIT App

Bluetooth.print(gas)

Bluetooth.print(temp)

Bluetooth.print(hum)

Bluetooth.print(metal)

Check for incoming data

Read the data as string

dataIn = Bluetooth.readString()

Serial.println(dataIn="")

# dataIn.startsWith("sa")
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

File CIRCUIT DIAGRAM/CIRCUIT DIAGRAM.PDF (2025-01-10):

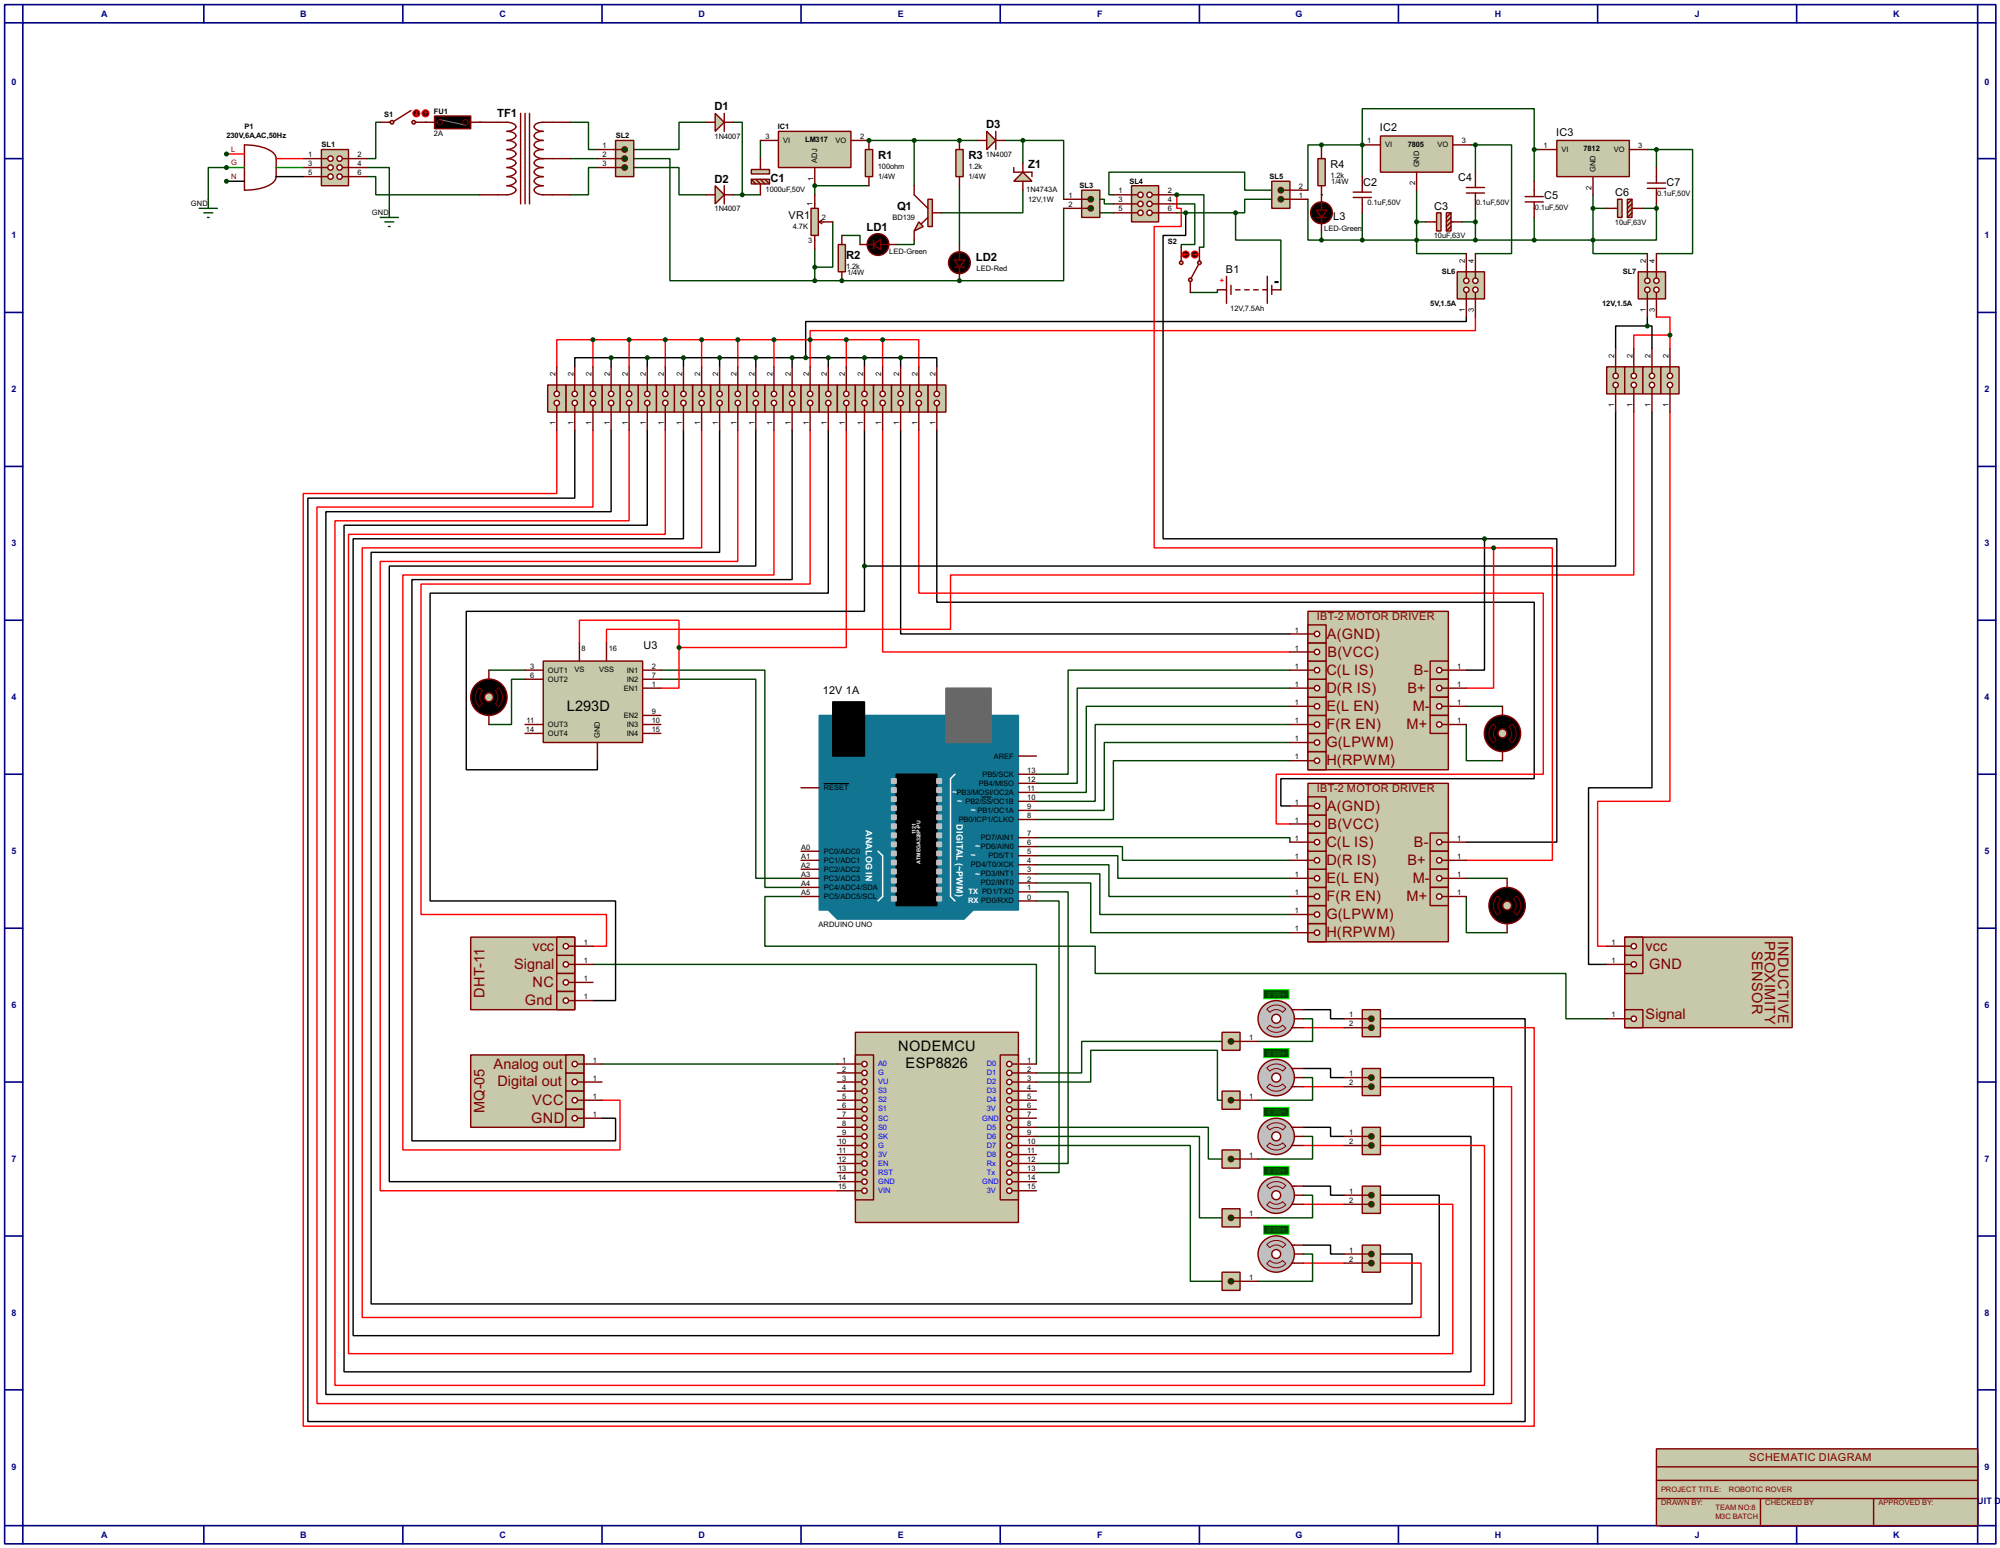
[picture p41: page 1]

10 PB3/MOSI/OC2A
9 PB2/SS/OC1B
8 PB1/OC1A

5 PD6/AIN0
4 PD5/T1
3 PD4/T0/XCK
2 PD3/INT1
1 PD2/INT0
0 PD1/TXD

vcc Signal NC Gnd

SCHEMATIC DIAGRAM FILE NAME: | DATE:

PAGE: CIRCUIT DIAGRAM.pdsprj 19-12-2019

DESIGN TITLE: CIRCUIT DIAGRAM.pdsprj PROJECT TITLE: ROBOTIC ROVER

PATH: C:\Users\DELL\Desktop\MSD\SEM 6\Cricuit Diagram\CIRCUIT DIAGRAM.pdsprj 1 DRAWN BY: TEAM NO:8 M3C BATCH BY: @AUTHOR | CHECKED BY | APPROVED BY: | TIME: 06:14:06 PM of 1 REV:@REV

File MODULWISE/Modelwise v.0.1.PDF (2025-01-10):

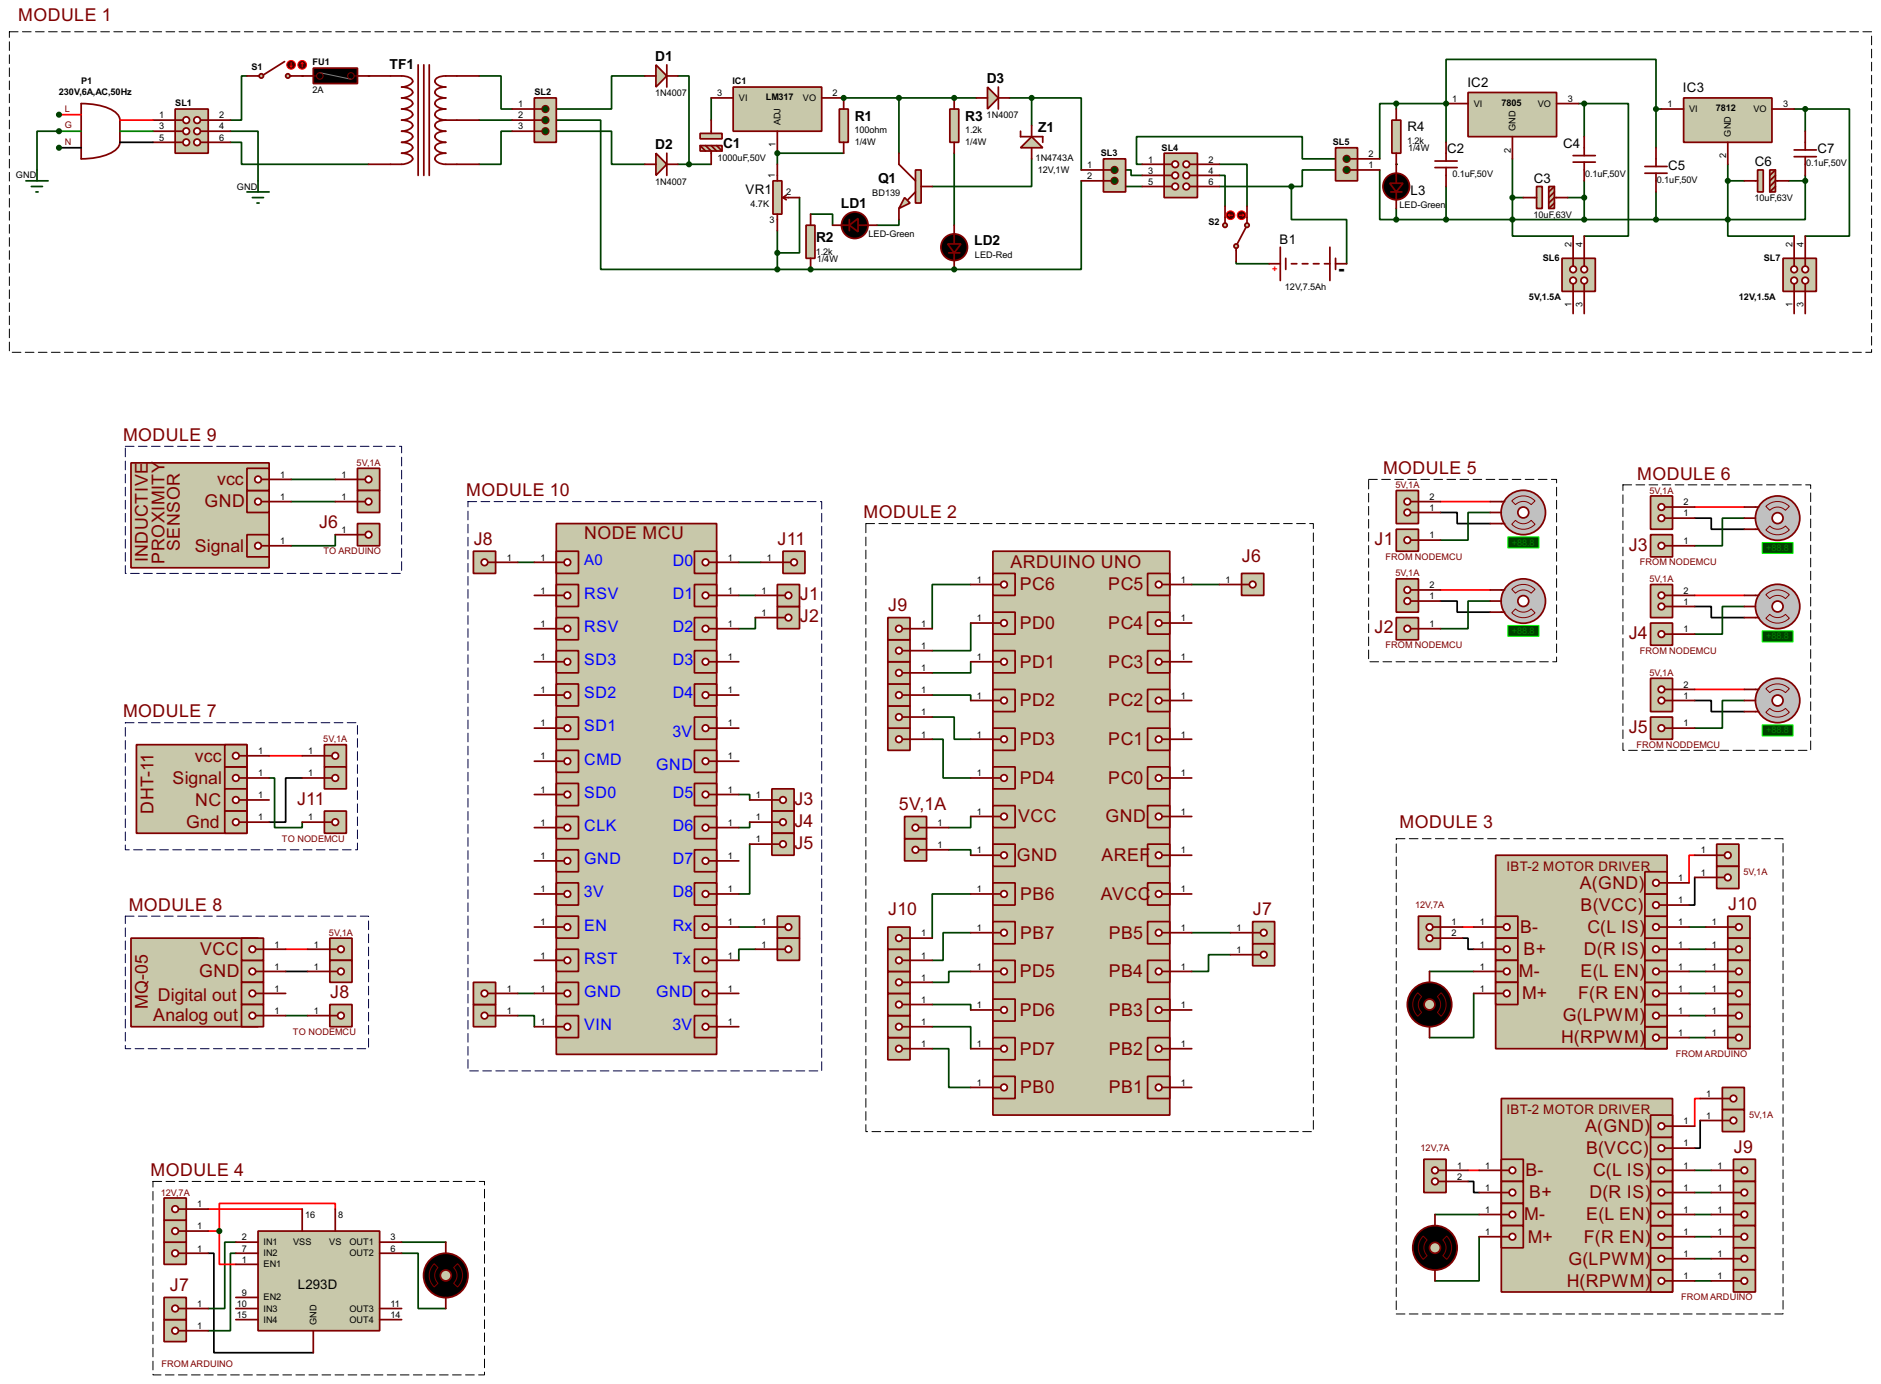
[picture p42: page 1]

vcc Signal NC Gnd

7 | 3 OUT2 6

2 | OUT1 IN1 VS
